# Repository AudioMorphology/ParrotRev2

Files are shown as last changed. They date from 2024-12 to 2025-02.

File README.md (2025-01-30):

# Parrot

##  Overview

Parrot is a 12hp Eurorack digital delay powered by a Raspberry Pi Pico microcontroller.

The objective is to provide a CD-Quality audio delay  / reverb effect, with a reasonably 
low BOM count

It utilises an 8Mb x 8-Bit (64mBit) PSRAM Memory chip (the AP6404L), and the whole of
this is treated as a 2Mb x 32-Bit audio buffer. This means that we can wrap the read and 
write pointers  with a simple logical &. 

2Mb x 32-Bit is 1Mb at 32-Bit Stereo. At a 48kHz sample rate, this gives a maximum delay 
time of 1,048,576 / 48,000 = 21.84 seconds 

The ADC and DAC ICs communicate over the i2S protocol, which is handled by custom PIO
functions.

They are actually 24-Bit devices with the data being transmitted left-justified in 32-Bit 
frames, so I am rightshifting to get 24-Bit Integers, then converting these to normalised
floats in the range -1.0 to +1.0 then, after processing it does the same in reverse before 
sending the audio data out to the DAC. 

Reading and writing to the PSRAM buffer is double-buffered using DMA calls from the I2S
interface.

It uses two PIO State machines:

PIO0 for SPI
PIO1 for I2S

The ADC and DAC utilises the low-cost and readily-available I2S modules, which have the 
advantages of already including various ancilliary components, which further reduces the
component count and complexity.

## NOTICE

This code incorporates and acknowledges the following:

### rp2040-psram Copyright © 2023 Ian Scott

rp2040-psram is a header-only library, which implements the SPI protocol using the rp2040 PIO
rather than the in-built SPI interface. This gives far better performance for PSRAM SPI peripherals

### i2s Copyright © 2022 Daniel Collins

These functions implement the I2S protocol using the rp2040 PIO. and utilise interrupt-driven
DMA double-buffering for Audio I/O.

### Elements of hardware design Copyright © 2012 Emilie Gillet (emilie.o.gillet@gmail.com)

The input and output buffer circuitry was taken directly from Clouds:
https://github.com/pichenettes/eurorack/tree/master/clouds/hardware_design/pcb

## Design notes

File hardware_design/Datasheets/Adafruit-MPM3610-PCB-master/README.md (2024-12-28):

## Adafruit MPM3610 3.3V & 5V Buck Converter Breakout PCB

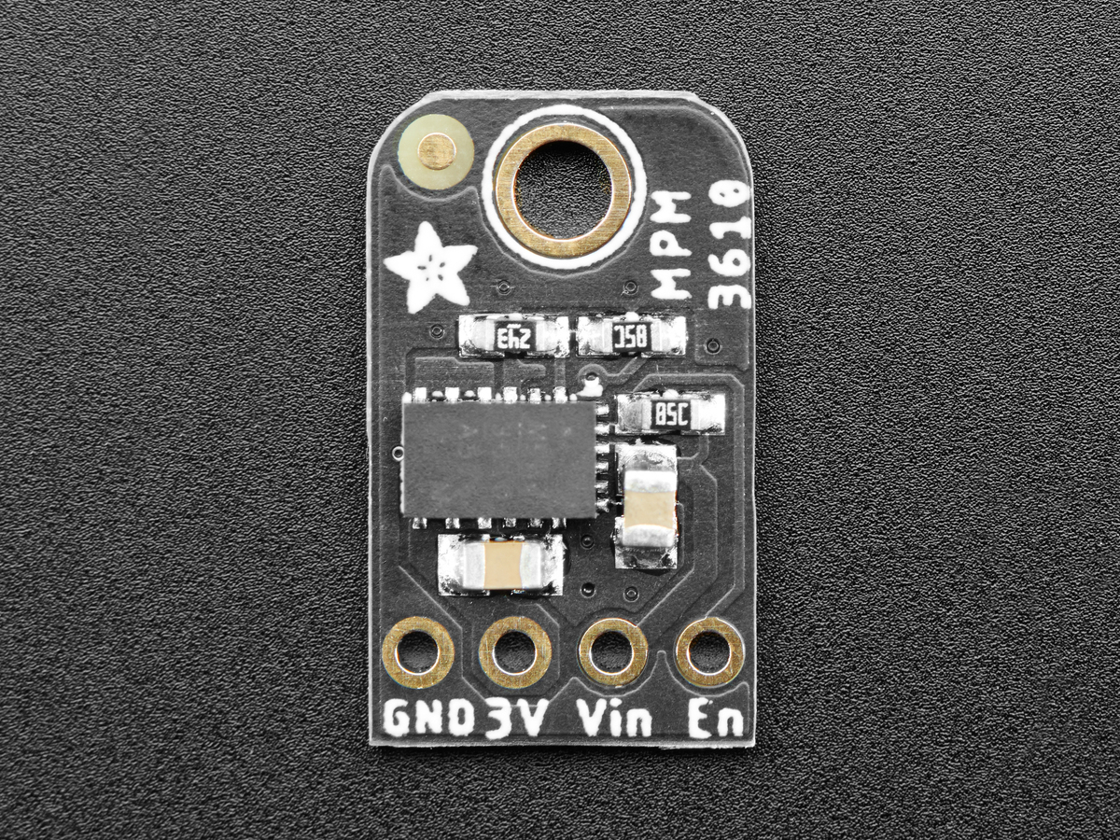
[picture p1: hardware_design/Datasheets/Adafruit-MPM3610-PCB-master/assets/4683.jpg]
<a href="http://www.adafruit.com/products/4683"><br/>
Click here to purchase one from the Adafruit shop</a>

PCB files for the Adafruit MPM3610 3.3V & 5V Buck Converter Breakout.

Format is EagleCAD schematic and board layout
* https://www.adafruit.com/product/4683
* https://www.adafruit.com/product/4739

### Description

Adafruit MPM3610 3.3V and 5V Buck Converter Breakout. The files for both are the same, the only difference is on the 5V version, R1 & R2 are 100K and R3 is 18.7K and on the 3.3V version, R1 & R2 are 75 and R3 is 24K

### License

Adafruit invests time and resources providing this open source design, please support Adafruit and open-source hardware by purchasing products from [Adafruit](https://www.adafruit.com)!

Designed by Limor Fried/Ladyada for Adafruit Industries.

Creative Commons Attribution/Share-Alike, all text above must be included in any redistribution.
See license.txt for additional details.

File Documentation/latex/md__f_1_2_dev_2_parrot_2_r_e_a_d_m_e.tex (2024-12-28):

\chapter{Parrot}
\hypertarget{md__f_1_2_dev_2_parrot_2_r_e_a_d_m_e}{}\label{md__f_1_2_dev_2_parrot_2_r_e_a_d_m_e}\index{Parrot@{Parrot}}
\label{md__f_1_2_dev_2_parrot_2_r_e_a_d_m_e_autotoc_md0}%
\Hypertarget{md__f_1_2_dev_2_parrot_2_r_e_a_d_m_e_autotoc_md0}%
 \hypertarget{md__f_1_2_dev_2_parrot_2_r_e_a_d_m_e_autotoc_md1}{}\doxysection{\texorpdfstring{Overview}{Overview}}\label{md__f_1_2_dev_2_parrot_2_r_e_a_d_m_e_autotoc_md1}
Parrot is a 12hp Eurorack digital delay powered by a Raspberry Pi Pico microcontroller.

The objective is to provide a CD-\/\+Quality audio delay / reverb effect, with a reasonably low BOM count

It utilises an 8Mb x 8-\/Bit (64m\+Bit) PSRAM Memory chip (the AP6404L), and the whole of this is treated as a 2Mb x 32-\/Bit audio buffer. This means that we can wrap the read and write pointers with a simple logical \&.

2Mb x 32-\/Bit is 1Mb at 32-\/Bit Stereo. At a 48k\+Hz sample rate, this gives a maximum delay time of 1,048,576 / 48,000 = 21.\+84 seconds

The ADC and DAC ICs communicate over the i2S protocol, which is handled by custom PIO functions.

Reading and writing to the PSRAM buffer is double-\/buffered using DMA calls from the I2S interface.

It uses two PIO State machines\+:

PIO0 for SPI PIO1 for I2S

The ADC and DAC utilises the low-\/cost and readily-\/available I2S modules, which have the advantages of already including various ancilliary components, which further reduces the component count and complexity.\hypertarget{md__f_1_2_dev_2_parrot_2_r_e_a_d_m_e_autotoc_md2}{}\doxysection{\texorpdfstring{NOTICE}{NOTICE}}\label{md__f_1_2_dev_2_parrot_2_r_e_a_d_m_e_autotoc_md2}
This code incorporates and acknowledges the following\+:\hypertarget{md__f_1_2_dev_2_parrot_2_r_e_a_d_m_e_autotoc_md3}{}\doxysubsection{\texorpdfstring{rp2040-\/psram Copyright © 2023 Ian Scott}{rp2040-\/psram Copyright © 2023 Ian Scott}}\label{md__f_1_2_dev_2_parrot_2_r_e_a_d_m_e_autotoc_md3}
rp2040-\/psram is a header-\/only library, which implements the SPI protocol using the rp2040 PIO rather than the in-\/built SPI interface. This gives far better performance for PSRAM SPI peripherals\hypertarget{md__f_1_2_dev_2_parrot_2_r_e_a_d_m_e_autotoc_md4}{}\doxysubsection{\texorpdfstring{i2s Copyright (c) 2022 Daniel Collins}{i2s Copyright (c) 2022 Daniel Collins}}\label{md__f_1_2_dev_2_parrot_2_r_e_a_d_m_e_autotoc_md4}
These functions implement the I2S protocol using the rp2040 PIO. and utilise interrupt-\/driven DMA double-\/buffering for Audio I/O.\hypertarget{md__f_1_2_dev_2_parrot_2_r_e_a_d_m_e_autotoc_md5}{}\doxysubsection{\texorpdfstring{Elements of hardware design Copyright 2012 Emilie Gillet (\href{mailto:emilie.o.gillet@gmail.com}{\texttt{ emilie.\+o.\+gillet@gmail.\+com}})}{Elements of hardware design Copyright 2012 Emilie Gillet (\href{mailto:emilie.o.gillet@gmail.com}{\texttt{ emilie.\+o.\+gillet@gmail.\+com}})}}\label{md__f_1_2_dev_2_parrot_2_r_e_a_d_m_e_autotoc_md5}
The input and output buffer circuitry was taken directly from Clouds\+: \href{https://github.com/pichenettes/eurorack/tree/master/clouds/hardware_design/pcb}{\texttt{ https\+://github.\+com/pichenettes/eurorack/tree/master/clouds/hardware\+\_\+design/pcb}}

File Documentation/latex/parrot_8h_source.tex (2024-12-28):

\doxysection{parrot.\+h}
\hypertarget{parrot_8h_source}{}\label{parrot_8h_source}\index{F:/Dev/Parrot/parrot.h@{F:/Dev/Parrot/parrot.h}}
\mbox{\hyperlink{parrot_8h}{Go to the documentation of this file.}}
\begin{DoxyCode}{0}
\DoxyCodeLine{00001\ \textcolor{comment}{/******************************************************************************}}
\DoxyCodeLine{00002\ \textcolor{comment}{}}
\DoxyCodeLine{00003\ \textcolor{comment}{parrot}}
\DoxyCodeLine{00004\ \textcolor{comment}{}}
\DoxyCodeLine{00005\ \textcolor{comment}{Copyright\ ©\ 2024\ Richard\ R.\ Goodwin\ /\ Audio\ Morphology\ Ltd.}}
\DoxyCodeLine{00006\ \textcolor{comment}{}}
\DoxyCodeLine{00007\ \textcolor{comment}{Permission\ is\ hereby\ granted,\ free\ of\ charge,\ to\ any\ person\ obtaining\ a\ copy\ of}}
\DoxyCodeLine{00008\ \textcolor{comment}{this\ software\ and\ associated\ documentation\ files\ (the\ “Software”),\ to\ deal\ in}}
\DoxyCodeLine{00009\ \textcolor{comment}{the\ Software\ without\ restriction,\ including\ without\ limitation\ the\ rights\ to}}
\DoxyCodeLine{00010\ \textcolor{comment}{use,\ copy,\ modify,\ merge,\ publish,\ distribute,\ sublicense,\ and/or\ sell\ copies}}
\DoxyCodeLine{00011\ \textcolor{comment}{of\ the\ Software,\ and\ to\ permit\ persons\ to\ whom\ the\ Software\ is\ furnished\ to\ do}}
\DoxyCodeLine{00012\ \textcolor{comment}{so,\ subject\ to\ the\ following\ conditions:}}
\DoxyCodeLine{00013\ \textcolor{comment}{}}
\DoxyCodeLine{00014\ \textcolor{comment}{The\ above\ copyright\ notice\ and\ this\ permission\ notice\ shall\ be\ included\ in\ all}}
\DoxyCodeLine{00015\ \textcolor{comment}{copies\ or\ substantial\ portions\ of\ the\ Software.}}
\DoxyCodeLine{00016\ \textcolor{comment}{}}
\DoxyCodeLine{00017\ \textcolor{comment}{THE\ SOFTWARE\ IS\ PROVIDED\ “AS\ IS”,\ WITHOUT\ WARRANTY\ OF\ ANY\ KIND,\ EXPRESS\ OR}}
\DoxyCodeLine{00018\ \textcolor{comment}{IMPLIED,\ INCLUDING\ BUT\ NOT\ LIMITED\ TO\ THE\ WARRANTIES\ OF\ MERCHANTABILITY,}}
\DoxyCodeLine{00019\ \textcolor{comment}{FITNESS\ FOR\ A\ PARTICULAR\ PURPOSE\ AND\ NONINFRINGEMENT.\ IN\ NO\ EVENT\ SHALL\ THE}}
\DoxyCodeLine{00020\ \textcolor{comment}{AUTHORS\ OR\ COPYRIGHT\ HOLDERS\ BE\ LIABLE\ FOR\ ANY\ CLAIM,\ DAMAGES\ OR\ OTHER}}
\DoxyCodeLine{00021\ \textcolor{comment}{LIABILITY,\ WHETHER\ IN\ AN\ ACTION\ OF\ CONTRACT,\ TORT\ OR\ OTHERWISE,\ ARISING\ FROM,}}
\DoxyCodeLine{00022\ \textcolor{comment}{OUT\ OF\ OR\ IN\ CONNECTION\ WITH\ THE\ SOFTWARE\ OR\ THE\ USE\ OR\ OTHER\ DEALINGS\ IN\ THE}}
\DoxyCodeLine{00023\ \textcolor{comment}{SOFTWARE.}}
\DoxyCodeLine{00024\ \textcolor{comment}{}}
\DoxyCodeLine{00025\ \textcolor{comment}{******************************************************************************/}}
\DoxyCodeLine{00031\ \textcolor{preprocessor}{\#ifndef\ PARROT\_H}}
\DoxyCodeLine{00032\ \textcolor{preprocessor}{\#define\ PARROT\_H}}
\DoxyCodeLine{00033\ \textcolor{preprocessor}{\#include\ "{}psram\_spi.h"{}}}
\DoxyCodeLine{00034\ \textcolor{comment}{//\ To\ Do\ -\/\ is\ it\ OK\ to\ hard\ code\ these,\ or\ should\ they\ be\ }}
\DoxyCodeLine{00035\ \textcolor{comment}{//\ dynamically\ assigned\ from\ an\ alarm\ \&\ IRQ\ pool?}}
\DoxyCodeLine{00036\ \textcolor{preprocessor}{\#define\ ALARM\_NUM\ 1}}
\DoxyCodeLine{00037\ \textcolor{preprocessor}{\#define\ ALARM\_IRQ\ TIMER\_IRQ\_1}}
\DoxyCodeLine{00044\ \textcolor{keyword}{typedef}\ \textcolor{keywordtype}{signed}\ \textcolor{keywordtype}{int}\ \mbox{\hyperlink{parrot_8h_a6bdff0bc03d24ec80e07d29f92a4d8a8}{s15x16}};}
\DoxyCodeLine{00045\ \textcolor{preprocessor}{\#define\ muls15x16(a,b)\ ((s15x16)((((\ signed\ long\ long\ )(a))*((\ signed\ long\ long\ )(b)))>>16))\ }\textcolor{comment}{//multiply\ two\ fixed\ 16:16}}
\DoxyCodeLine{00046\ \textcolor{preprocessor}{\#define\ float\_to\_s15x16(a)\ ((s15x16)((a)*65536.0))\ }\textcolor{comment}{//\ 2\string^16}}
\DoxyCodeLine{00047\ \textcolor{preprocessor}{\#define\ s15x16\_to\_float(a)\ ((float)(a)/65536.0)}}
\DoxyCodeLine{00048\ \textcolor{preprocessor}{\#define\ s15x16\_to\_int(a)\ \ \ \ ((int)((a)>>16))}}
\DoxyCodeLine{00049\ \textcolor{preprocessor}{\#define\ int\_to\_s15x16(a)\ \ \ \ ((s15x16)((a)<<16))}}
\DoxyCodeLine{00050\ \textcolor{preprocessor}{\#define\ divs15x16(a,b)\ ((s15x16)((((signed\ long\ long)(a)<<16)/(b))))\ }}
\DoxyCodeLine{00051\ \textcolor{preprocessor}{\#define\ abss15x16(a)\ abs(a)}}
\DoxyCodeLine{00052\ \textcolor{comment}{//\ and\ for\ 1.14}}
\DoxyCodeLine{00053\ \textcolor{keyword}{typedef}\ \textcolor{keywordtype}{signed}\ \textcolor{keywordtype}{short}\ s1x14\ ;}
\DoxyCodeLine{00054\ \textcolor{preprocessor}{\#define\ muls1x14(a,b)\ ((s1x14)((((int)(a))*((int)(b)))>>14))\ }}
\DoxyCodeLine{00055\ \textcolor{preprocessor}{\#define\ float\_to\_s1x14(a)\ ((s1x14)((a)*16384.0))\ }\textcolor{comment}{//\ 2\string^14}}
\DoxyCodeLine{00056\ \textcolor{preprocessor}{\#define\ s1x14\_to\_float(a)\ ((float)(a)/16384.0)}}
\DoxyCodeLine{00057\ \textcolor{preprocessor}{\#define\ abss1x14(a)\ abs(a)\ }}
\DoxyCodeLine{00058\ \textcolor{preprocessor}{\#define\ divs1x14(a,b)\ ((s1x14)((((signed\ int)(a)<<14)/(b))))\ }}
\DoxyCodeLine{00059\ \textcolor{comment}{//\ Int\ to\ float}}
\DoxyCodeLine{00060\ \textcolor{preprocessor}{\#define\ float\_to\_int(x)\ (((int)\ ((x\ *\ 8388607)\ +\ 8388608.5f))\ -\/\ 8388608)}}
\DoxyCodeLine{00061\ \textcolor{preprocessor}{\#define\ float\_to\_int32(x)\ (((int)\ ((x\ *\ 2147483647)\ +\ 2147483648.5f))\ -\/\ 2147483648)}}
\DoxyCodeLine{00062\ \textcolor{preprocessor}{\#define\ int\_to\_float(x)\ ((((float)\ (x\ +\ 8388608))\ -\/\ 8388608.5f)\ /\ 8388607.f)}}
\DoxyCodeLine{00063\ \textcolor{preprocessor}{\#define\ int32\_to\_float(x)\ ((((float)\ (x\ +\ 2147483648))\ -\/\ 2147483648.5f)\ /\ 2147483648.f)}}
\DoxyCodeLine{00072\ \textcolor{keyword}{union\ }\mbox{\hyperlink{unionu_sample}{uSample}}\ \{}
\DoxyCodeLine{00073\ \ \ \ \ \textcolor{keywordtype}{float}\ fSample;}
\DoxyCodeLine{00074\ \ \ \ \ int32\_t\ iSample;}
\DoxyCodeLine{00075\ \};}
\DoxyCodeLine{00076\ }
\DoxyCodeLine{00077\ \textcolor{comment}{//\ Global\ Variables\ -\/\ Constants}}
\DoxyCodeLine{00078\ \textcolor{keyword}{static}\ \textcolor{keyword}{const}\ \textcolor{keywordtype}{double}\ ClockScale\ =\ 0.04884;\ \ \ \ \ \ \ \textcolor{comment}{//\ (=\ (240-\/40)/4095)\ scales\ the\ internal\ clock\ BPM\ from\ 40\ to\ 240BPM}}
\DoxyCodeLine{00079\ \textcolor{keyword}{static}\ \textcolor{keyword}{const}\ uint\ Clock\_MA\_Len\ =\ 3;\ \ \ \ \ \ \ \ \ \ \ \ \ \textcolor{comment}{//\ Length\ of\ the\ Clock\ Pot\ Moving\ Average\ buffer}}
\DoxyCodeLine{00080\ \textcolor{keyword}{static}\ \textcolor{keyword}{const}\ uint\ WetDry\_MA\_Len\ =\ 5;\ \ \ \ \ \ \ \ \ \ \ \ \textcolor{comment}{//\ Length\ of\ the\ Wet/Dry\ pot\ MA\ buffer}}
\DoxyCodeLine{00081\ \textcolor{keyword}{static}\ \textcolor{keyword}{const}\ uint\ ExtClock\_MA\_Len\ =\ 10;\ \ \ \ \ \ \ \ \ \textcolor{comment}{//\ Length\ of\ the\ ExtClock\ Moving\ Average\ buffer\ (to\ filter\ out\ timing\ irregularities)}}
\DoxyCodeLine{00082\ \textcolor{keyword}{static}\ \textcolor{keyword}{const}\ uint32\_t\ ClockHysteresis\ =\ 0xFF;\ \ \ \textcolor{comment}{//\ +/-\/\ Amount\ the\ clock\ has\ to\ vary\ before\ we\ note\ a\ new\ clock\ period\ (to\ overcome\ jitter)}}
\DoxyCodeLine{00083\ \textcolor{keyword}{static}\ \textcolor{keyword}{const}\ \textcolor{keywordtype}{float}\ Feedback\_scale\ =\ 0.0002442;\ \ \textcolor{comment}{//\ (=\ 1/4095\ )fixed\ scale\ factor\ to\ scale\ the\ Feedback\ ADC\ value\ to\ give\ a\ Percentage\ feedback\ from\ 0\ to\ 1}}
\DoxyCodeLine{00084\ \textcolor{keyword}{static}\ \textcolor{keyword}{const}\ \textcolor{keywordtype}{float}\ WetDry\_Scale\ =\ 0.02442;\ \ \ \ \ \ \textcolor{comment}{//\ (=\ 100/4095)fixed\ scale\ factor\ to\ scale\ the\ Divisor\ ADC\ value\ to\ give\ a\ value\ from\ 0\ to\ 100}}
\DoxyCodeLine{00085\ \textcolor{keyword}{static}\ \textcolor{keyword}{const}\ \textcolor{keywordtype}{float}\ SampleLength\ =\ 1000000.0f/96000.0f;\ \textcolor{comment}{//\ Length\ of\ 1\ stereo\ sample\ in\ uS\ (10.4166ms).\ \ }}
\DoxyCodeLine{00086\ \textcolor{keyword}{static}\ \textcolor{keyword}{const}\ uint\ Feedback\_MA\_Len\ =\ 3;\ \ \ \ \ \ \ \ \ \ \textcolor{comment}{//\ Length\ of\ the\ Feedback\ Moving\ Average\ ring\ buffer}}
\DoxyCodeLine{00087\ \textcolor{keyword}{static}\ \textcolor{keyword}{const}\ uint\ Tick\_MA\_Len\ =\ 1;\ \ \ \ \ \ \ \ \ \ \ \ \ \ \textcolor{comment}{//\ Length\ of\ the\ Rotary\ Encoder\ tick\ speed\ Moving\ Average\ ring\ buffer}}
\DoxyCodeLine{00088\ \textcolor{keyword}{static}\ \textcolor{keyword}{const}\ uint32\_t\ BUF\_LEN\ =\ 0x7FFFFC;\ \ \ \ \ \ \ \textcolor{comment}{//\ Actual\ Audio\ Buffer\ length\ in\ Mb\ =\ 8Mb.\ }}
\DoxyCodeLine{00089\ \textcolor{comment}{//\ GPIO\ Pin\ definitions}}
\DoxyCodeLine{00090\ \textcolor{keyword}{static}\ \textcolor{keyword}{const}\ uint\ ALGORITHM\_0\ =\ 0;\ \ \ \ \ \ \ \ \ \ \ \ \ \ \textcolor{comment}{//\ LSB\ of\ Algorithm\ 4-\/Way\ BCD\ Switch\ Physical\ Pin\ 1}}
\DoxyCodeLine{00091\ \textcolor{keyword}{static}\ \textcolor{keyword}{const}\ uint\ ALGORITHM\_1\ =\ 1;\ \ \ \ \ \ \ \ \ \ \ \ \ \ \textcolor{comment}{//\ MSB\ of\ Algorithm\ 4-\/Way\ BCD\ Switch\ Physical\ Pin\ 2}}
\DoxyCodeLine{00092\ \textcolor{keyword}{static}\ \textcolor{keyword}{const}\ uint\ DIVISOR\_A\ =\ 2;\ \ \ \ \ \ \ \ \ \ \ \ \ \ \ \ \textcolor{comment}{//\ 16-\/Way\ BCD\ switch-\/A\ \ \ \ Physical\ Pin\ 4}}
\DoxyCodeLine{00093\ \textcolor{keyword}{static}\ \textcolor{keyword}{const}\ uint\ DIVISOR\_B\ =\ 3;\ \ \ \ \ \ \ \ \ \ \ \ \ \ \ \ \textcolor{comment}{//\ 16-\/Way\ BCD\ switch-\/B\ \ \ \ Physical\ Pin\ 5}}
\DoxyCodeLine{00094\ \textcolor{keyword}{static}\ \textcolor{keyword}{const}\ uint\ DIVISOR\_C\ =\ 4;\ \ \ \ \ \ \ \ \ \ \ \ \ \ \ \ \textcolor{comment}{//\ 16-\/Way\ BCD\ switch-\/C\ \ \ \ Physical\ Pin\ 6}}
\DoxyCodeLine{00095\ \textcolor{keyword}{static}\ \textcolor{keyword}{const}\ uint\ DIVISOR\_D\ =\ 5;\ \ \ \ \ \ \ \ \ \ \ \ \ \ \ \ \textcolor{comment}{//\ 16-\/Way\ BCD\ switch-\/D\ \ \ \ Physical\ Pin\ 7}}
\DoxyCodeLine{00096\ \textcolor{keyword}{static}\ \textcolor{keyword}{const}\ uint\ I2S\_DOUT\ =\ 6;\ \ \ \ \ \ \ \ \ \ \ \ \ \ \ \ \ \textcolor{comment}{//\ I2S\ Data\ Out}}
\DoxyCodeLine{00097\ \textcolor{keyword}{static}\ \textcolor{keyword}{const}\ uint\ I2S\_DIN\ =\ 7;\ \ \ \ \ \ \ \ \ \ \ \ \ \ \ \ \ \ \textcolor{comment}{//\ I2S\ Data\ In}}
\DoxyCodeLine{00098\ \textcolor{keyword}{static}\ \textcolor{keyword}{const}\ uint\ I2S\_BCK\ =\ 8;\ \ \ \ \ \ \ \ \ \ \ \ \ \ \ \ \ \ \textcolor{comment}{//\ I2S\ Bit\ Clock}}
\DoxyCodeLine{00099\ \textcolor{keyword}{static}\ \textcolor{keyword}{const}\ uint\ I2S\_LRCK\ =\ 9;\ \ \ \ \ \ \ \ \ \ \ \ \ \ \ \ \ \textcolor{comment}{//\ I2S\ Left-\/Right\ Clock}}
\DoxyCodeLine{00100\ \textcolor{keyword}{static}\ \textcolor{keyword}{const}\ uint\ I2S\_SCK\ =\ 10;\ \ \ \ \ \ \ \ \ \ \ \ \ \ \ \ \ \textcolor{comment}{//\ I2S\ System\ Clock}}
\DoxyCodeLine{00101\ \textcolor{keyword}{static}\ \textcolor{keyword}{const}\ uint\ LED\_PIN\ =\ 11;\ \ \ \ \ \ \ \ \ \ \ \ \ \ \ \ \ \textcolor{comment}{//\ LED\ \ \ \ \ \ \ \ \ \ \ \ \ \ \ \ \ \ \ physical\ pin\ 15}}
\DoxyCodeLine{00102\ \textcolor{keyword}{static}\ \textcolor{keyword}{const}\ uint\ XSMT\_PIN\ =\ 12;\ \ \ \ \ \ \ \ \ \ \ \ \ \ \ \ \textcolor{comment}{//\ PCM5102\ Soft-\/mute\ \ \ \ \ Physical\ Pin\ 16\ }}
\DoxyCodeLine{00103\ \textcolor{keyword}{static}\ \textcolor{keyword}{const}\ uint\ ENCODER\_SW\ =\ 13;\ \ \ \ \ \ \ \ \ \ \ \ \ \ \textcolor{comment}{//\ Rotary\ Encoder\ switch\ Physical\ pin\ 17}}
\DoxyCodeLine{00104\ \textcolor{keyword}{static}\ \textcolor{keyword}{const}\ uint\ ENCODERA\_IN\ =\ 14;\ \ \ \ \ \ \ \ \ \ \ \ \ \textcolor{comment}{//\ Rotary\ encoder\ A-\/leg\ \ physical\ pin\ 20\ }}
\DoxyCodeLine{00105\ \textcolor{keyword}{static}\ \textcolor{keyword}{const}\ uint\ ENCODERB\_IN\ =\ 15;\ \ \ \ \ \ \ \ \ \ \ \ \ \textcolor{comment}{//\ Rotary\ encoder\ B-\/leg\ \ physical\ pin\ 21}}
\DoxyCodeLine{00106\ \textcolor{keyword}{static}\ \textcolor{keyword}{const}\ uint\ SPI\_CS\ =\ 16;\ \ \ \ \ \ \ \ \ \ \ \ \ \ \ \ \ \ \textcolor{comment}{//\ SPI\ Chip\ Select}}
\DoxyCodeLine{00107\ \textcolor{keyword}{static}\ \textcolor{keyword}{const}\ uint\ SPI\_SCK\ =\ 17;\ \ \ \ \ \ \ \ \ \ \ \ \ \ \ \ \ \textcolor{comment}{//\ SPI\ Serial\ Clock}}
\DoxyCodeLine{00108\ \textcolor{keyword}{static}\ \textcolor{keyword}{const}\ uint\ SPI\_MOSI\ =\ 19;\ \ \ \ \ \ \ \ \ \ \ \ \ \ \ \ \textcolor{comment}{//\ SPI\ Master\ Out\ Slave\ In}}
\DoxyCodeLine{00109\ \textcolor{keyword}{static}\ \textcolor{keyword}{const}\ uint\ SPI\_MISO\ =\ 20;\ \ \ \ \ \ \ \ \ \ \ \ \ \ \ \ \textcolor{comment}{//\ SPI\ Master\ In\ Slave\ Out}}
\DoxyCodeLine{00110\ \textcolor{keyword}{static}\ \textcolor{keyword}{const}\ uint\ SYNC\_PIN\ =\ 20;\ \ \ \ \ \ \ \ \ \ \ \ \ \ \ \ \textcolor{comment}{//\ Delay\ sync'd\ to\ clock\ physical\ pin\ 26}}
\DoxyCodeLine{00111\ \textcolor{keyword}{static}\ \textcolor{keyword}{const}\ uint\ CLOCK\_OUT\ =\ 21;\ \ \ \ \ \ \ \ \ \ \ \ \ \ \ \textcolor{comment}{//\ Internal\ clock\ out\ \ \ \ physical\ pin\ 27}}
\DoxyCodeLine{00112\ \textcolor{keyword}{static}\ \textcolor{keyword}{const}\ uint\ CLOCK\_IN\ =\ 22;\ \ \ \ \ \ \ \ \ \ \ \ \ \ \ \ \textcolor{comment}{//\ External\ clock\ in\ \ \ \ \ physical\ pin\ 29}}
\DoxyCodeLine{00113\ \textcolor{keyword}{static}\ \textcolor{keyword}{const}\ uint\ POWERSAVE\_PIN\ =\ 23;\ \ \ \ \ \ \ \ \ \ \ \textcolor{comment}{//\ Set\ high\ turns\ on\ PWM\ mode\ the\ internal\ 3v3\ regulator,\ which\ reduces\ noise\ }}
\DoxyCodeLine{00114\ \textcolor{keyword}{static}\ \textcolor{keyword}{const}\ uint\ VBUS\_SENSE\ =\ 24;\ \ \ \ \ \ \ \ \ \ \ \ \ \ \textcolor{comment}{//\ High\ if\ VBUS\ is\ present,\ low\ otherwise}}
\DoxyCodeLine{00115\ \textcolor{keyword}{static}\ \textcolor{keyword}{const}\ uint\ ONBOARD\_LED\ =\ 25;\ \ \ \ \ \ \ \ \ \ \ \ \ \textcolor{comment}{//\ On-\/Board\ LED}}
\DoxyCodeLine{00116\ \textcolor{keyword}{static}\ \textcolor{keyword}{const}\ uint\ FEEDBACK\_PIN\ =\ 26;\ \ \ \ \ \ \ \ \ \ \ \ \textcolor{comment}{//\ feedback\ amount\ \ \ \ \ \ \ physical\ pin\ 31\ (ADC0\ Input)}}
\DoxyCodeLine{00117\ \textcolor{keyword}{static}\ \textcolor{keyword}{const}\ uint\ CLOCKSPEED\_PIN\ =\ 27;\ \ \ \ \ \ \ \ \ \ \textcolor{comment}{//\ Clock\ Speed\ \ \ \ \ \ \ \ \ \ \ physical\ pin\ 32\ (ADC1\ Input)}}
\DoxyCodeLine{00118\ \textcolor{keyword}{static}\ \textcolor{keyword}{const}\ uint\ WETDRY\_PIN\ =\ 28;\ \ \ \ \ \ \ \ \ \ \ \ \ \ \textcolor{comment}{//\ Wet/Dry\ control\ \ \ \ \ \ \ physical\ pin\ 34\ (ADC2\ Input)}}
\DoxyCodeLine{00119\ \textcolor{comment}{//\ ADC\ Channels}}
\DoxyCodeLine{00120\ \textcolor{keyword}{static}\ \textcolor{keyword}{const}\ uint\ ADC\_feedback\ =\ 0;}
\DoxyCodeLine{00121\ \textcolor{keyword}{static}\ \textcolor{keyword}{const}\ uint\ ADC\_Clock\ =\ 1;}
\DoxyCodeLine{00122\ \textcolor{keyword}{static}\ \textcolor{keyword}{const}\ uint\ ADC\_WetDry\ =\ 2;\ }
\DoxyCodeLine{00123\ \textcolor{comment}{//\ AP\ 6404L\ Constants}}
\DoxyCodeLine{00124\ \textcolor{keyword}{static}\ \textcolor{keyword}{const}\ uint8\_t\ AP6404\_READ\ =\ 0x03;\ \ \ \ \ \ \ \ \textcolor{comment}{//\ Read}}
\DoxyCodeLine{00125\ \textcolor{keyword}{static}\ \textcolor{keyword}{const}\ uint8\_t\ AP6404\_FREAD\ =\ 0x0B;\ \ \ \ \ \ \ \textcolor{comment}{//\ Fast\ Read}}
\DoxyCodeLine{00126\ \textcolor{keyword}{static}\ \textcolor{keyword}{const}\ uint8\_t\ AP6404\_WRITE\ =\ 0x02;\ \ \ \ \ \ \ \textcolor{comment}{//\ Write}}
\DoxyCodeLine{00127\ \textcolor{keyword}{static}\ \textcolor{keyword}{const}\ uint8\_t\ AP6404\_RST\_EN\ =\ 0x66;\ \ \ \ \ \ \textcolor{comment}{//\ Reset\ Enable}}
\DoxyCodeLine{00128\ \textcolor{keyword}{static}\ \textcolor{keyword}{const}\ uint8\_t\ AP6404\_RESET\ =\ 0x99;\ \ \ \ \ \ \ \textcolor{comment}{//\ Reset}}
\DoxyCodeLine{00129\ \textcolor{keyword}{static}\ \textcolor{keyword}{const}\ uint8\_t\ AP6404\_WBT\ =\ 0xC0;\ \ \ \ \ \ \ \ \ \textcolor{comment}{//\ Wrap\ Boundary\ Toggle\ \ }}
\DoxyCodeLine{00130\ \textcolor{keyword}{static}\ \textcolor{keyword}{const}\ uint8\_t\ AP6404\_READID\ =\ 0x9F;\ \ \ \ \ \ \textcolor{comment}{//\ Read\ ID}}
\DoxyCodeLine{00131\ }
\DoxyCodeLine{00132\ \textcolor{comment}{//\ Global\ Variables\ defined\ in\ parrot\_main.c}}
\DoxyCodeLine{00133\ \textcolor{keyword}{extern}\ \textcolor{keywordtype}{double}\ ClockBPM;\ \ \ \ \ \ \ \ \ \ \ \ \textcolor{comment}{//\ BPM\ Value\ for\ interal\ clock}}
\DoxyCodeLine{00134\ \textcolor{keyword}{extern}\ \textcolor{keywordtype}{double}\ ClockFreq;\ \ \ \ \ \ \ \ \ \ \ \textcolor{comment}{//\ Internal\ Clock\ Frequency}}
\DoxyCodeLine{00135\ \textcolor{keyword}{extern}\ \textcolor{keywordtype}{double}\ ClockPeriod;\ \ \ \ \ \ \ \ \ \textcolor{comment}{//\ Internal\ Clock\ Period}}
\DoxyCodeLine{00136\ \textcolor{keyword}{extern}\ uint32\_t\ ReadPointer;\ }
\DoxyCodeLine{00137\ \textcolor{keyword}{extern}\ uint32\_t\ WritePointer;}
\DoxyCodeLine{00138\ \textcolor{keyword}{extern}\ \textcolor{keywordtype}{float}\ glbFeedback;}
\DoxyCodeLine{00139\ \textcolor{keyword}{extern}\ \textcolor{keywordtype}{float}\ glbDivisor;}
\DoxyCodeLine{00140\ \textcolor{keyword}{extern}\ \textcolor{keywordtype}{float}\ \mbox{\hyperlink{parrot_8h_a5d8ff28893901c00f6792c86ecb5bd01}{divisors}}[];}
\DoxyCodeLine{00141\ \textcolor{keyword}{extern}\ \textcolor{keywordtype}{int}\ Algorithm;}
\DoxyCodeLine{00142\ }
\DoxyCodeLine{00143\ \textcolor{comment}{//\ \ Global\ variables\ defined\ in\ parrot\_core1.c}}
\DoxyCodeLine{00144\ \textcolor{keyword}{extern}\ \_Atomic\ int32\_t\ ExtClockPeriod;\ \ \ \ \ \textcolor{comment}{//\ External\ Clock\ Period\ (rising\ edge\ to\ rising\ edge)}}
\DoxyCodeLine{00145\ \textcolor{keyword}{extern}\ \_Atomic\ int32\_t\ ExtClockTick;\ \ \ \ \ \ \ \textcolor{comment}{//\ Records\ the\ last\ tick\ for\ the\ External\ Clock}}
\DoxyCodeLine{00146\ \textcolor{keyword}{extern}\ uint32\_t\ glbDelay;}
\DoxyCodeLine{00147\ \textcolor{keyword}{extern}\ uint32\_t\ targetDelay;}
\DoxyCodeLine{00148\ \textcolor{keyword}{extern}\ int32\_t\ PreviousClockPeriod;}
\DoxyCodeLine{00149\ \textcolor{keyword}{extern}\ uint32\_t\ glbIncrement;}
\DoxyCodeLine{00150\ \textcolor{keyword}{extern}\ int32\_t\ DelayDiff;}
\DoxyCodeLine{00151\ \textcolor{keyword}{extern}\ \textcolor{keywordtype}{float}\ glbWet;}
\DoxyCodeLine{00152\ \textcolor{keyword}{extern}\ \textcolor{keywordtype}{float}\ glbDry;}
\DoxyCodeLine{00153\ \textcolor{keyword}{extern}\ \textcolor{keywordtype}{int}\ spinlock\_num\_glbDelay;}
\DoxyCodeLine{00154\ \textcolor{keyword}{extern}\ spin\_lock\_t\ *spinlock\_glbDelay;}
\DoxyCodeLine{00155\ \textcolor{keyword}{extern}\ \textcolor{keywordtype}{int}\ ClockPhase;\ \ \ \ \ \ \ \ \ \ \ \ \ \textcolor{comment}{//\ Toggles\ between\ 0\ \&\ 1}}
\DoxyCodeLine{00156\ \textcolor{keyword}{extern}\ \textcolor{keywordtype}{int}\ LEDPhase;}
\DoxyCodeLine{00157\ \textcolor{keyword}{extern}\ \textcolor{keywordtype}{float}\ FeedbackPercent;}
\DoxyCodeLine{00158\ }
\DoxyCodeLine{00159\ \textcolor{comment}{//\ function\ prototypes\ -\/\ parrot\_core1.c}}
\DoxyCodeLine{00160\ \textcolor{keywordtype}{void}\ \mbox{\hyperlink{parrot_8h_a677531d0ec7a1f4b9b9d8ebb4b3d4521}{core1\_entry}}(\textcolor{keywordtype}{void});}
\DoxyCodeLine{00161\ }
\DoxyCodeLine{00162\ \textcolor{comment}{//\ function\ prototypes\ -\/\ parrot\_func.c}}
\DoxyCodeLine{00163\ \textcolor{keyword}{extern}\ psram\_spi\_inst\_t\ psram\_spi;}
\DoxyCodeLine{00164\ \textcolor{keywordtype}{float}\ \mbox{\hyperlink{parrot_8h_a782715f72de752446e670ca8536fd4fd}{single\_delay}}(\textcolor{keyword}{union}\ \mbox{\hyperlink{unionu_sample}{uSample}});}
\DoxyCodeLine{00165\ \textcolor{keywordtype}{float}\ \mbox{\hyperlink{parrot_8h_a9a421dffc23588ba1399035b42a635b3}{single\_tap}}(\textcolor{keyword}{union}\ \mbox{\hyperlink{unionu_sample}{uSample}},\ \textcolor{keywordtype}{float});}
\DoxyCodeLine{00166\ \textcolor{keywordtype}{float}\ \mbox{\hyperlink{parrot_8h_a931af3f4a4ce6b4d652cba2025fd5556}{Ping\_Pong}}(\textcolor{keyword}{union}\ \mbox{\hyperlink{unionu_sample}{uSample}},\ \textcolor{keywordtype}{float},\ \textcolor{keywordtype}{bool});}
\DoxyCodeLine{00167\ int32\_t\ single\_tap\_shift(int32\_t,\ uint32\_t,\ uint8\_t);}
\DoxyCodeLine{00177\ \_\_force\_inline\ \textcolor{keyword}{static}\ \textcolor{keywordtype}{float}\ WetDry(\textcolor{keywordtype}{float}\ DrySample,\ \textcolor{keywordtype}{float}\ WetSample)\{}
\DoxyCodeLine{00178\ \ \ \ \ \textcolor{keywordflow}{return}\ (DrySample\ *\ glbDry)\ +\ (WetSample\ *\ glbWet);\ }
\DoxyCodeLine{00179\ \}}
\DoxyCodeLine{00180\ }
\DoxyCodeLine{00181\ \textcolor{keywordtype}{float}\ \mbox{\hyperlink{parrot_8h_a7820a4fd83fffae49196ac19d501ecd6}{rational\_tanh}}(\textcolor{keywordtype}{float});}
\DoxyCodeLine{00182\ \textcolor{keywordtype}{float}\ \mbox{\hyperlink{parrot_8h_a1d4475a10532e87db4a30c3a082ddc90}{soft\_clip}}(\textcolor{keywordtype}{float});}
\DoxyCodeLine{00183\ }
\DoxyCodeLine{00184\ \textcolor{preprocessor}{\#endif}}

\end{DoxyCode}

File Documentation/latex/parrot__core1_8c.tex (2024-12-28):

\doxysection{F\+:/\+Dev/\+Parrot/parrot\+\_\+core1.c File Reference}
\hypertarget{parrot__core1_8c}{}\label{parrot__core1_8c}\index{F:/Dev/Parrot/parrot\_core1.c@{F:/Dev/Parrot/parrot\_core1.c}}
{\ttfamily \#include $<$stdio.\+h$>$}\newline
{\ttfamily \#include $<$math.\+h$>$}\newline
{\ttfamily \#include "{}parrot.\+h"{}}\newline
{\ttfamily \#include "{}pico/stdlib.\+h"{}}\newline
{\ttfamily \#include "{}pico/multicore.\+h"{}}\newline
{\ttfamily \#include "{}hardware/irq.\+h"{}}\newline
{\ttfamily \#include "{}hardware/adc.\+h"{}}\newline
{\ttfamily \#include "{}hardware/sync.\+h"{}}\newline
\doxysubsubsection*{Functions}
\begin{DoxyCompactItemize}
\item 
int8\+\_\+t \mbox{\hyperlink{parrot__core1_8c_afe21adbf567c42a41a4709480efb2125}{check\+Rotary\+Encoder}} ()
\begin{DoxyCompactList}\small\item\em Rotary Encoder finite state machine. \end{DoxyCompactList}\item 
void \mbox{\hyperlink{parrot__core1_8c_a66e3dbe6039c9461b397296f63ff685a}{encoder\+\_\+\+IRQ\+\_\+handler}} (uint gpio, uint32\+\_\+t events)
\begin{DoxyCompactList}\small\item\em Rotary Encoder IRQ callback. \end{DoxyCompactList}\item 
void \mbox{\hyperlink{parrot__core1_8c_a1e9b9a3be6c4b6075d04de40a2e21978}{clock\+\_\+callback}} (uint gpio, uint32\+\_\+t events)
\begin{DoxyCompactList}\small\item\em event handler for the incoming clock IRQ this is normalled from the internal clock via the external clock input jack. \end{DoxyCompactList}\item 
\Hypertarget{parrot__core1_8c_a54e230a526ff7bad3762a9c5b6683b4a}\label{parrot__core1_8c_a54e230a526ff7bad3762a9c5b6683b4a} 
void {\bfseries update\+Feedback} ()
\begin{DoxyCompactList}\small\item\em check the Feedback Pot ADC input and update the global Feedback amount parameters. This updates a moving average figure to try and eliminate or at least reduce the noise on the ADC input \end{DoxyCompactList}\item 
\Hypertarget{parrot__core1_8c_aface0710712eeff3c3721b361e2db58f}\label{parrot__core1_8c_aface0710712eeff3c3721b361e2db58f} 
void {\bfseries update\+Clock} ()
\begin{DoxyCompactList}\small\item\em Checks the Clock Pot ADC input and updates the global Internal Clock Speed. This updates a moving average figure to try and eliminate or at least reduce the noise on the ADC input. \end{DoxyCompactList}\item 
\Hypertarget{parrot__core1_8c_a528ed956aa0bf0eb015345d61b65b0f7}\label{parrot__core1_8c_a528ed956aa0bf0eb015345d61b65b0f7} 
void {\bfseries update\+Wet\+Dry} ()
\begin{DoxyCompactList}\small\item\em check the value of the wet/dry pot and update the global Wet and Dry values. Raw values are run through a moving average buffer in order to reduce noise \end{DoxyCompactList}\item 
\Hypertarget{parrot__core1_8c_a338c99b4dbf199068448188044386c98}\label{parrot__core1_8c_a338c99b4dbf199068448188044386c98} 
void {\bfseries update\+Algorithm} ()
\begin{DoxyCompactList}\small\item\em Check the state of the Algorithm pins -\/ two pins generate a 2-\/bit value, which is used to switch between the 4 different delay / reverb algorithms. \end{DoxyCompactList}\item 
\Hypertarget{parrot__core1_8c_a091d72b469ffc1b89417b1b028f1817d}\label{parrot__core1_8c_a091d72b469ffc1b89417b1b028f1817d} 
void {\bfseries update\+Divisor} ()
\begin{DoxyCompactList}\small\item\em read the 4-\/Bit BCD value from the Divisor switch, read the appropriate Divisor (multiple of the clock period) and set the global divisor value accordingly \end{DoxyCompactList}\item 
\Hypertarget{parrot__core1_8c_a9f153132b8b4afad133b952111e18bd9}\label{parrot__core1_8c_a9f153132b8b4afad133b952111e18bd9} 
void {\bfseries core1\+\_\+entry} ()
\begin{DoxyCompactList}\small\item\em core1 entry point called from \doxylink{parrot__main_8c}{parrot\+\_\+main.\+c} \end{DoxyCompactList}\end{DoxyCompactItemize}
\doxysubsubsection*{Variables}
\begin{DoxyCompactItemize}
\item 
\Hypertarget{parrot__core1_8c_a2995461f3105afc9f13934cd5c0734b2}\label{parrot__core1_8c_a2995461f3105afc9f13934cd5c0734b2} 
bool {\bfseries temp} = false
\item 
\Hypertarget{parrot__core1_8c_a7d85354add3da5b36ae9b723319e470d}\label{parrot__core1_8c_a7d85354add3da5b36ae9b723319e470d} 
double {\bfseries Clock\+BPM}
\item 
\Hypertarget{parrot__core1_8c_af392689b714f6ba2458634956905a640}\label{parrot__core1_8c_af392689b714f6ba2458634956905a640} 
double {\bfseries Clock\+Freq}
\item 
\Hypertarget{parrot__core1_8c_abc80d622ccf90a4f002f559087b51477}\label{parrot__core1_8c_abc80d622ccf90a4f002f559087b51477} 
double {\bfseries Clock\+Period}
\item 
\Hypertarget{parrot__core1_8c_a15a299b0c1a22a31c7bb56e2e838302a}\label{parrot__core1_8c_a15a299b0c1a22a31c7bb56e2e838302a} 
int {\bfseries Clock\+Phase}
\item 
\Hypertarget{parrot__core1_8c_a37c4ddc42fbe37f0df788373e2300d83}\label{parrot__core1_8c_a37c4ddc42fbe37f0df788373e2300d83} 
int {\bfseries LEDPhase}
\item 
\Hypertarget{parrot__core1_8c_a409569c38131b65358f7c2f1904d7fd5}\label{parrot__core1_8c_a409569c38131b65358f7c2f1904d7fd5} 
\+\_\+\+Atomic int32\+\_\+t {\bfseries Ext\+Clock\+Period}
\item 
\Hypertarget{parrot__core1_8c_a25c06bde7e13d38fcc6f6ade5119e1d7}\label{parrot__core1_8c_a25c06bde7e13d38fcc6f6ade5119e1d7} 
\+\_\+\+Atomic int32\+\_\+t {\bfseries Ext\+Clock\+Tick}
\item 
\Hypertarget{parrot__core1_8c_aff5f28ce7b6ef6ee218406651aef3982}\label{parrot__core1_8c_aff5f28ce7b6ef6ee218406651aef3982} 
uint {\bfseries Sync\+Free}
\item 
\Hypertarget{parrot__core1_8c_abf219ac4e7b65a1c13392b550d50b292}\label{parrot__core1_8c_abf219ac4e7b65a1c13392b550d50b292} 
uint16\+\_\+t {\bfseries Feedback\+\_\+\+MA} \mbox{[}16\mbox{]}
\item 
\Hypertarget{parrot__core1_8c_acc1457edccd8a0ef774539a9197af1ca}\label{parrot__core1_8c_acc1457edccd8a0ef774539a9197af1ca} 
uint {\bfseries Feedback\+\_\+\+MA\+\_\+\+Ptr}
\item 
\Hypertarget{parrot__core1_8c_a219dd3f426e590eb37bf82d867e5a1ca}\label{parrot__core1_8c_a219dd3f426e590eb37bf82d867e5a1ca} 
uint16\+\_\+t {\bfseries Feedback\+\_\+\+Average}
\item 
\Hypertarget{parrot__core1_8c_ad179f0b4748815cc6dbdb343939b6538}\label{parrot__core1_8c_ad179f0b4748815cc6dbdb343939b6538} 
long {\bfseries Feedback\+\_\+\+MA\+\_\+\+Sum}
\item 
\Hypertarget{parrot__core1_8c_a5b15135a7179556546e3f9d75a66bab5}\label{parrot__core1_8c_a5b15135a7179556546e3f9d75a66bab5} 
uint16\+\_\+t {\bfseries Clock\+\_\+\+MA} \mbox{[}16\mbox{]}
\item 
\Hypertarget{parrot__core1_8c_aa37d5e4c98e7790f72e86b2364fedec0}\label{parrot__core1_8c_aa37d5e4c98e7790f72e86b2364fedec0} 
uint {\bfseries Clock\+\_\+\+MA\+\_\+\+Ptr}
\item 
\Hypertarget{parrot__core1_8c_a06f932f0a9ca0bd6d74ede39568d563f}\label{parrot__core1_8c_a06f932f0a9ca0bd6d74ede39568d563f} 
uint16\+\_\+t {\bfseries Clock\+\_\+\+Average}
\item 
\Hypertarget{parrot__core1_8c_a3a824a68bf2a03007d1e6b37c86c0adb}\label{parrot__core1_8c_a3a824a68bf2a03007d1e6b37c86c0adb} 
long {\bfseries Clock\+\_\+\+MA\+\_\+\+Sum}
\item 
\Hypertarget{parrot__core1_8c_ad6065925df36ccf0651c7de04504b70c}\label{parrot__core1_8c_ad6065925df36ccf0651c7de04504b70c} 
uint16\+\_\+t {\bfseries Wet\+Dry\+\_\+\+MA} \mbox{[}16\mbox{]}
\item 
\Hypertarget{parrot__core1_8c_a56b48615d3c25daf1379295b4dfc6f9a}\label{parrot__core1_8c_a56b48615d3c25daf1379295b4dfc6f9a} 
uint {\bfseries Wet\+Dry\+\_\+\+MA\+\_\+\+Ptr}
\item 
\Hypertarget{parrot__core1_8c_aaac0f62fd26a778720aba9d7c1c6ad33}\label{parrot__core1_8c_aaac0f62fd26a778720aba9d7c1c6ad33} 
uint16\+\_\+t {\bfseries Wet\+Dry\+\_\+\+Average}
\item 
\Hypertarget{parrot__core1_8c_a4faa5c4a10babdbbfd1c2be2ede64a0b}\label{parrot__core1_8c_a4faa5c4a10babdbbfd1c2be2ede64a0b} 
long {\bfseries Wet\+Dry\+\_\+\+MA\+\_\+\+Sum}
\item 
\Hypertarget{parrot__core1_8c_ab7f48816d599dac57701e8209d217857}\label{parrot__core1_8c_ab7f48816d599dac57701e8209d217857} 
uint32\+\_\+t {\bfseries Ext\+Clock\+\_\+\+MA} \mbox{[}16\mbox{]}
\item 
\Hypertarget{parrot__core1_8c_ad76d9a51e0e19ff5dc32880b9ca9ba43}\label{parrot__core1_8c_ad76d9a51e0e19ff5dc32880b9ca9ba43} 
uint {\bfseries Ext\+Clock\+\_\+\+MA\+\_\+\+Ptr}
\item 
\Hypertarget{parrot__core1_8c_a7519e6a9b82164f8a22992fceaef27d4}\label{parrot__core1_8c_a7519e6a9b82164f8a22992fceaef27d4} 
uint32\+\_\+t {\bfseries Ext\+Clock\+\_\+\+Average}
\item 
\Hypertarget{parrot__core1_8c_a9ddc2e887189d12bdfca493a63ccc022}\label{parrot__core1_8c_a9ddc2e887189d12bdfca493a63ccc022} 
long {\bfseries Ext\+Clock\+\_\+\+MA\+\_\+\+Sum}
\item 
\Hypertarget{parrot__core1_8c_a24c48207272f896c8db10af544391fce}\label{parrot__core1_8c_a24c48207272f896c8db10af544391fce} 
uint8\+\_\+t {\bfseries lrmem} = 3
\item 
\Hypertarget{parrot__core1_8c_a7d0e2866b37580f900076a038bee5aa5}\label{parrot__core1_8c_a7d0e2866b37580f900076a038bee5aa5} 
int {\bfseries lrsum} = 0
\item 
\Hypertarget{parrot__core1_8c_a92b43dc95043cb23dab3ca60efc0e6dc}\label{parrot__core1_8c_a92b43dc95043cb23dab3ca60efc0e6dc} 
int8\+\_\+t {\bfseries TRANS} \mbox{[}$\,$\mbox{]} = \{0, -\/1, 1, 14, 1, 0, 14, -\/1, -\/1, 14, 0, 1, 14, 1, -\/1, 0\}
\end{DoxyCompactItemize}

\doxysubsection{Detailed Description}
Contains all functions that run on the second core of the Pico (Core1) These are primarily the internal and external clock routines and the less time-\/critical user interface routines

In general global variables are set by routines in parrot\+\_\+core1, then read and acted upon by the time-\/critical functions in parrot\+\_\+main 

\doxysubsection{Function Documentation}
\Hypertarget{parrot__core1_8c_afe21adbf567c42a41a4709480efb2125}\index{parrot\_core1.c@{parrot\_core1.c}!checkRotaryEncoder@{checkRotaryEncoder}}
\index{checkRotaryEncoder@{checkRotaryEncoder}!parrot\_core1.c@{parrot\_core1.c}}
\doxysubsubsection{\texorpdfstring{checkRotaryEncoder()}{checkRotaryEncoder()}}
{\footnotesize\ttfamily \label{parrot__core1_8c_afe21adbf567c42a41a4709480efb2125} 
int8\+\_\+t check\+Rotary\+Encoder (\begin{DoxyParamCaption}{}{}\end{DoxyParamCaption})}

Rotary Encoder finite state machine. 

This comes from a technical paper by Marko Pinteric \href{https://www.pinteric.com/rotary.html}{\texttt{ https\+://www.\+pinteric.\+com/rotary.\+html}}, with additions by Ralph S. Bacon \href{https://github.com/RalphBacon/226-Better-Rotary-Encoder&mdash;no-switch-bounce}{\texttt{ https\+://github.\+com/\+Ralph\+Bacon/226-\/\+Better-\/\+Rotary-\/\+Encoder---no-\/switch-\/bounce}} \Hypertarget{parrot__core1_8c_a1e9b9a3be6c4b6075d04de40a2e21978}\index{parrot\_core1.c@{parrot\_core1.c}!clock\_callback@{clock\_callback}}
\index{clock\_callback@{clock\_callback}!parrot\_core1.c@{parrot\_core1.c}}
\doxysubsubsection{\texorpdfstring{clock\_callback()}{clock\_callback()}}
{\footnotesize\ttfamily \label{parrot__core1_8c_a1e9b9a3be6c4b6075d04de40a2e21978} 
void clock\+\_\+callback (\begin{DoxyParamCaption}\item[{uint}]{gpio}{, }\item[{uint32\+\_\+t}]{events}{}\end{DoxyParamCaption})}

event handler for the incoming clock IRQ this is normalled from the internal clock via the external clock input jack. 

should be triggered on both the rising and falling edges \Hypertarget{parrot__core1_8c_a66e3dbe6039c9461b397296f63ff685a}\index{parrot\_core1.c@{parrot\_core1.c}!encoder\_IRQ\_handler@{encoder\_IRQ\_handler}}
\index{encoder\_IRQ\_handler@{encoder\_IRQ\_handler}!parrot\_core1.c@{parrot\_core1.c}}
\doxysubsubsection{\texorpdfstring{encoder\_IRQ\_handler()}{encoder\_IRQ\_handler()}}
{\footnotesize\ttfamily \label{parrot__core1_8c_a66e3dbe6039c9461b397296f63ff685a} 
void encoder\+\_\+\+IRQ\+\_\+handler (\begin{DoxyParamCaption}\item[{uint}]{gpio}{, }\item[{uint32\+\_\+t}]{events}{}\end{DoxyParamCaption})}

Rotary Encoder IRQ callback. 

In Free-\/running mode (ie sync\textquotesingle{}d to the internal or external clock) this increases or decreases the target\+Delay, which is the delay that the glb\+Delay value is aiming for, but ony moving towards by one sample at a time.

The larger the target delay, the larger the increment and therefore the lower the resolution

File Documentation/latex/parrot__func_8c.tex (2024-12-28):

\doxysection{F\+:/\+Dev/\+Parrot/parrot\+\_\+func.c File Reference}
\hypertarget{parrot__func_8c}{}\label{parrot__func_8c}\index{F:/Dev/Parrot/parrot\_func.c@{F:/Dev/Parrot/parrot\_func.c}}
{\ttfamily \#include $<$stdio.\+h$>$}\newline
{\ttfamily \#include "{}parrot.\+h"{}}\newline
{\ttfamily \#include "{}psram\+\_\+spi.\+h"{}}\newline
{\ttfamily \#include $<$math.\+h$>$}\newline
{\ttfamily \#include "{}pico/float.\+h"{}}\newline
\doxysubsubsection*{Macros}
\begin{DoxyCompactItemize}
\item 
\Hypertarget{parrot__func_8c_adbe048341e73f4fc9483b47e619b050a}\label{parrot__func_8c_adbe048341e73f4fc9483b47e619b050a} 
\#define {\bfseries SHIFT\+\_\+\+AMOUNT}~8
\end{DoxyCompactItemize}
\doxysubsubsection*{Functions}
\begin{DoxyCompactItemize}
\item 
float \mbox{\hyperlink{parrot__func_8c_ab2b4a2e0486a5936db165dbbd01e6d3f}{single\+\_\+delay}} (union \mbox{\hyperlink{unionu_sample}{u\+Sample}} In\+Sample)
\begin{DoxyCompactList}\small\item\em Single Delay. \end{DoxyCompactList}\item 
float \mbox{\hyperlink{parrot__func_8c_a41208a1e99d4c2a2ea5c1b05e1245979}{single\+\_\+tap}} (union \mbox{\hyperlink{unionu_sample}{u\+Sample}} In\+Sample, float gain)
\begin{DoxyCompactList}\small\item\em Single-\/tap delay. \end{DoxyCompactList}\item 
float \mbox{\hyperlink{parrot__func_8c_a083bd0b6658b1c5a5084a33f3ff5b12d}{Ping\+\_\+\+Pong}} (union \mbox{\hyperlink{unionu_sample}{u\+Sample}} In\+Sample, float gain, bool Left\+Right)
\begin{DoxyCompactList}\small\item\em Ping Pong delay. \end{DoxyCompactList}\item 
\Hypertarget{parrot__func_8c_aef5b39fa55da0c64b292f2191c3a4400}\label{parrot__func_8c_aef5b39fa55da0c64b292f2191c3a4400} 
int32\+\_\+t {\bfseries single\+\_\+tap\+\_\+shift} (int32\+\_\+t In\+Sample, uint32\+\_\+t delay, uint8\+\_\+t gain)
\item 
float \mbox{\hyperlink{parrot__func_8c_a1589846b899ca451fccd7b1182fb2d69}{rational\+\_\+tanh}} (float x)
\begin{DoxyCompactList}\small\item\em rational tanh \end{DoxyCompactList}\item 
float \mbox{\hyperlink{parrot__func_8c_a4acb92ba8226b09c90765256ab07387e}{soft\+\_\+clip}} (float x)
\begin{DoxyCompactList}\small\item\em Soft Clip function. \end{DoxyCompactList}\end{DoxyCompactItemize}

\doxysubsection{Detailed Description}
Various signal processing functions 

\doxysubsection{Function Documentation}
\Hypertarget{parrot__func_8c_a083bd0b6658b1c5a5084a33f3ff5b12d}\index{parrot\_func.c@{parrot\_func.c}!Ping\_Pong@{Ping\_Pong}}
\index{Ping\_Pong@{Ping\_Pong}!parrot\_func.c@{parrot\_func.c}}
\doxysubsubsection{\texorpdfstring{Ping\_Pong()}{Ping\_Pong()}}
{\footnotesize\ttfamily \label{parrot__func_8c_a083bd0b6658b1c5a5084a33f3ff5b12d} 
float Ping\+\_\+\+Pong (\begin{DoxyParamCaption}\item[{union \mbox{\hyperlink{unionu_sample}{u\+Sample}}}]{In\+Sample}{, }\item[{float}]{gain}{, }\item[{bool}]{Left\+Right}{}\end{DoxyParamCaption})}

Ping Pong delay. 

\begin{DoxyParams}{Parameters}
{\em In\+Sample} & current input sample \\
\hline
{\em gain} & feedback gain \\
\hline
{\em Left\+Right} & whether this is the Left or Right channel \\
\hline
\end{DoxyParams}
\Hypertarget{parrot__func_8c_a1589846b899ca451fccd7b1182fb2d69}\index{parrot\_func.c@{parrot\_func.c}!rational\_tanh@{rational\_tanh}}
\index{rational\_tanh@{rational\_tanh}!parrot\_func.c@{parrot\_func.c}}
\doxysubsubsection{\texorpdfstring{rational\_tanh()}{rational\_tanh()}}
{\footnotesize\ttfamily \label{parrot__func_8c_a1589846b899ca451fccd7b1182fb2d69} 
float rational\+\_\+tanh (\begin{DoxyParamCaption}\item[{float}]{x}{}\end{DoxyParamCaption})}

rational tanh 

This is a rational function to approximate a tanh-\/like soft clipper. It is based on the pade-\/approximation of the tanh function with tweaked coefficients. The function is in the range x=-\/3..3 and outputs the range y=-\/1..1. Beyond this range the output must be clamped to -\/1..1. The first two derivatives of the function vanish at -\/3 and 3, so the transition to the hard clipped region is C2-\/continuous. \Hypertarget{parrot__func_8c_ab2b4a2e0486a5936db165dbbd01e6d3f}\index{parrot\_func.c@{parrot\_func.c}!single\_delay@{single\_delay}}
\index{single\_delay@{single\_delay}!parrot\_func.c@{parrot\_func.c}}
\doxysubsubsection{\texorpdfstring{single\_delay()}{single\_delay()}}
{\footnotesize\ttfamily \label{parrot__func_8c_ab2b4a2e0486a5936db165dbbd01e6d3f} 
float single\+\_\+delay (\begin{DoxyParamCaption}\item[{union \mbox{\hyperlink{unionu_sample}{u\+Sample}}}]{In\+Sample}{}\end{DoxyParamCaption})}

Single Delay. 

Just writes the Input Sample to the current write point, and returns the delayed sample pointed to by the Read Pointer

\begin{DoxyParams}{Parameters}
{\em In\+Sample} & Input Sample from Audio buffer \\
\hline
\end{DoxyParams}
\Hypertarget{parrot__func_8c_a41208a1e99d4c2a2ea5c1b05e1245979}\index{parrot\_func.c@{parrot\_func.c}!single\_tap@{single\_tap}}
\index{single\_tap@{single\_tap}!parrot\_func.c@{parrot\_func.c}}
\doxysubsubsection{\texorpdfstring{single\_tap()}{single\_tap()}}
{\footnotesize\ttfamily \label{parrot__func_8c_a41208a1e99d4c2a2ea5c1b05e1245979} 
float single\+\_\+tap (\begin{DoxyParamCaption}\item[{union \mbox{\hyperlink{unionu_sample}{u\+Sample}}}]{In\+Sample}{, }\item[{float}]{gain}{}\end{DoxyParamCaption})}

Single-\/tap delay. 

Single-\/tap delay -\/ writes a mix of the delayed signal with the current input sample, and writes it to the current write position in the buffer.

\begin{DoxyParams}{Parameters}
{\em In\+Sample} & Current Sample from the Audio Input buffer \\
\hline
{\em gain} & feedback gain \\
\hline
\end{DoxyParams}
\Hypertarget{parrot__func_8c_a4acb92ba8226b09c90765256ab07387e}\index{parrot\_func.c@{parrot\_func.c}!soft\_clip@{soft\_clip}}
\index{soft\_clip@{soft\_clip}!parrot\_func.c@{parrot\_func.c}}
\doxysubsubsection{\texorpdfstring{soft\_clip()}{soft\_clip()}}
{\footnotesize\ttfamily \label{parrot__func_8c_a4acb92ba8226b09c90765256ab07387e} 
float soft\+\_\+clip (\begin{DoxyParamCaption}\item[{float}]{x}{}\end{DoxyParamCaption})}

Soft Clip function. 

implements a 1.\+5x -\/ 0.\+5x\texorpdfstring{$^\wedge$}{\string^}3 waveshaper

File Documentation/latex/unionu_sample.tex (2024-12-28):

\doxysection{u\+Sample Union Reference}
\hypertarget{unionu_sample}{}\label{unionu_sample}\index{uSample@{uSample}}

union of a float and a 32-\/Bit integer  

{\ttfamily \#include $<$parrot.\+h$>$}

\doxysubsubsection*{Data Fields}
\begin{DoxyCompactItemize}
\item 
\Hypertarget{unionu_sample_acbccd2c324f6bb0881ad7b400a0261bb}\label{unionu_sample_acbccd2c324f6bb0881ad7b400a0261bb} 
float {\bfseries f\+Sample}
\item 
\Hypertarget{unionu_sample_ae32bffa65bd8e98ec4288f6ab5dcac7c}\label{unionu_sample_ae32bffa65bd8e98ec4288f6ab5dcac7c} 
int32\+\_\+t {\bfseries i\+Sample}
\end{DoxyCompactItemize}

\doxysubsection{Detailed Description}
union of a float and a 32-\/Bit integer 

The elements of the Union can be accessed separately even though they are the {\itshape same} 4 x 8-\/bit bytes. This enables a Float to be passed about for processing, but stored and read from RSRAM as if it were a 32-\/Bit word 

The documentation for this union was generated from the following file\+:\begin{DoxyCompactItemize}
\item 
F\+:/\+Dev/\+Parrot/\mbox{\hyperlink{parrot_8h}{parrot.\+h}}\end{DoxyCompactItemize}

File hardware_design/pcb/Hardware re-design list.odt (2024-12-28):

Camberwell Parrot - Items that need fixing for a Rev-2 board

- Need to be agnostic to the RP2350 pull-down bug. Note and deal with any/all inputs that currently use pull-down.

This means use pull-up inputs where possible, and switch them to Ground externally, maybe remove all pull-up or -down resistors from inputs where driven by Eg MC14532 – need to experiment to see if they really need them

- Connect the clock LED directly to the Clock output port rather than a dedicated LED output.

This will win back another GPIO Pin, which should mean that we can use an 8-way algorithm switch

- Use a 7805 regulator in DPAK package with better ground heatsink

- reverse the connections to the feedback pot so that it increases as you turn it clockwise

- reverse the connections to the Clock Speed pot so that speed increases as you turn it clockwise!!

- turn the 8-Way switches 90 degrees so that the knobs point upwards

- turn the input gain pot 180 degrees so that flat side is in the correct orientation

- move the LED closer to the clock output.

- Check for PSRAM Pin-compatibility with the RP2350 Stamps

Software re-design considerations

- Could do with de-bouncing the Divisor switch, as it bounces terribly

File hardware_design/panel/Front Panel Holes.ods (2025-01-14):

Parrot – Position & Diameter of front panel drill holes relative to board origin (Top Left)
 |  | X | Y | Dia |  | Calculating where to put the RH Mounting holes (whole number of HP)
 | PCB Origin | 30 | 30 |  |  |  | X | Y |  | No of HP | RH Hole | Distance from RH Edge
 | Panel Origin | 29 | 20.75 |  |  | Top Right Corner | 89.6 | 20.75 |  | 9 | 82.22 | 7.38
 | Offset | 1 | 9.25 |  |  | Lower Right | 89.6 | 149.25
 |  | Offset from Board |  |  |  | Offset from Panel
 | Feedback | 43 | 36 | 7.5 |  | 14 | 15.25
 | Wet/Dry | 75.6 | 36 | 7.5 |  | 46.6 | 15.25
 | Delay / Panic | 59.3 | 55.4 | 7.5 |  | 30.3 | 34.65
 | Algorithm | 43 | 74.8 | 8.5 |  | 14 | 54.05
 | Ratio | 75.6 | 74.8 | 8.5 |  | 46.6 | 54.05
 | Sync / Free | 41 | 94.2 | 6.8 |  | 12 | 73.45
 | Mul / Div | 77.6 | 94.2 | 6.8 |  | 48.6 | 73.45
 | Clock | 59.3 | 94.2 | 7.5 |  | 30.3 | 73.45
 | Gain | 43 | 113 | 7.5 |  | 14 | 92.25
 | LED | 83.8 | 104 | 3 |  | 54.8 | 83.25
 | Clock IN | 70.1 | 113 | 6.2 |  | 41.1 | 92.25
 | Clock OUT | 81.1 | 113 | 6.2 |  | 52.1 | 92.25
 | IN L | 37.5 | 133 | 6.2 |  | 8.5 | 112.25
 | IN R | 48.5 | 133 | 6.2 |  | 19.5 | 112.25
 | OUT L | 70.1 | 133 | 6.2 |  | 41.1 | 112.25
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

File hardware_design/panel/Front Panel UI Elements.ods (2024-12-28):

Camberwell Parrot – Front Panel UI elements
 | Function | Item
1 | Left In | Thonkicon
2 | Right In | Thonkicon
3 | Left Out | Thonkicon
4 | Right Out | Thonkicon
5 | Clock In | Thonkicon
6 | Clock Out | Thonkicon
7 | Input Gain | Dual Potentiometer
8 | Wet/Dry Balance | Potentiometer
9 | Feedback | Potentiometer
10 | Clock Speed | Potentiometer
11 | Clock Indicator | LED
12 | Delay Length / Panic | Rotary Encoder
13 | Mult / Div switch | Sub-miniature switch
14 | Sync / free switch | Sub-miniature switch
15 | Clock Divisor | Rotary Switch
16 | Algorithm | Rotary Switch

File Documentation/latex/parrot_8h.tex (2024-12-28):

\doxysection{F\+:/\+Dev/\+Parrot/parrot.h File Reference}
\hypertarget{parrot_8h}{}\label{parrot_8h}\index{F:/Dev/Parrot/parrot.h@{F:/Dev/Parrot/parrot.h}}
{\ttfamily \#include "{}psram\+\_\+spi.\+h"{}}\newline
\doxysubsubsection*{Data Structures}
\begin{DoxyCompactItemize}
\item 
union \mbox{\hyperlink{unionu_sample}{u\+Sample}}
\begin{DoxyCompactList}\small\item\em union of a float and a 32-\/Bit integer \end{DoxyCompactList}\end{DoxyCompactItemize}
\doxysubsubsection*{Macros}
\begin{DoxyCompactItemize}
\item 
\Hypertarget{parrot_8h_aced620805d4932cfff9e1ee967ad013d}\label{parrot_8h_aced620805d4932cfff9e1ee967ad013d} 
\#define {\bfseries ALARM\+\_\+\+NUM}~1
\item 
\Hypertarget{parrot_8h_aedb88e03a9d05e766158a1f0895e0f8a}\label{parrot_8h_aedb88e03a9d05e766158a1f0895e0f8a} 
\#define {\bfseries ALARM\+\_\+\+IRQ}~TIMER\+\_\+\+IRQ\+\_\+1
\item 
\Hypertarget{parrot_8h_a7f93e2fe7d68da94913e3f9f81afc035}\label{parrot_8h_a7f93e2fe7d68da94913e3f9f81afc035} 
\#define {\bfseries muls15x16}(a,  b)~((\mbox{\hyperlink{parrot_8h_a6bdff0bc03d24ec80e07d29f92a4d8a8}{s15x16}})(((( signed long long )(a))\texorpdfstring{$\ast$}{*}(( signed long long )(b)))$>$$>$16))
\item 
\Hypertarget{parrot_8h_ad43e278facd4cc3f324ff19339fe47db}\label{parrot_8h_ad43e278facd4cc3f324ff19339fe47db} 
\#define {\bfseries float\+\_\+to\+\_\+s15x16}(a)~((\mbox{\hyperlink{parrot_8h_a6bdff0bc03d24ec80e07d29f92a4d8a8}{s15x16}})((a)\texorpdfstring{$\ast$}{*}65536.\+0))
\item 
\Hypertarget{parrot_8h_aae96c9cabca27369ceae58033213e44c}\label{parrot_8h_aae96c9cabca27369ceae58033213e44c} 
\#define {\bfseries s15x16\+\_\+to\+\_\+float}(a)~((float)(a)/65536.\+0)
\item 
\Hypertarget{parrot_8h_a9f58b6797d59294b7b31fc193b4c11c6}\label{parrot_8h_a9f58b6797d59294b7b31fc193b4c11c6} 
\#define {\bfseries s15x16\+\_\+to\+\_\+int}(a)~((int)((a)$>$$>$16))
\item 
\Hypertarget{parrot_8h_a05a47f4d60ed1752adc9e46e29b14bfa}\label{parrot_8h_a05a47f4d60ed1752adc9e46e29b14bfa} 
\#define {\bfseries int\+\_\+to\+\_\+s15x16}(a)~((\mbox{\hyperlink{parrot_8h_a6bdff0bc03d24ec80e07d29f92a4d8a8}{s15x16}})((a)$<$$<$16))
\item 
\Hypertarget{parrot_8h_a24f7b9d8b3d730e6c82f27efe7b2950e}\label{parrot_8h_a24f7b9d8b3d730e6c82f27efe7b2950e} 
\#define {\bfseries divs15x16}(a,  b)~((\mbox{\hyperlink{parrot_8h_a6bdff0bc03d24ec80e07d29f92a4d8a8}{s15x16}})((((signed long long)(a)$<$$<$16)/(b))))
\item 
\Hypertarget{parrot_8h_a3d67d21cc630eadc821d366812d5a7f0}\label{parrot_8h_a3d67d21cc630eadc821d366812d5a7f0} 
\#define {\bfseries abss15x16}(a)~abs(a)
\item 
\Hypertarget{parrot_8h_a2daf35d7cbf61c210ff47f8f057a5c4d}\label{parrot_8h_a2daf35d7cbf61c210ff47f8f057a5c4d} 
\#define {\bfseries muls1x14}(a,  b)~((s1x14)((((int)(a))\texorpdfstring{$\ast$}{*}((int)(b)))$>$$>$14))
\item 
\Hypertarget{parrot_8h_af082b372f19906dcce8973a17db2c6ca}\label{parrot_8h_af082b372f19906dcce8973a17db2c6ca} 
\#define {\bfseries float\+\_\+to\+\_\+s1x14}(a)~((s1x14)((a)\texorpdfstring{$\ast$}{*}16384.\+0))
\item 
\Hypertarget{parrot_8h_abf2ebc86525c826a318a4ea4603d2071}\label{parrot_8h_abf2ebc86525c826a318a4ea4603d2071} 
\#define {\bfseries s1x14\+\_\+to\+\_\+float}(a)~((float)(a)/16384.\+0)
\item 
\Hypertarget{parrot_8h_af1bbc28faa9dcdab52e6538469ecfcb9}\label{parrot_8h_af1bbc28faa9dcdab52e6538469ecfcb9} 
\#define {\bfseries abss1x14}(a)~abs(a)
\item 
\Hypertarget{parrot_8h_a2652f32276a90ed6e3b86303b3ace6ea}\label{parrot_8h_a2652f32276a90ed6e3b86303b3ace6ea} 
\#define {\bfseries divs1x14}(a,  b)~((s1x14)((((signed int)(a)$<$$<$14)/(b))))
\item 
\Hypertarget{parrot_8h_a7801a83de96d85f7f4d7dd3ad60183bd}\label{parrot_8h_a7801a83de96d85f7f4d7dd3ad60183bd} 
\#define {\bfseries float\+\_\+to\+\_\+int}(x)~(((int) ((x \texorpdfstring{$\ast$}{*} 8388607) + 8388608.\+5f)) -\/ 8388608)
\item 
\Hypertarget{parrot_8h_a183bc17010bc9b3eb14f05b2b17f7096}\label{parrot_8h_a183bc17010bc9b3eb14f05b2b17f7096} 
\#define {\bfseries float\+\_\+to\+\_\+int32}(x)~(((int) ((x \texorpdfstring{$\ast$}{*} 2147483647) + 2147483648.\+5f)) -\/ 2147483648)
\item 
\Hypertarget{parrot_8h_a2d90c7620cf1fbc49c316297c166edcb}\label{parrot_8h_a2d90c7620cf1fbc49c316297c166edcb} 
\#define {\bfseries int\+\_\+to\+\_\+float}(x)~((((float) (x + 8388608)) -\/ 8388608.\+5f) / 8388607.f)
\item 
\Hypertarget{parrot_8h_ad1d2c6750d3244c320dfec3c84c14926}\label{parrot_8h_ad1d2c6750d3244c320dfec3c84c14926} 
\#define {\bfseries int32\+\_\+to\+\_\+float}(x)~((((float) (x + 2147483648)) -\/ 2147483648.\+5f) / 2147483648.f)
\end{DoxyCompactItemize}
\doxysubsubsection*{Typedefs}
\begin{DoxyCompactItemize}
\item 
typedef signed int \mbox{\hyperlink{parrot_8h_a6bdff0bc03d24ec80e07d29f92a4d8a8}{s15x16}}
\begin{DoxyCompactList}\small\item\em Various fixed point conversion, multiplication and division macros. \end{DoxyCompactList}\item 
\Hypertarget{parrot_8h_a3f448718a042309479cd355982a73893}\label{parrot_8h_a3f448718a042309479cd355982a73893} 
typedef signed short {\bfseries s1x14}
\end{DoxyCompactItemize}
\doxysubsubsection*{Functions}
\begin{DoxyCompactItemize}
\item 
\Hypertarget{parrot_8h_a677531d0ec7a1f4b9b9d8ebb4b3d4521}\label{parrot_8h_a677531d0ec7a1f4b9b9d8ebb4b3d4521} 
void {\bfseries core1\+\_\+entry} (void)
\begin{DoxyCompactList}\small\item\em core1 entry point called from \doxylink{parrot__main_8c}{parrot\+\_\+main.\+c} \end{DoxyCompactList}\item 
float \mbox{\hyperlink{parrot_8h_a782715f72de752446e670ca8536fd4fd}{single\+\_\+delay}} (union \mbox{\hyperlink{unionu_sample}{u\+Sample}})
\begin{DoxyCompactList}\small\item\em Single Delay. \end{DoxyCompactList}\item 
float \mbox{\hyperlink{parrot_8h_a9a421dffc23588ba1399035b42a635b3}{single\+\_\+tap}} (union \mbox{\hyperlink{unionu_sample}{u\+Sample}}, float)
\begin{DoxyCompactList}\small\item\em Single-\/tap delay. \end{DoxyCompactList}\item 
float \mbox{\hyperlink{parrot_8h_a931af3f4a4ce6b4d652cba2025fd5556}{Ping\+\_\+\+Pong}} (union \mbox{\hyperlink{unionu_sample}{u\+Sample}}, float, bool)
\begin{DoxyCompactList}\small\item\em Ping Pong delay. \end{DoxyCompactList}\item 
\Hypertarget{parrot_8h_aec2284b0de923d0eda61a86fb6b4c648}\label{parrot_8h_aec2284b0de923d0eda61a86fb6b4c648} 
int32\+\_\+t {\bfseries single\+\_\+tap\+\_\+shift} (int32\+\_\+t, uint32\+\_\+t, uint8\+\_\+t)
\item 
float \mbox{\hyperlink{parrot_8h_a7820a4fd83fffae49196ac19d501ecd6}{rational\+\_\+tanh}} (float)
\begin{DoxyCompactList}\small\item\em rational tanh \end{DoxyCompactList}\item 
float \mbox{\hyperlink{parrot_8h_a1d4475a10532e87db4a30c3a082ddc90}{soft\+\_\+clip}} (float)
\begin{DoxyCompactList}\small\item\em Soft Clip function. \end{DoxyCompactList}\end{DoxyCompactItemize}
\doxysubsubsection*{Variables}
\begin{DoxyCompactItemize}
\item 
\Hypertarget{parrot_8h_a7d85354add3da5b36ae9b723319e470d}\label{parrot_8h_a7d85354add3da5b36ae9b723319e470d} 
double {\bfseries Clock\+BPM}
\item 
\Hypertarget{parrot_8h_af392689b714f6ba2458634956905a640}\label{parrot_8h_af392689b714f6ba2458634956905a640} 
double {\bfseries Clock\+Freq}
\item 
\Hypertarget{parrot_8h_abc80d622ccf90a4f002f559087b51477}\label{parrot_8h_abc80d622ccf90a4f002f559087b51477} 
double {\bfseries Clock\+Period}
\item 
\Hypertarget{parrot_8h_ac555310904b58878c17cbe950aa087b0}\label{parrot_8h_ac555310904b58878c17cbe950aa087b0} 
uint32\+\_\+t {\bfseries Read\+Pointer}
\item 
\Hypertarget{parrot_8h_a283b67b14f146dbdae08dcfb9b3259c1}\label{parrot_8h_a283b67b14f146dbdae08dcfb9b3259c1} 
uint32\+\_\+t {\bfseries Write\+Pointer}
\item 
\Hypertarget{parrot_8h_a637ed802eeffccca74e9ea7e2ab729d5}\label{parrot_8h_a637ed802eeffccca74e9ea7e2ab729d5} 
float {\bfseries glb\+Feedback}
\item 
\Hypertarget{parrot_8h_ade4c3293feef1039a1321536183b5ab8}\label{parrot_8h_ade4c3293feef1039a1321536183b5ab8} 
float {\bfseries glb\+Divisor}
\item 
float \mbox{\hyperlink{parrot_8h_a5d8ff28893901c00f6792c86ecb5bd01}{divisors}} \mbox{[}$\,$\mbox{]}
\begin{DoxyCompactList}\small\item\em An array of multipliers, which are applied to the master internal or external clock frequency to set the delay time as a multiple of the clock period. \end{DoxyCompactList}\item 
\Hypertarget{parrot_8h_a9d43969205916404e43965cd65ed2e1a}\label{parrot_8h_a9d43969205916404e43965cd65ed2e1a} 
int {\bfseries Algorithm}
\item 
\Hypertarget{parrot_8h_a409569c38131b65358f7c2f1904d7fd5}\label{parrot_8h_a409569c38131b65358f7c2f1904d7fd5} 
\+\_\+\+Atomic int32\+\_\+t {\bfseries Ext\+Clock\+Period}
\item 
\Hypertarget{parrot_8h_a25c06bde7e13d38fcc6f6ade5119e1d7}\label{parrot_8h_a25c06bde7e13d38fcc6f6ade5119e1d7} 
\+\_\+\+Atomic int32\+\_\+t {\bfseries Ext\+Clock\+Tick}
\item 
\Hypertarget{parrot_8h_a6aa2f30691bc3872d6a19a90dd200684}\label{parrot_8h_a6aa2f30691bc3872d6a19a90dd200684} 
uint32\+\_\+t {\bfseries glb\+Delay}
\item 
\Hypertarget{parrot_8h_ae298eaa20a8e2c4a190d13f16dc9ae05}\label{parrot_8h_ae298eaa20a8e2c4a190d13f16dc9ae05} 
uint32\+\_\+t {\bfseries target\+Delay}
\item 
\Hypertarget{parrot_8h_aea8be3b13319315ac2941535a39037b1}\label{parrot_8h_aea8be3b13319315ac2941535a39037b1} 
int32\+\_\+t {\bfseries Previous\+Clock\+Period}
\item 
\Hypertarget{parrot_8h_a1b0ae65de18e8470519861ecaa5bc95c}\label{parrot_8h_a1b0ae65de18e8470519861ecaa5bc95c} 
uint32\+\_\+t {\bfseries glb\+Increment}
\item 
\Hypertarget{parrot_8h_a27f48716330739d3ecace3f7cb0579f1}\label{parrot_8h_a27f48716330739d3ecace3f7cb0579f1} 
int32\+\_\+t {\bfseries Delay\+Diff}
\item 
\Hypertarget{parrot_8h_a8a8ebb7dcab8c051ca45b0da0186a5cf}\label{parrot_8h_a8a8ebb7dcab8c051ca45b0da0186a5cf} 
float {\bfseries glb\+Wet}
\item 
\Hypertarget{parrot_8h_ad7a585b9ac22f4e71dd43c8caa15e6e0}\label{parrot_8h_ad7a585b9ac22f4e71dd43c8caa15e6e0} 
float {\bfseries glb\+Dry}
\item 
\Hypertarget{parrot_8h_adb1c2b4c2370045d29f5678c2b73aada}\label{parrot_8h_adb1c2b4c2370045d29f5678c2b73aada} 
int {\bfseries spinlock\+\_\+num\+\_\+glb\+Delay}
\item 
\Hypertarget{parrot_8h_a4be5364d8c7aaa805ad6124a822f0fe7}\label{parrot_8h_a4be5364d8c7aaa805ad6124a822f0fe7} 
spin\+\_\+lock\+\_\+t \texorpdfstring{$\ast$}{*} {\bfseries spinlock\+\_\+glb\+Delay}
\item 
\Hypertarget{parrot_8h_a15a299b0c1a22a31c7bb56e2e838302a}\label{parrot_8h_a15a299b0c1a22a31c7bb56e2e838302a} 
int {\bfseries Clock\+Phase}
\item 
\Hypertarget{parrot_8h_a37c4ddc42fbe37f0df788373e2300d83}\label{parrot_8h_a37c4ddc42fbe37f0df788373e2300d83} 
int {\bfseries LEDPhase}
\item 
\Hypertarget{parrot_8h_a761a47ee75962d758ab831639f19cc26}\label{parrot_8h_a761a47ee75962d758ab831639f19cc26} 
float {\bfseries Feedback\+Percent}
\item 
\Hypertarget{parrot_8h_a93bb8fa320fe4e166005fc4f0c0b2705}\label{parrot_8h_a93bb8fa320fe4e166005fc4f0c0b2705} 
psram\+\_\+spi\+\_\+inst\+\_\+t {\bfseries psram\+\_\+spi}
\end{DoxyCompactItemize}

\doxysubsection{Detailed Description}
Header file -\/ constant definitions, function prototypes etc 

\doxysubsection{Typedef Documentation}
\Hypertarget{parrot_8h_a6bdff0bc03d24ec80e07d29f92a4d8a8}\index{parrot.h@{parrot.h}!s15x16@{s15x16}}
\index{s15x16@{s15x16}!parrot.h@{parrot.h}}
\doxysubsubsection{\texorpdfstring{s15x16}{s15x16}}
{\footnotesize\ttfamily \label{parrot_8h_a6bdff0bc03d24ec80e07d29f92a4d8a8} 
typedef signed int \mbox{\hyperlink{parrot_8h_a6bdff0bc03d24ec80e07d29f92a4d8a8}{s15x16}}}

Various fixed point conversion, multiplication and division macros. 

These came from here\+: \href{https://people.ece.cornell.edu/land/courses/ece4760/RP2040/C_SDK_fixed_pt/speed_test/Fixed_point_test.c}{\texttt{ https\+://people.\+ece.\+cornell.\+edu/land/courses/ece4760/\+RP2040/\+C\+\_\+\+SDK\+\_\+fixed\+\_\+pt/speed\+\_\+test/\+Fixed\+\_\+point\+\_\+test.\+c}} 

\doxysubsection{Function Documentation}
\Hypertarget{parrot_8h_a931af3f4a4ce6b4d652cba2025fd5556}\index{parrot.h@{parrot.h}!Ping\_Pong@{Ping\_Pong}}
\index{Ping\_Pong@{Ping\_Pong}!parrot.h@{parrot.h}}
\doxysubsubsection{\texorpdfstring{Ping\_Pong()}{Ping\_Pong()}}
{\footnotesize\ttfamily \label{parrot_8h_a931af3f4a4ce6b4d652cba2025fd5556} 
float Ping\+\_\+\+Pong (\begin{DoxyParamCaption}\item[{union \mbox{\hyperlink{unionu_sample}{u\+Sample}}}]{In\+Sample}{, }\item[{float}]{gain}{, }\item[{bool}]{Left\+Right}{}\end{DoxyParamCaption})}

Ping Pong delay. 

\begin{DoxyParams}{Parameters}
{\em In\+Sample} & current input sample \\
\hline
{\em gain} & feedback gain \\
\hline
{\em Left\+Right} & whether this is the Left or Right channel \\
\hline
\end{DoxyParams}
\Hypertarget{parrot_8h_a7820a4fd83fffae49196ac19d501ecd6}\index{parrot.h@{parrot.h}!rational\_tanh@{rational\_tanh}}
\index{rational\_tanh@{rational\_tanh}!parrot.h@{parrot.h}}
\doxysubsubsection{\texorpdfstring{rational\_tanh()}{rational\_tanh()}}
{\footnotesize\ttfamily \label{parrot_8h_a7820a4fd83fffae49196ac19d501ecd6} 
float rational\+\_\+tanh (\begin{DoxyParamCaption}\item[{float}]{x}{}\end{DoxyParamCaption})}

rational tanh 

This is a rational function to approximate a tanh-\/like soft clipper. It is based on the pade-\/approximation of the tanh function with tweaked coefficients. The function is in the range x=-\/3..3 and outputs the range y=-\/1..1. Beyond this range the output must be clamped to -\/1..1. The first two derivatives of the function vanish at -\/3 and 3, so the transition to the hard clipped region is C2-\/continuous. \Hypertarget{parrot_8h_a782715f72de752446e670ca8536fd4fd}\index{parrot.h@{parrot.h}!single\_delay@{single\_delay}}
\index{single\_delay@{single\_delay}!parrot.h@{parrot.h}}
\doxysubsubsection{\texorpdfstring{single\_delay()}{single\_delay()}}
{\footnotesize\ttfamily \label{parrot_8h_a782715f72de752446e670ca8536fd4fd} 
float single\+\_\+delay (\begin{DoxyParamCaption}\item[{union \mbox{\hyperlink{unionu_sample}{u\+Sample}}}]{In\+Sample}{}\end{DoxyParamCaption})}

Single Delay. 

Just writes the Input Sample to the current write point, and returns the delayed sample pointed to by the Read Pointer

\begin{DoxyParams}{Parameters}
{\em In\+Sample} & Input Sample from Audio buffer \\
\hline
\end{DoxyParams}
\Hypertarget{parrot_8h_a9a421dffc23588ba1399035b42a635b3}\index{parrot.h@{parrot.h}!single\_tap@{single\_tap}}
\index{single\_tap@{single\_tap}!parrot.h@{parrot.h}}
\doxysubsubsection{\texorpdfstring{single\_tap()}{single\_tap()}}
{\footnotesize\ttfamily \label{parrot_8h_a9a421dffc23588ba1399035b42a635b3} 
float single\+\_\+tap (\begin{DoxyParamCaption}\item[{union \mbox{\hyperlink{unionu_sample}{u\+Sample}}}]{In\+Sample}{, }\item[{float}]{gain}{}\end{DoxyParamCaption})}

Single-\/tap delay. 

Single-\/tap delay -\/ writes a mix of the delayed signal with the current input sample, and writes it to the current write position in the buffer.

\begin{DoxyParams}{Parameters}
{\em In\+Sample} & Current Sample from the Audio Input buffer \\
\hline
{\em gain} & feedback gain \\
\hline
\end{DoxyParams}
\Hypertarget{parrot_8h_a1d4475a10532e87db4a30c3a082ddc90}\index{parrot.h@{parrot.h}!soft\_clip@{soft\_clip}}
\index{soft\_clip@{soft\_clip}!parrot.h@{parrot.h}}
\doxysubsubsection{\texorpdfstring{soft\_clip()}{soft\_clip()}}
{\footnotesize\ttfamily \label{parrot_8h_a1d4475a10532e87db4a30c3a082ddc90} 
float soft\+\_\+clip (\begin{DoxyParamCaption}\item[{float}]{x}{}\end{DoxyParamCaption})}

Soft Clip function. 

implements a 1.\+5x -\/ 0.\+5x\texorpdfstring{$^\wedge$}{\string^}3 waveshaper 

\doxysubsection{Variable Documentation}
\Hypertarget{parrot_8h_a5d8ff28893901c00f6792c86ecb5bd01}\index{parrot.h@{parrot.h}!divisors@{divisors}}
\index{divisors@{divisors}!parrot.h@{parrot.h}}
\doxysubsubsection{\texorpdfstring{divisors}{divisors}}
{\footnotesize\ttfamily \label{parrot_8h_a5d8ff28893901c00f6792c86ecb5bd01} 
float divisors\mbox{[}$\,$\mbox{]}\hspace{0.3cm}{\ttfamily [extern]}}

An array of multipliers, which are applied to the master internal or external clock frequency to set the delay time as a multiple of the clock period. 

1/12 1/8 1/6 1/5 1/4 1/3 1/2 1\texorpdfstring{$\ast$}{*} 2\texorpdfstring{$\ast$}{*} 3\texorpdfstring{$\ast$}{*} 4\texorpdfstring{$\ast$}{*} 5\texorpdfstring{$\ast$}{*} 6\texorpdfstring{$\ast$}{*} 8\texorpdfstring{$\ast$}{*} 12\texorpdfstring{$\ast$}{*}

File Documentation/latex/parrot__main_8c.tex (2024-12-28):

\doxysection{F\+:/\+Dev/\+Parrot/parrot\+\_\+main.c File Reference}
\hypertarget{parrot__main_8c}{}\label{parrot__main_8c}\index{F:/Dev/Parrot/parrot\_main.c@{F:/Dev/Parrot/parrot\_main.c}}
{\ttfamily \#include $<$stdio.\+h$>$}\newline
{\ttfamily \#include "{}parrot.\+h"{}}\newline
{\ttfamily \#include "{}pico/stdlib.\+h"{}}\newline
{\ttfamily \#include "{}pico/multicore.\+h"{}}\newline
{\ttfamily \#include "{}hardware/dma.\+h"{}}\newline
{\ttfamily \#include "{}hardware/adc.\+h"{}}\newline
{\ttfamily \#include "{}i2s/i2s.\+h"{}}\newline
{\ttfamily \#include "{}psram\+\_\+spi.\+h"{}}\newline
{\ttfamily \#include "{}hardware/sync.\+h"{}}\newline
\doxysubsubsection*{Functions}
\begin{DoxyCompactItemize}
\item 
\Hypertarget{parrot__main_8c_ad17104e92409e30258a08ef6c2ed17b3}\label{parrot__main_8c_ad17104e92409e30258a08ef6c2ed17b3} 
int {\bfseries get\+\_\+sign} (int32\+\_\+t value)
\item 
void \mbox{\hyperlink{parrot__main_8c_a0882689ae327acfabbb12bd78cc7e16d}{check\+Reset}} ()
\begin{DoxyCompactList}\small\item\em Check for the Rotary Encoder button push. \end{DoxyCompactList}\item 
int \mbox{\hyperlink{parrot__main_8c_ae66f6b31b5ad750f1fe042a706a4e3d4}{main}} ()
\begin{DoxyCompactList}\small\item\em Main program entry point. \end{DoxyCompactList}\end{DoxyCompactItemize}
\doxysubsubsection*{Variables}
\begin{DoxyCompactItemize}
\item 
\Hypertarget{parrot__main_8c_ac555310904b58878c17cbe950aa087b0}\label{parrot__main_8c_ac555310904b58878c17cbe950aa087b0} 
uint32\+\_\+t {\bfseries Read\+Pointer} = 0
\item 
\Hypertarget{parrot__main_8c_a283b67b14f146dbdae08dcfb9b3259c1}\label{parrot__main_8c_a283b67b14f146dbdae08dcfb9b3259c1} 
uint32\+\_\+t {\bfseries Write\+Pointer} = 0
\item 
\Hypertarget{parrot__main_8c_a637ed802eeffccca74e9ea7e2ab729d5}\label{parrot__main_8c_a637ed802eeffccca74e9ea7e2ab729d5} 
float {\bfseries glb\+Feedback} = 0.\+1
\item 
\Hypertarget{parrot__main_8c_ade4c3293feef1039a1321536183b5ab8}\label{parrot__main_8c_ade4c3293feef1039a1321536183b5ab8} 
float {\bfseries glb\+Divisor} = 1
\item 
\Hypertarget{parrot__main_8c_ace2ee0a67733422f866c0856a2f6c626}\label{parrot__main_8c_ace2ee0a67733422f866c0856a2f6c626} 
uint32\+\_\+t {\bfseries encoder\+\_\+tick} = 0
\item 
\Hypertarget{parrot__main_8c_a6aa2f30691bc3872d6a19a90dd200684}\label{parrot__main_8c_a6aa2f30691bc3872d6a19a90dd200684} 
uint32\+\_\+t {\bfseries glb\+Delay}
\item 
\Hypertarget{parrot__main_8c_ae298eaa20a8e2c4a190d13f16dc9ae05}\label{parrot__main_8c_ae298eaa20a8e2c4a190d13f16dc9ae05} 
uint32\+\_\+t {\bfseries target\+Delay}
\item 
\Hypertarget{parrot__main_8c_aea8be3b13319315ac2941535a39037b1}\label{parrot__main_8c_aea8be3b13319315ac2941535a39037b1} 
int32\+\_\+t {\bfseries Previous\+Clock\+Period} = 0
\item 
\Hypertarget{parrot__main_8c_a1b0ae65de18e8470519861ecaa5bc95c}\label{parrot__main_8c_a1b0ae65de18e8470519861ecaa5bc95c} 
uint32\+\_\+t {\bfseries glb\+Increment} = 1
\item 
\Hypertarget{parrot__main_8c_adb1c2b4c2370045d29f5678c2b73aada}\label{parrot__main_8c_adb1c2b4c2370045d29f5678c2b73aada} 
int {\bfseries spinlock\+\_\+num\+\_\+glb\+Delay}
\item 
\Hypertarget{parrot__main_8c_a4be5364d8c7aaa805ad6124a822f0fe7}\label{parrot__main_8c_a4be5364d8c7aaa805ad6124a822f0fe7} 
spin\+\_\+lock\+\_\+t \texorpdfstring{$\ast$}{*} {\bfseries spinlock\+\_\+glb\+Delay}
\item 
\Hypertarget{parrot__main_8c_a9d43969205916404e43965cd65ed2e1a}\label{parrot__main_8c_a9d43969205916404e43965cd65ed2e1a} 
int {\bfseries Algorithm} = 0
\item 
\Hypertarget{parrot__main_8c_a0254797ddd6d1744dfa5d6d2a9bbcf59}\label{parrot__main_8c_a0254797ddd6d1744dfa5d6d2a9bbcf59} 
int {\bfseries rampcount} = 0
\item 
\Hypertarget{parrot__main_8c_a41fdb578777a045e56dd3ad408cb128d}\label{parrot__main_8c_a41fdb578777a045e56dd3ad408cb128d} 
int {\bfseries This\+Left}
\item 
\Hypertarget{parrot__main_8c_a06106cda2c60a89064e9d27c8085991c}\label{parrot__main_8c_a06106cda2c60a89064e9d27c8085991c} 
int {\bfseries Previous\+Left}
\item 
\Hypertarget{parrot__main_8c_a6827e4faa914e292e5aa61ceb50bdfb3}\label{parrot__main_8c_a6827e4faa914e292e5aa61ceb50bdfb3} 
int {\bfseries This\+Right}
\item 
\Hypertarget{parrot__main_8c_af6ae070c0e57a3ec2bf85b62c051c15a}\label{parrot__main_8c_af6ae070c0e57a3ec2bf85b62c051c15a} 
int {\bfseries Previous\+Right}
\item 
\Hypertarget{parrot__main_8c_a8a8ebb7dcab8c051ca45b0da0186a5cf}\label{parrot__main_8c_a8a8ebb7dcab8c051ca45b0da0186a5cf} 
float {\bfseries glb\+Wet} = 0
\item 
\Hypertarget{parrot__main_8c_ad7a585b9ac22f4e71dd43c8caa15e6e0}\label{parrot__main_8c_ad7a585b9ac22f4e71dd43c8caa15e6e0} 
float {\bfseries glb\+Dry} = 1
\item 
float \mbox{\hyperlink{parrot__main_8c_a5d8ff28893901c00f6792c86ecb5bd01}{divisors}} \mbox{[}$\,$\mbox{]} = \{1,2,3,4,5,6,8,12,1,0.\+5,0.\+33333,0.\+25,0.\+2,0.\+166666,0.\+125,0.\+083333\}
\begin{DoxyCompactList}\small\item\em An array of multipliers, which are applied to the master internal or external clock frequency to set the delay time as a multiple of the clock period. \end{DoxyCompactList}\item 
\Hypertarget{parrot__main_8c_af958432adf242f882e07a92f4689ecc8}\label{parrot__main_8c_af958432adf242f882e07a92f4689ecc8} 
psram\+\_\+spi\+\_\+inst\+\_\+t \texorpdfstring{$\ast$}{*} {\bfseries async\+\_\+spi\+\_\+inst}
\item 
\Hypertarget{parrot__main_8c_a93bb8fa320fe4e166005fc4f0c0b2705}\label{parrot__main_8c_a93bb8fa320fe4e166005fc4f0c0b2705} 
psram\+\_\+spi\+\_\+inst\+\_\+t {\bfseries psram\+\_\+spi}
\item 
\Hypertarget{parrot__main_8c_ab7de02793c1a9ed4d17aeaf1503ec514}\label{parrot__main_8c_ab7de02793c1a9ed4d17aeaf1503ec514} 
{\bfseries tap\+\_\+element}
\end{DoxyCompactItemize}

\doxysubsection{Detailed Description}
Main program entry point

Project homepage\+: \href{https://github.com/audiomorphology/Parrot}{\texttt{ https\+://github.\+com/audiomorphology/\+Parrot}} 

\doxysubsection{Function Documentation}
\Hypertarget{parrot__main_8c_a0882689ae327acfabbb12bd78cc7e16d}\index{parrot\_main.c@{parrot\_main.c}!checkReset@{checkReset}}
\index{checkReset@{checkReset}!parrot\_main.c@{parrot\_main.c}}
\doxysubsubsection{\texorpdfstring{checkReset()}{checkReset()}}
{\footnotesize\ttfamily \label{parrot__main_8c_a0882689ae327acfabbb12bd78cc7e16d} 
void check\+Reset (\begin{DoxyParamCaption}{}{}\end{DoxyParamCaption})}

Check for the Rotary Encoder button push. 

This zeroes out the entire delay buffer. Saving and disabling interrupts only works for the core you are in, hence why this is run in parrot\+\_\+main rather than parrot\+\_\+core1

Pulling the XSMT (Soft Mute) pin of the PCM5102 DAC low mutes the output whilst this is happening \Hypertarget{parrot__main_8c_ae66f6b31b5ad750f1fe042a706a4e3d4}\index{parrot\_main.c@{parrot\_main.c}!main@{main}}
\index{main@{main}!parrot\_main.c@{parrot\_main.c}}
\doxysubsubsection{\texorpdfstring{main()}{main()}}
{\footnotesize\ttfamily \label{parrot__main_8c_ae66f6b31b5ad750f1fe042a706a4e3d4} 
int main (\begin{DoxyParamCaption}{}{}\end{DoxyParamCaption})}

Main program entry point. 

Initialise the PSRAM SPI interface, which uses pio0

Start the Audio I2S interface, which uses pio1

\doxysubsection{Variable Documentation}
\Hypertarget{parrot__main_8c_a5d8ff28893901c00f6792c86ecb5bd01}\index{parrot\_main.c@{parrot\_main.c}!divisors@{divisors}}
\index{divisors@{divisors}!parrot\_main.c@{parrot\_main.c}}
\doxysubsubsection{\texorpdfstring{divisors}{divisors}}
{\footnotesize\ttfamily \label{parrot__main_8c_a5d8ff28893901c00f6792c86ecb5bd01} 
float divisors\mbox{[}$\,$\mbox{]} = \{1,2,3,4,5,6,8,12,1,0.\+5,0.\+33333,0.\+25,0.\+2,0.\+166666,0.\+125,0.\+083333\}}

An array of multipliers, which are applied to the master internal or external clock frequency to set the delay time as a multiple of the clock period. 

1/12 1/8 1/6 1/5 1/4 1/3 1/2 1\texorpdfstring{$\ast$}{*} 2\texorpdfstring{$\ast$}{*} 3\texorpdfstring{$\ast$}{*} 4\texorpdfstring{$\ast$}{*} 5\texorpdfstring{$\ast$}{*} 6\texorpdfstring{$\ast$}{*} 8\texorpdfstring{$\ast$}{*} 12\texorpdfstring{$\ast$}{*}

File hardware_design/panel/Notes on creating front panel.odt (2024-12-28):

I created the front panel graphics using Inkscape v1.2

I created two layers – the main layer (Layer 1) has all of the graphics and images on it, and I created a second layer (Knob outlines) that I used as a guide to offset the text and graphics from the knobs themselves.

Creating the switch scale

1. I cloned the following repository: https://github.com/brathering82/inkscape.git into F:\Dev\inkscape
2. Opened the latest release directory (v0.91) and copied render_scale.inx and render_scale.py to: c:\program files\inkscape\share\inkscape\extensions
3. Restarted inkscape
4. Scale generator appears under Extensions > Render

However everything I did generated an error – long python exception.

I tried again, by downloading and installing Synth Panel Designer from here:

https://gitlab.com/Faselunare/synth-panels-designer

In Inkscape go to Edit > Preferences > System and open the User Extensions folder

Create a directory in there called SynthPanelsDesigner & copy everything from the cloned directory into there.

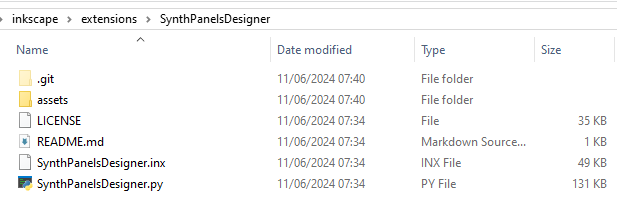
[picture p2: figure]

Restart inkscape

Synth Panels Designer is available under Extensions > Render

To draw a scale, you have to draw a knob first, then select the knob before drawing the scale.

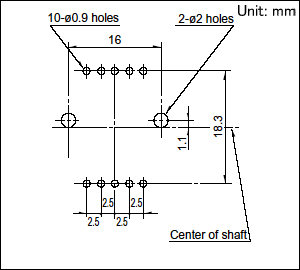
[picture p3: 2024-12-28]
hardware_design/Datasheets/product_detail_fig_srbv_d_12_en_c2e4fef5ce.gif

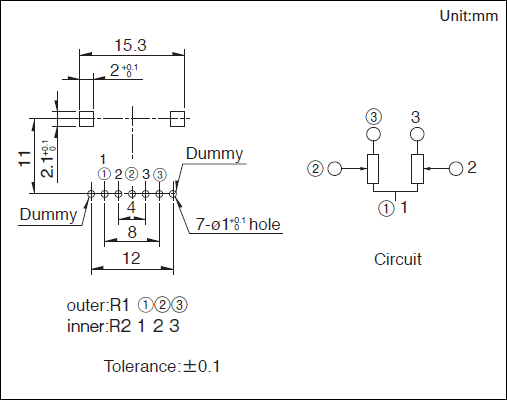
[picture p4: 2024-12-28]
hardware_design/Datasheets/product_detail_fig_rk14k12_d_232_en_cef30a1ba7.gif

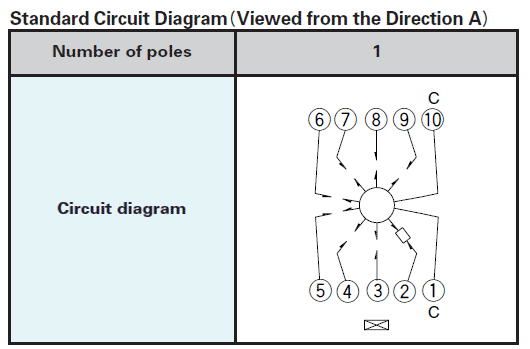
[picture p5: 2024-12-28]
hardware_design/Datasheets/product_detail_fig_srbv_c_17_en_63380587a5.gif

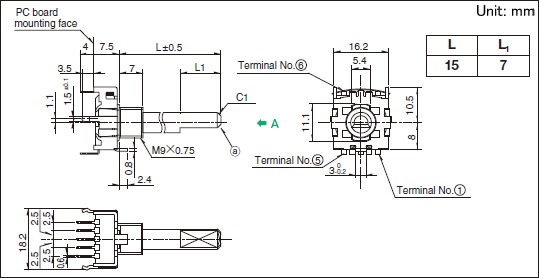
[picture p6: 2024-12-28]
hardware_design/Datasheets/product_detail_fig_srbv_d_11_en_c58a610448.gif

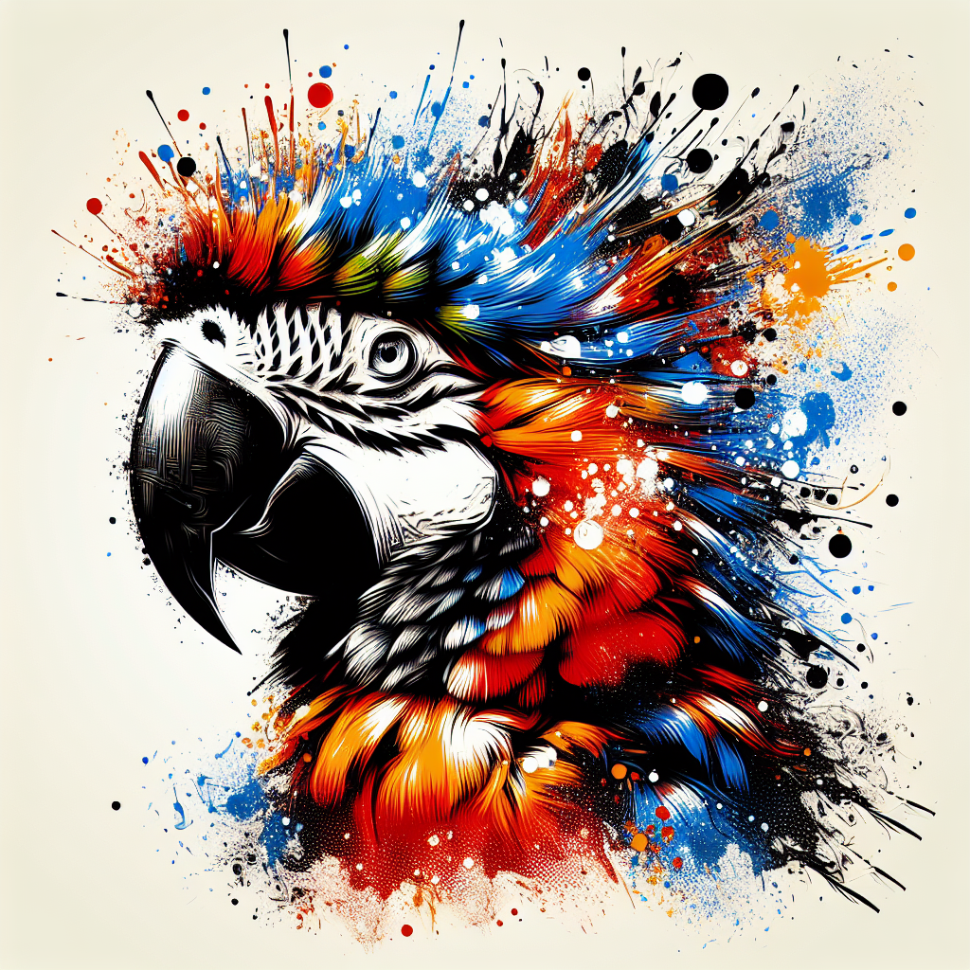
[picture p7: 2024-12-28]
Documentation/tplImga864a88000ac44ddb8c2be08389638ab.png

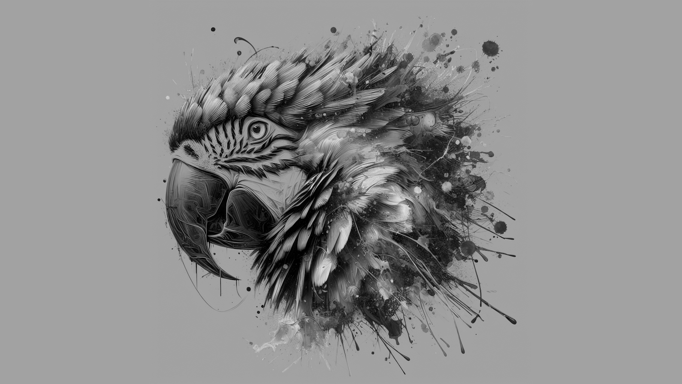
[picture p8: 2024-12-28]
Documentation/Camberwell Parrot 1820x1024 greyscale.png

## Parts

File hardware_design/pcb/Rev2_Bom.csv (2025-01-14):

Reference | Value | Datasheet | Footprint | Qty | DNP
C1,C2 | 47u | ~ | Capacitor_SMD_AKL:CP_Elec_6.3x5.8 | 2
C3,C5,C14,C15,C16,C17 | 100n | ~ | Capacitor_SMD_AKL:C_0603_1608Metric | 6
C4 | 300n | ~ | Capacitor_SMD_AKL:C_0603_1608Metric | 1
C6,C7 | 220p | ~ | Capacitor_SMD_AKL:C_0603_1608Metric | 2
C8,C9,C10,C11 | 10u | ~ | Capacitor_SMD_AKL:CP_Elec_6.3x5.8 | 4
C12,C13 | 18p | ~ | Capacitor_SMD_AKL:C_0603_1608Metric | 2
D1,D2 | 1N5819 | https://www.tme.eu/Document/1dcb17797cd83f32e896ece3030f14cc/1n5817-19.pdf | Diode_THT_AKL:D_DO-41_SOD81_P7.62mm_Horizontal | 2
D7 | LED | ~ | LED_THT:LED_D3.0mm | 1
J1 | Eurorack Power | ~ | Connector_IDC:IDC-Header_2x05_P2.54mm_Vertical | 1
J2,J3,J4,J5,J6,J7 | Thonkiconn |  | Eurorack:Thonkiconn | 6
J9,J12,J14,J16 | Conn_01x10_Pin | ~ | Connector_PinHeader_2.54mm:PinHeader_1x10_P2.54mm_Vertical | 4
J10,J11,J13,J15 | Conn_01x10_Socket | ~ | Connector_PinSocket_2.54mm:PinSocket_1x10_P2.54mm_Vertical | 4
Q1 | DMG2305UX | https://www.tme.eu/Document/79cbea1ac95301c813f57d9a7787c43d/DMG2305UX.pdf | Package_TO_SOT_SMD_AKL:SOT-23 | 1
Q2,Q3 | MMBT3904 | https://www.tme.eu/Document/12bff749841e3a356e683e9a8e7e4119/2N3904BU-DTE.pdf | Package_TO_SOT_SMD_AKL:SOT-23 | 2
Q4 | MMBT3906 | https://www.tme.eu/Document/1d69ece8147fa5a64114d103f531c790/2N3906BU.pdf | Package_TO_SOT_SMD_AKL:SOT-23 | 1
R1 | 330 | ~ | Resistor_SMD_AKL:R_0603_1608Metric_Pad1.05x0.95mm_HandSolder | 1
R2,R3 | 22k | ~ | Resistor_SMD_AKL:R_0603_1608Metric_Pad1.05x0.95mm_HandSolder | 2
R4,R5 | 3.3k | ~ | Resistor_SMD_AKL:R_0603_1608Metric_Pad1.05x0.95mm_HandSolder | 2
R6,R7,R8,R9,R10,R11 | 5.6k | ~ | Resistor_SMD_AKL:R_0603_1608Metric_Pad1.05x0.95mm_HandSolder | 6
R12,R13,R14,R15 | 39k | ~ | Resistor_SMD_AKL:R_0603_1608Metric_Pad1.05x0.95mm_HandSolder | 4
R16,R17,R39,R40 | 1k | ~ | Resistor_SMD_AKL:R_0603_1608Metric_Pad1.05x0.95mm_HandSolder | 4
R18,R41 | 10k | ~ | Resistor_SMD_AKL:R_0603_1608Metric_Pad1.05x0.95mm_HandSolder | 2
R19,R42 | 100k | ~ | Resistor_SMD_AKL:R_0603_1608Metric_Pad1.05x0.95mm_HandSolder | 2
R23,R24,R25,R26,R27,R28,R29,R30,R31,R32,R33,R34,R35,R36,R37,R38 | 4k7 | ~ | Resistor_SMD_AKL:R_0603_1608Metric_Pad1.05x0.95mm_HandSolder | 16
RV1 | PTV112-4420A-A503 | ~ | DSP_CodecBoards:Potentiometer_Bourns_PTV112-4_Dual_Vertical | 1
RV2,RV3,RV4 | B100K | ~ | DSP_CodecBoards:Potentiometer_Alpha_RD901F-40-00D_Single_Vertical_CircularHoles | 3
SW1,SW5 | SW_Rotary_1x8 | ~ | DSP_CodecBoards:ALPS Alpine 8-Way rotary switch SRBV Series | 2
SW2,SW4 | SW_SPST | ~ | europi:SPDT_Switch | 2
SW3 | RotaryEncoder_Switch | ~ | DSP_CodecBoards:RotaryEncoder_Alps_EC11E-Switch_Vertical_H20mm | 1
U1 | Pico |  | MCU_RaspberryPi_and_Boards:RPi_Pico_SMD_TH | 1
U2 | PCM1808 |  | DSP_CodecBoards:PCM1808 | 1
U3,U4 | TL072CD | https://www.ti.com/lit/ds/symlink/tl072h.pdf?ts=1635057479364 | Package_SO_AKL:SO-8_3.9x4.9mm_P1.27mm | 2
U5 | GY_PCM5102A |  | DSP_CodecBoards:GY_PCM5102A | 1
U6 | APS6404L | https://www.espressif.com/sites/default/files/documentation/esp-psram32_datasheet_en.pdf | Package_SO:SOIC-8_3.9x4.9mm_P1.27mm | 1
U7 | L7805 | http://www.st.com/content/ccc/resource/technical/document/datasheet/41/4f/b3/b0/12/d4/47/88/CD00000444.pdf/files/CD00000444.pdf/jcr:content/translations/en.CD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 | DSP_CodecBoards:TO-252-2 with heatsink | 1
U8,U9 | MC14532B |  | Package_SO:SOIC-16_3.9x9.9mm_P1.27mm | 2

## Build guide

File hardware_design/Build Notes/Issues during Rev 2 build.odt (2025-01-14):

Rev 2.0 build 8/Jan/2024

1. The holes in the footprint for the two SPST toggle switches are too small. Annoying, because I hit that problem before but forgot to change the footprint.

I have updated the Europi_SPDT footprint, which is applied to that switch, so now the holes are 1mm

2. I have actually run out of SPST Sub-miniature switches, so need to get some

3. I cannot seem to find my 18pF 0805 capacitors. I must have some somewhere as I used them on Rev 1.0 but need to get some more

4. I am low on 47uF and 10uF Electrolytics

5. I never ordered any 300n caps for th 7805 regulator

6. I could have done with some 20-way female pin sockets – I had to shave down 10-Ways to get them to fit.

7. I could do with a longer shaft on the PTV112-4420A-A503 dual pots.

In the product code 4420 20=20mm – mine *look* like the shaft

Mine look like 20mm *without* bushing, in which case the sfat length is measured from the PCB!! so I prob need 25mm:

PTV112-4425A-A503 (no bushing) or

PTV112-3420A-A503 (with bushing)

Both are really difficult to find!!

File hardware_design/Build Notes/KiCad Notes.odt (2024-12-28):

Various KiCad-related notes.

Looking to assign Footprints

This gets me every time, and I spend ages hunting for how you assign a 3D model to a component / symbol.

- If it is a standard component, then KiCad will probably find it.
- If you need to assign a bespoke 3D model, do the following:
  - Make a copy of the Component in a personal Global footprint Library
  - Open the footprint in the footprint editor
  - Click on File > Footprint Properties
  - 3D Models are added in the 3D Models tab
- NOTE: KiCad seems to be unable to some older libraries

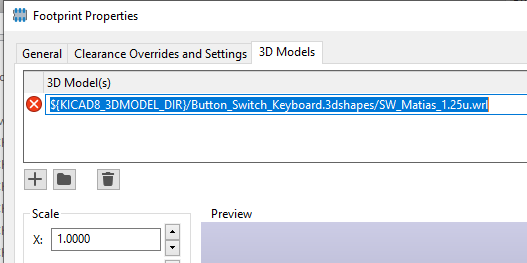
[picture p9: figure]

- The ${KICAD_3DMODEL_DIR} environment variable is pointing to the following location:

C:\Program Files\KiCad\8.0\share\kicad\3dmodels

- The error simply means that there is no .wrl file in that directory

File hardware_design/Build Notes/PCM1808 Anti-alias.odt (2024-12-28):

The PCM1808 ADC has a simple R-C Low-pass anti-aliasing filter on the Left and Right inputs – to my ears this makes the sound a little dull

But it’s simple enough to de-solder the capacitors that sit just before pins 13 & 14 of the PCM1808 IC on the module.

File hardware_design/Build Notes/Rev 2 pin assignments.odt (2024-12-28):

Camberwell Parrot

Rev 2. GPIO / Pin Assignments

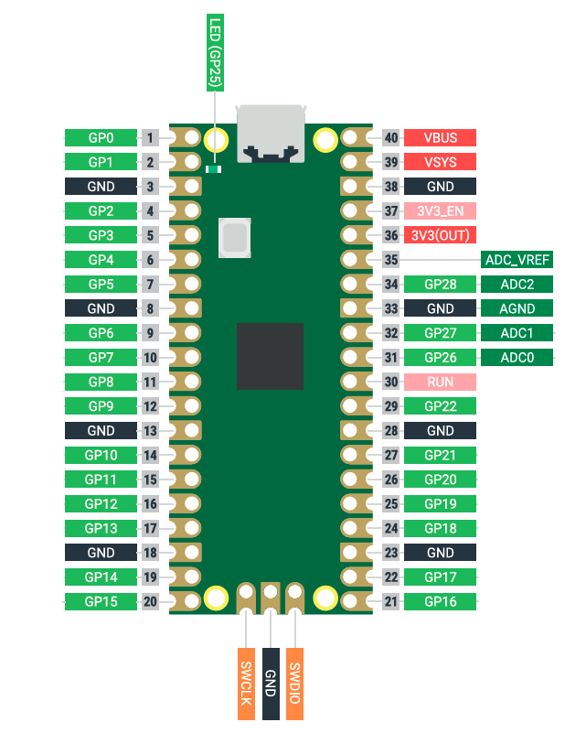
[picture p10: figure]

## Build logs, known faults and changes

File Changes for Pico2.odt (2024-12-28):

The things I had to do to compile for pico 2

- Renamed the f:\dev\tools\pico-sdk-master directory
- Cloned the pico-sdk master from the Raspberry Pi GitHub site
- In CmakeLists.txt added the PICO Board type:
  - set(PICO_BOARD pico)
- in parrot_main.c I needed to add include hardware/clocks.h
  - This is because set_sys_clock_khz has been moved
- Delete the entire contents of the \build directory

Those changes enabled me to recompile for pico1 / rp2040

When I changed the board type to pico2 it initially failed in the function alarm_in_us

- Changed
  - #define ALARM_IRQ TIMER_IRQ_1
  - to
  - #define ALARM_IRQ TIMER1_IRQ_1

To avoid problems in the future I added an #if to parrot.h

#if PICO_RP2040

#define ALARM_IRQ TIMER_IRQ_1

#elif PICO_RP2350

#define ALARM_IRQ TIMER1_IRQ_1

#endif

It then compiled OK, and the board booted, and I can use the PICO_BOARD setting in CMakeLists.txt to switch between the board types.

During initial testing, some functions do appear to work – eg the Audio in and out seem OK, as does the ext_clock input, though I am not getting any delayed signal at all, which makes me think that the PSRAM isn’t functioning.

Checked on Ian Scott’s GitHub, and there was a discussion that pointed to a missing gpio init in psram_spi.pio

pio_gpio_init(pio, pin_miso);

This gets it *much* closer to working, though I’m not convinced about things like the switches.

The wet/dry balance pot is altering the volume of the dry signal, so the ADC seems to be OK.

Definitely some detailed hardware testing required, and I need to build a hardware test harness, but the initial steps are quite encouraging.

Testing results

The * / - switch doesn’t work. Presumably due to the pull-down bug. I am pulling it up to +3.3v, so using the internal pull-down resistor. Safest approach would be to use internal pull-up, and switch to GND

8-Way rotary switch with BCD Encoder works fine, and no internasl pull-up or -down resistors required

Sync / Free switch switches to Ground * works fine (though could do with a de-bounce

Algorithm falls foul of the GPIO Bug, but I’m considering an 8-Way algorithm switch anyway so it’ll get fixed via that. For testing purposes I added external 4k7 pull-down resistors, which fixed the Algorithm switch for testing purposes.

Feedback and Clock speed pots are wired back to front, though that is simply one instruction to reverse them in code, so not important.

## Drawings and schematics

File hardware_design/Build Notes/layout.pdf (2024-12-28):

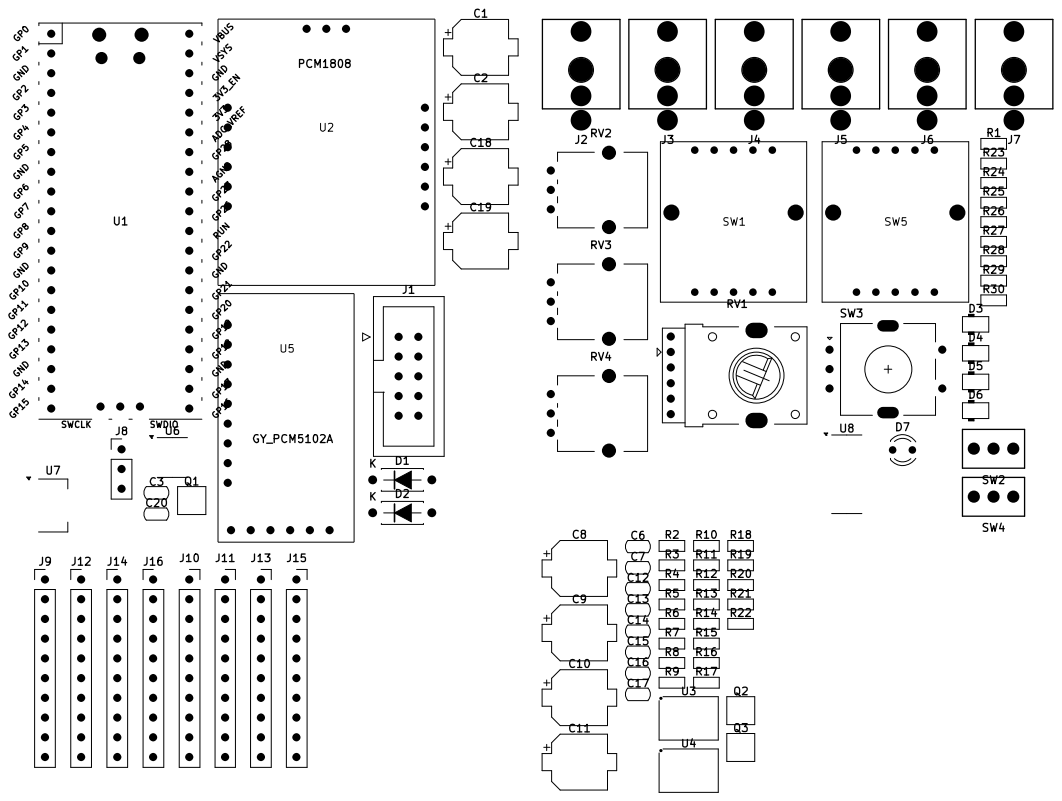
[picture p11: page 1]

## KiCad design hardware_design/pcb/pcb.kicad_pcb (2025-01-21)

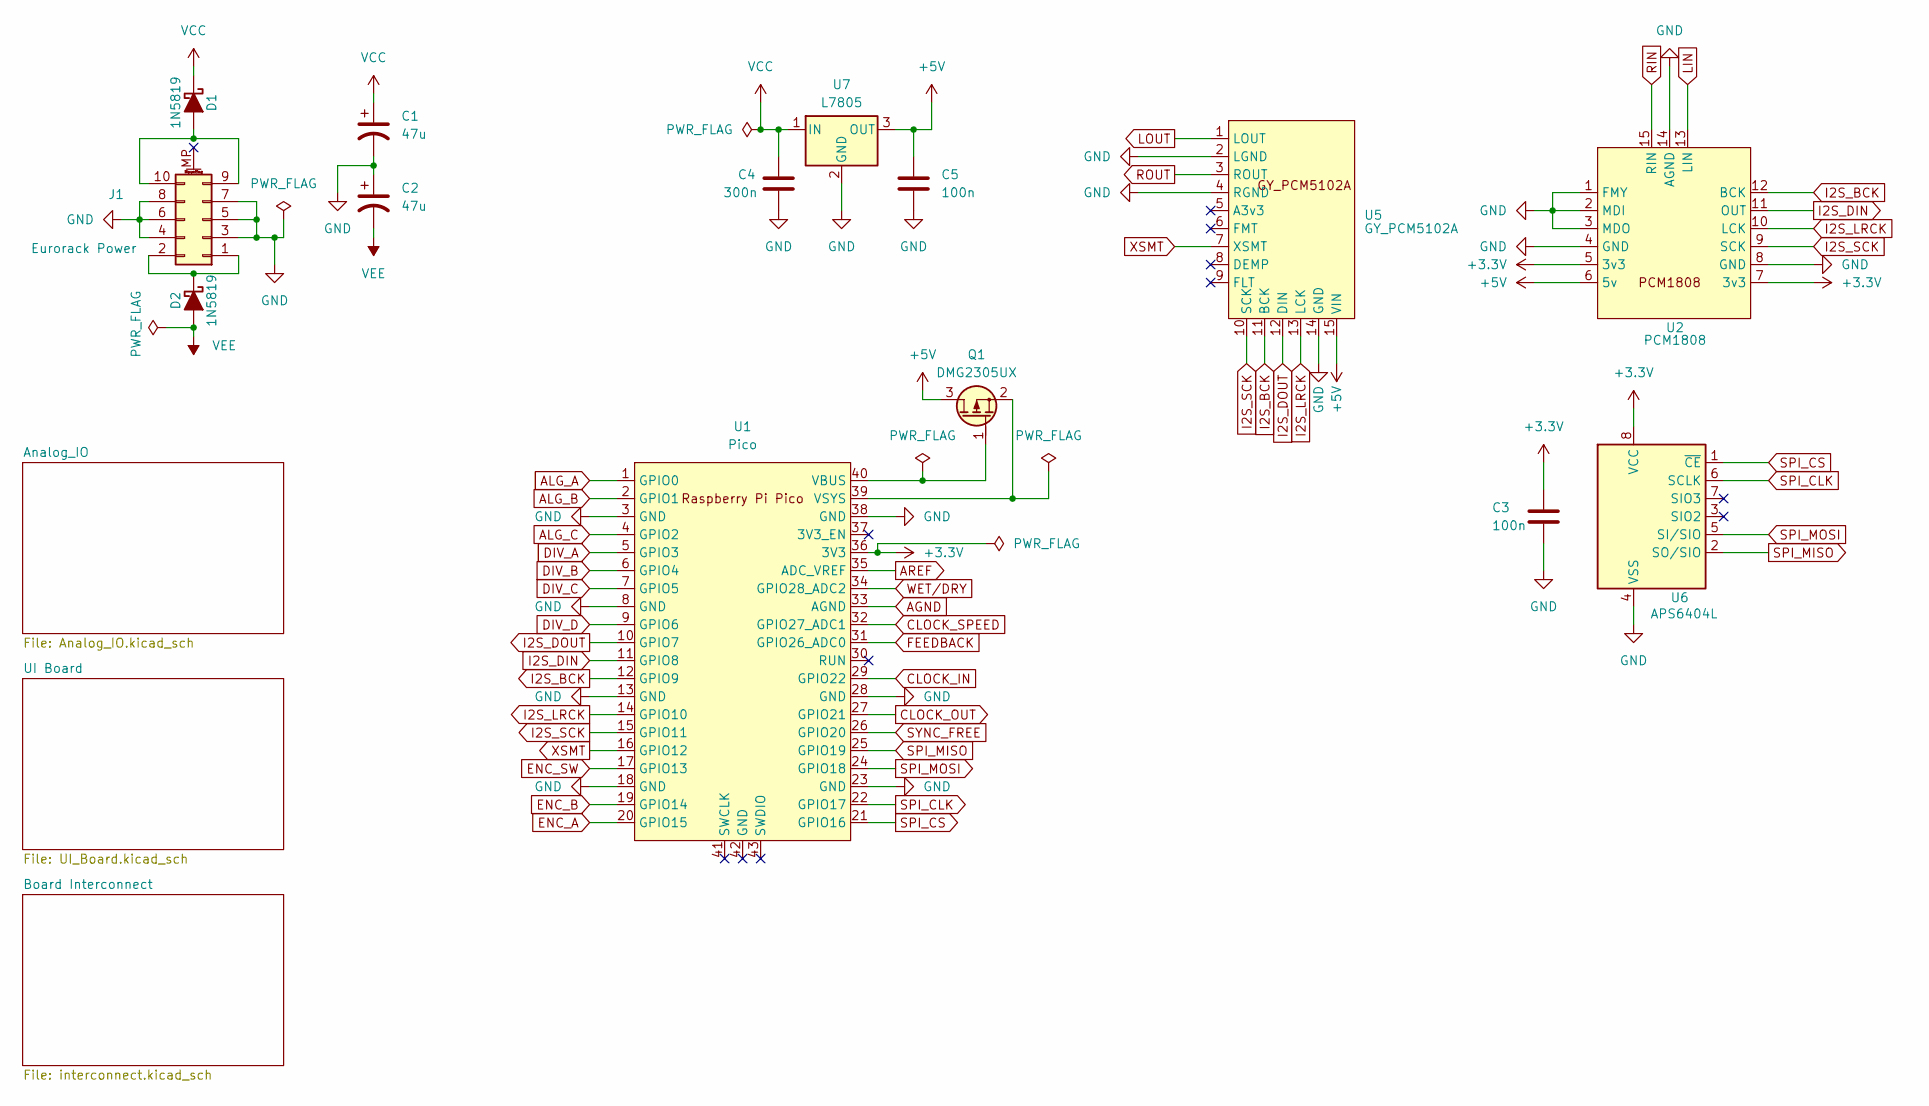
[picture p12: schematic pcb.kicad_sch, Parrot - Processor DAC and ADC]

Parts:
C1, C2: 47u; CP_Elec_6.3x5.8
C3, C5: 100n; C_0603_1608Metric
C4: 300n; C_0603_1608Metric
D1, D2: 1N5819; D_DO-41_SOD81_P7.62mm_Horizontal
J1: Eurorack Power; IDC-Header_2x05_P2.54mm_Vertical
Q1: DMG2305UX; SOT-23
U1: Pico; RPi_Pico_SMD_TH
U2: PCM1808
U5: GY_PCM5102A
U6: APS6404L; SOIC-8_3.9x4.9mm_P1.27mm
U7: L7805; TO-252-2 with heatsink

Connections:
+3.3V: C3.1, U1.36 (3V3), U2.5 (3v3), U2.7 (3v3), U6.8 (VCC); also elsewhere on the board
+5V: C5.1, Q1.3 (D), U2.6 (5v), U5.15 (VIN), U7.3 (OUT)
AGND: U1.33 (AGND); also elsewhere on the board
ALG_A: U1.1 (GPIO0); also elsewhere on the board
ALG_B: U1.2 (GPIO1); also elsewhere on the board
ALG_C: U1.4 (GPIO2); also elsewhere on the board
AREF: U1.35 (ADC_VREF); also elsewhere on the board
CLOCK_IN: U1.29 (GPIO22); also elsewhere on the board
CLOCK_OUT: U1.27 (GPIO21); also elsewhere on the board
CLOCK_SPEED: U1.32 (GPIO27_ADC1); also elsewhere on the board
DIV_A: U1.5 (GPIO3); also elsewhere on the board
DIV_B: U1.6 (GPIO4); also elsewhere on the board
DIV_C: U1.7 (GPIO5); also elsewhere on the board
DIV_D: U1.9 (GPIO6); also elsewhere on the board
ENC_A: U1.20 (GPIO15); also elsewhere on the board
ENC_B: U1.19 (GPIO14); also elsewhere on the board
ENC_SW: U1.17 (GPIO13); also elsewhere on the board
FEEDBACK: U1.31 (GPIO26_ADC0); also elsewhere on the board
GND: C1.2, C2.1, C3.2, C4.2, C5.2, J1.3, J1.4, J1.5, J1.6, J1.7, J1.8, U1.3 (GND), U1.8 (GND), U1.13 (GND), U1.18 (GND), U1.23 (GND), U1.28 (GND), U1.38 (GND), U2.1 (FMY), U2.2 (MDI), U2.3 (MDO), U2.4 (GND), U2.8 (GND), U2.14 (AGND), U5.2 (LGND), U5.4 (RGND), U5.14 (GND), U6.4 (VSS), U7.2 (GND); also elsewhere on the board
I2S_BCK: U1.12 (GPIO9), U2.12 (BCK), U5.11 (BCK)
I2S_DIN: U1.11 (GPIO8), U2.11 (OUT)
I2S_DOUT: U1.10 (GPIO7), U5.12 (DIN)
I2S_LRCK: U1.14 (GPIO10), U2.10 (LCK), U5.13 (LCK)
I2S_SCK: U1.15 (GPIO11), U2.9 (SCK), U5.10 (SCK)
LIN: U2.13 (LIN); also elsewhere on the board
LOUT: U5.1 (LOUT); also elsewhere on the board
unnamed: D1.2 (A), J1.9, J1.10
unnamed: D2.1 (K), J1.1, J1.2
unnamed: Q1.1 (G), U1.40 (VBUS)
unnamed: Q1.2 (S), U1.39 (VSYS)
RIN: U2.15 (RIN); also elsewhere on the board
ROUT: U5.3 (ROUT); also elsewhere on the board
SPI_CLK: U1.22 (GPIO17), U6.6 (SCLK)
SPI_CS: U1.21 (GPIO16), U6.1 (~CE)
SPI_MISO: U1.25 (GPIO19), U6.2 (SO/SIO)
SPI_MOSI: U1.24 (GPIO18), U6.5 (SI/SIO)
SYNC_FREE: U1.26 (GPIO20); also elsewhere on the board
VCC: C1.1, C4.1, D1.1 (K), U7.1 (IN); also elsewhere on the board
VEE: C2.2, D2.2 (A); also elsewhere on the board
WET/DRY: U1.34 (GPIO28_ADC2); also elsewhere on the board
XSMT: U1.16 (GPIO12), U5.7 (XSMT)

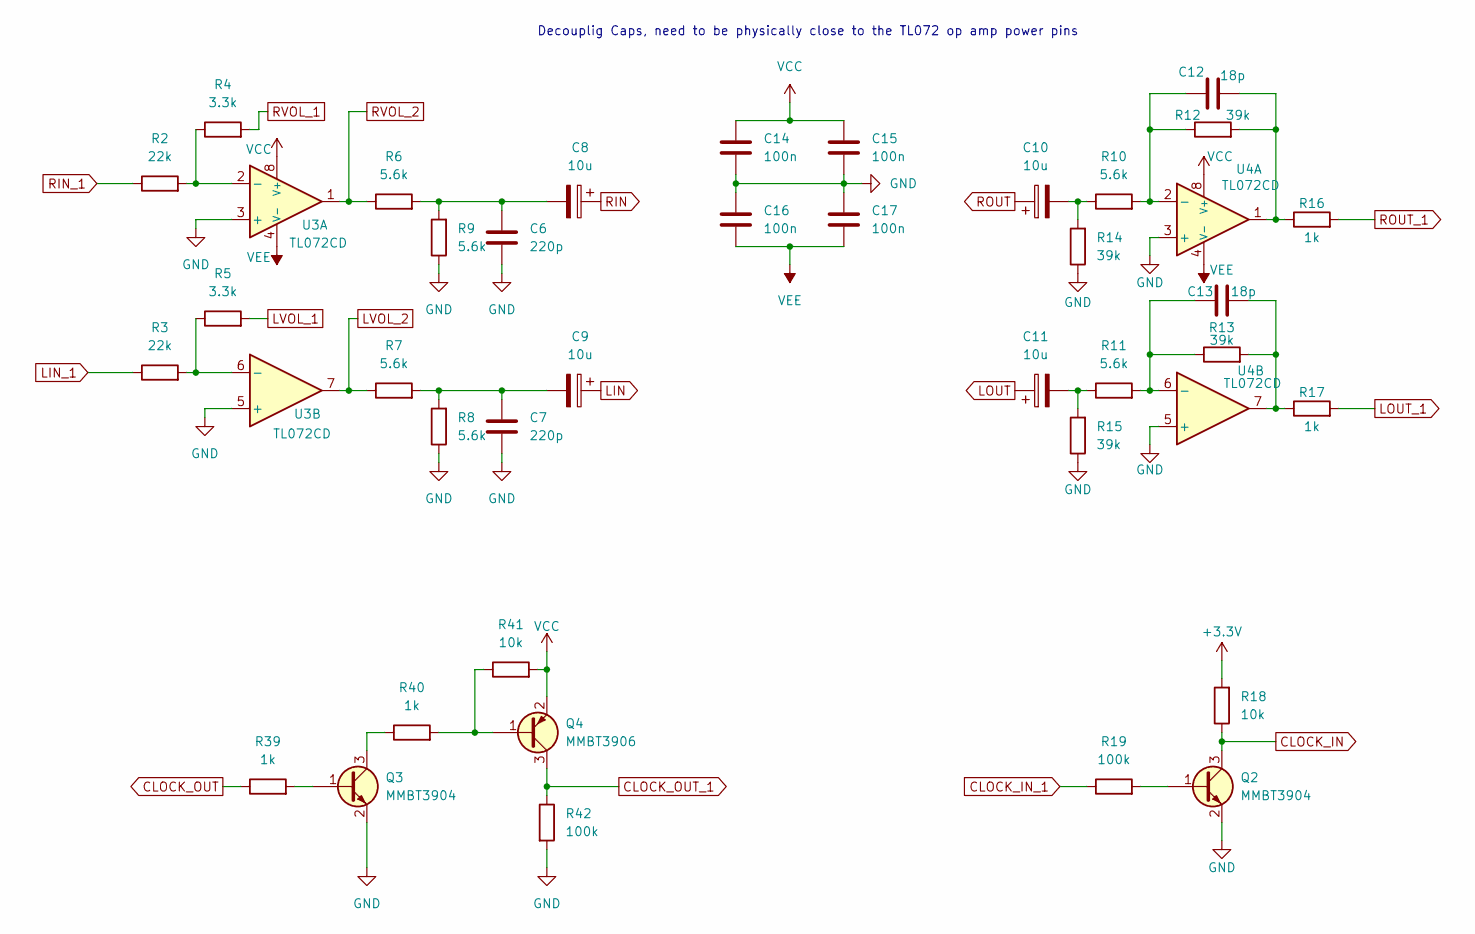
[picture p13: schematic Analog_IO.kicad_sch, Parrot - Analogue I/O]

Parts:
C6, C7: 220p; C_0603_1608Metric
C8, C9, C10, C11: 10u; CP_Elec_6.3x5.8
C12, C13: 18p; C_0603_1608Metric
C14, C15, C16, C17: 100n; C_0603_1608Metric
Q2, Q3: MMBT3904; SOT-23
Q4: MMBT3906; SOT-23
R2, R3: 22k; R_0603_1608Metric_Pad1.05x0.95mm_HandSolder
R4, R5: 3.3k; R_0603_1608Metric_Pad1.05x0.95mm_HandSolder
R6, R7, R8, R9, R10, R11: 5.6k; R_0603_1608Metric_Pad1.05x0.95mm_HandSolder
R12, R13, R14, R15: 39k; R_0603_1608Metric_Pad1.05x0.95mm_HandSolder
R16, R17, R39, R40: 1k; R_0603_1608Metric_Pad1.05x0.95mm_HandSolder
R18, R41: 10k; R_0603_1608Metric_Pad1.05x0.95mm_HandSolder
R19, R42: 100k; R_0603_1608Metric_Pad1.05x0.95mm_HandSolder
U3, U4: TL072CD; SO-8_3.9x4.9mm_P1.27mm

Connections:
+3.3V: R18.2; also elsewhere on the board
CLOCK_IN: Q2.3 (C), R18.1; also elsewhere on the board
CLOCK_IN_1: R19.1; also elsewhere on the board
CLOCK_OUT: R39.1; also elsewhere on the board
CLOCK_OUT_1: Q4.3 (C), R42.1; also elsewhere on the board
GND: C6.2, C7.2, C14.2, C15.2, C16.1, C17.1, Q2.2 (E), Q3.2 (E), R8.1, R9.1, R14.1, R15.1, R42.2, U3.3 (+), U3.5 (+), U4.3 (+), U4.5 (+); also elsewhere on the board
LIN: C9.1; also elsewhere on the board
LIN_1: R3.1; also elsewhere on the board
LOUT: C11.1; also elsewhere on the board
LOUT_1: R17.2; also elsewhere on the board
LVOL_1: R5.2; also elsewhere on the board
LVOL_2: R7.1, U3.7; also elsewhere on the board
unnamed: C6.1, C8.2, R6.2, R9.2
unnamed: C7.1, C9.2, R7.2, R8.2
unnamed: C10.2, R10.1, R14.2
unnamed: C11.2, R11.1, R15.2
unnamed: C12.2, R12.2, R16.1, U4.1
unnamed: C13.2, R13.2, R17.1, U4.7
unnamed: Q2.1 (B), R19.2
unnamed: Q3.1 (B), R39.2
unnamed: Q3.3 (C), R40.1
unnamed: Q4.1 (B), R40.2, R41.1
unnamed: R2.2, R4.1, U3.2 (-)
unnamed: R3.2, R5.1, U3.6 (-)
unnamed: C12.1, R10.2, R12.1, U4.2 (-)
unnamed: C13.1, R11.2, R13.1, U4.6 (-)
RIN: C8.1; also elsewhere on the board
RIN_1: R2.1; also elsewhere on the board
ROUT: C10.1; also elsewhere on the board
ROUT_1: R16.2; also elsewhere on the board
RVOL_1: R4.2; also elsewhere on the board
RVOL_2: R6.1, U3.1; also elsewhere on the board
VCC: C14.1, C15.1, Q4.2 (E), R41.2, U3.8 (V+), U4.8 (V+); also elsewhere on the board
VEE: C16.2, C17.2, U3.4 (V-), U4.4 (V-); also elsewhere on the board

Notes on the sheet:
Decouplig Caps, need to be physically close to the TL072 op amp power pins

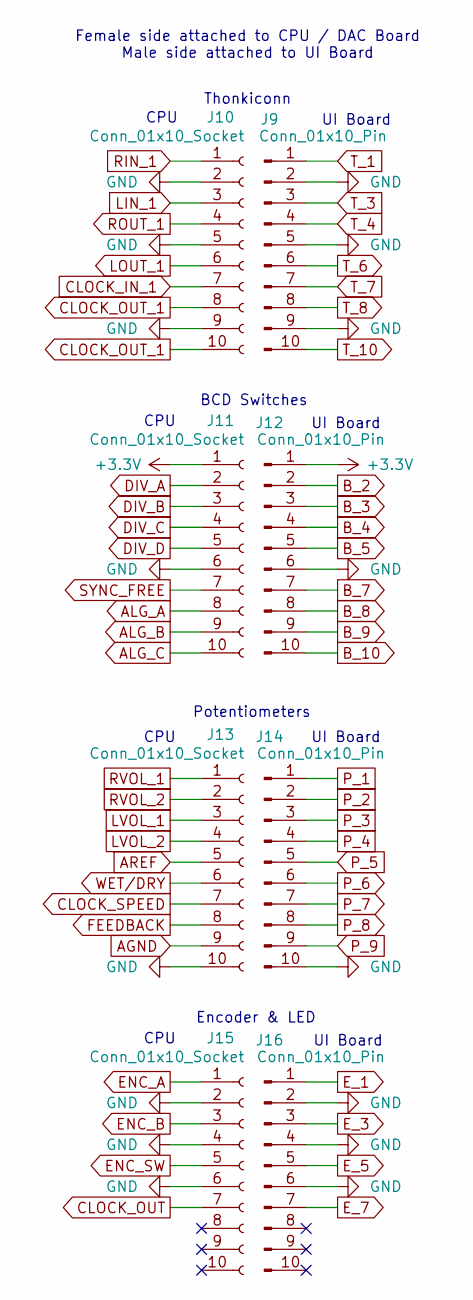
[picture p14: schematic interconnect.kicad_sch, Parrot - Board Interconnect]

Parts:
J9, J12, J14, J16: Conn_01x10_Pin; PinHeader_1x10_P2.54mm_Vertical
J10, J11, J13, J15: Conn_01x10_Socket; PinSocket_1x10_P2.54mm_Vertical

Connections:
+3.3V: J11.1, J12.1; also elsewhere on the board
AGND: J13.9; also elsewhere on the board
ALG_A: J11.8; also elsewhere on the board
ALG_B: J11.9; also elsewhere on the board
ALG_C: J11.10; also elsewhere on the board
AREF: J13.5; also elsewhere on the board
B_2: J12.2; also elsewhere on the board
B_3: J12.3; also elsewhere on the board
B_4: J12.4; also elsewhere on the board
B_5: J12.5; also elsewhere on the board
B_7: J12.7; also elsewhere on the board
B_8: J12.8; also elsewhere on the board
B_9: J12.9; also elsewhere on the board
B_10: J12.10; also elsewhere on the board
CLOCK_IN_1: J10.7; also elsewhere on the board
CLOCK_OUT: J15.7; also elsewhere on the board
CLOCK_OUT_1: J10.8, J10.10; also elsewhere on the board
CLOCK_SPEED: J13.7; also elsewhere on the board
DIV_A: J11.2; also elsewhere on the board
DIV_B: J11.3; also elsewhere on the board
DIV_C: J11.4; also elsewhere on the board
DIV_D: J11.5; also elsewhere on the board
ENC_A: J15.1; also elsewhere on the board
ENC_B: J15.3; also elsewhere on the board
ENC_SW: J15.5; also elsewhere on the board
E_1: J16.1; also elsewhere on the board
E_3: J16.3; also elsewhere on the board
E_5: J16.5; also elsewhere on the board
E_7: J16.7; also elsewhere on the board
FEEDBACK: J13.8; also elsewhere on the board
GND: J9.2, J9.5, J9.9, J10.2, J10.5, J10.9, J11.6, J12.6, J13.10, J14.10, J15.2, J15.4, J15.6, J16.2, J16.4, J16.6; also elsewhere on the board
LIN_1: J10.3; also elsewhere on the board
LOUT_1: J10.6; also elsewhere on the board
LVOL_1: J13.3; also elsewhere on the board
LVOL_2: J13.4; also elsewhere on the board
P_1: J14.1; also elsewhere on the board
P_2: J14.2; also elsewhere on the board
P_3: J14.3; also elsewhere on the board
P_4: J14.4; also elsewhere on the board
P_5: J14.5; also elsewhere on the board
P_6: J14.6; also elsewhere on the board
P_7: J14.7; also elsewhere on the board
P_8: J14.8; also elsewhere on the board
P_9: J14.9; also elsewhere on the board
RIN_1: J10.1; also elsewhere on the board
ROUT_1: J10.4; also elsewhere on the board
RVOL_1: J13.1; also elsewhere on the board
RVOL_2: J13.2; also elsewhere on the board
SYNC_FREE: J11.7; also elsewhere on the board
T_1: J9.1; also elsewhere on the board
T_3: J9.3; also elsewhere on the board
T_4: J9.4; also elsewhere on the board
T_6: J9.6; also elsewhere on the board
T_7: J9.7; also elsewhere on the board
T_8: J9.8; also elsewhere on the board
T_10: J9.10; also elsewhere on the board
WET/DRY: J13.6; also elsewhere on the board

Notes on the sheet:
Encoder & LED
UI Board
Potentiometers
CPU
Thonkiconn
BCD Switches
Female side attached to CPU / DAC Board Male side attached to UI Board

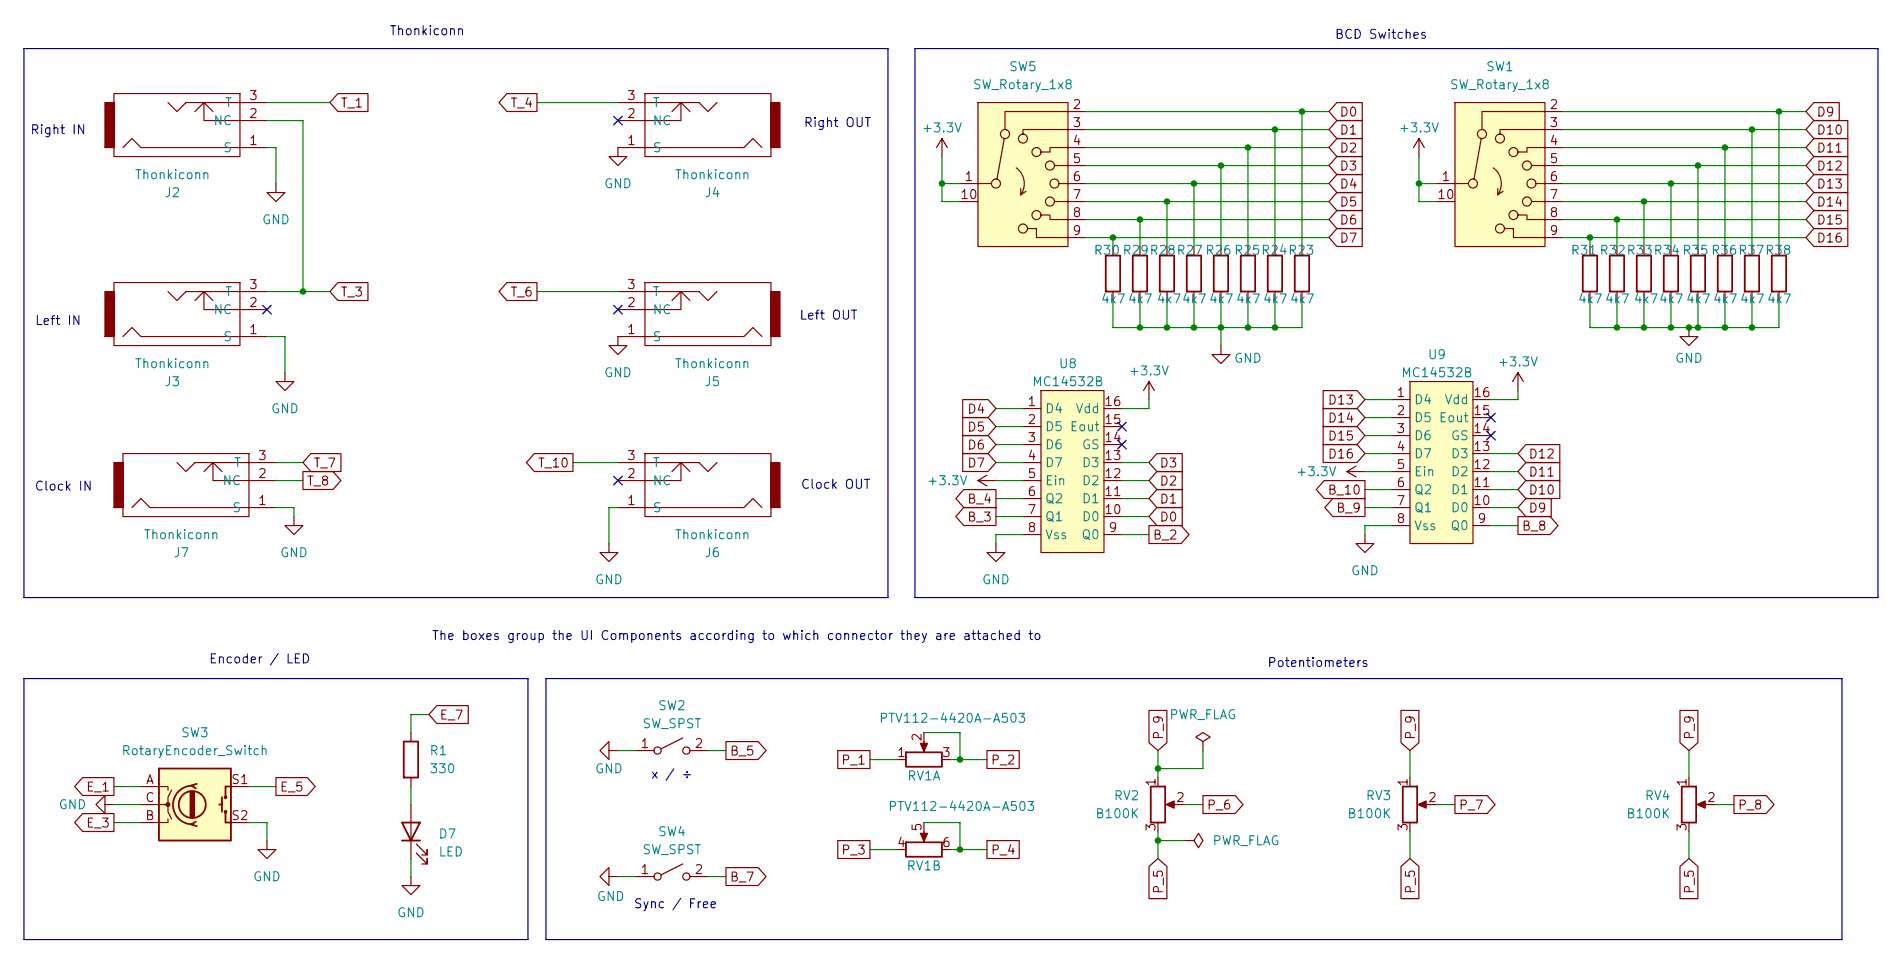
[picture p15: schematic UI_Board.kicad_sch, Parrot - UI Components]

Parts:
D7: LED; LED_D3.0mm
J2, J3, J4, J5, J6, J7: Thonkiconn
R1: 330; R_0603_1608Metric_Pad1.05x0.95mm_HandSolder
R23, R24, R25, R26, R27, R28, R29, R30, R31, R32, R33, R34, R35, R36, R37, R38: 4k7; R_0603_1608Metric_Pad1.05x0.95mm_HandSolder
RV1: PTV112-4420A-A503; Potentiometer_Bourns_PTV112-4_Dual_Vertical
RV2, RV3, RV4: B100K; Potentiometer_Alpha_RD901F-40-00D_Single_Vertical_CircularH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
SW1, SW5: SW_Rotary_1x8; ALPS Alpine 8-Way rotary switch SRBV Series
SW2, SW4: SW_SPST; SPDT_Switch
SW3: RotaryEncoder_Switch; RotaryEncoder_Alps_EC11E-Switch_Vertical_H20mm
U8, U9: MC14532B; SOIC-16_3.9x9.9mm_P1.27mm

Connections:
+3.3V: SW1.1, SW1.10, SW5.1, SW5.10, U8.5 (Ein), U8.16 (Vdd), U9.5 (Ein), U9.16 (Vdd); also elsewhere on the board
B_2: U8.9 (Q0); also elsewhere on the board
B_3: U8.7 (Q1); also elsewhere on the board
B_4: U8.6 (Q2); also elsewhere on the board
B_5: SW2.2 (B); also elsewhere on the board
B_7: SW4.2 (B); also elsewhere on the board
B_8: U9.9 (Q0); also elsewhere on the board
B_9: U9.7 (Q1); also elsewhere on the board
B_10: U9.6 (Q2); also elsewhere on the board
D0: R23.1, SW5.2, U8.10 (D0)
D1: R24.1, SW5.3, U8.11 (D1)
D2: R25.1, SW5.4, U8.12 (D2)
D3: R26.1, SW5.5, U8.13 (D3)
D4: R27.1, SW5.6, U8.1 (D4)
D5: R28.1, SW5.7, U8.2 (D5)
D6: R29.1, SW5.8, U8.3 (D6)
D7: R30.1, SW5.9, U8.4 (D7)
D9: R38.1, SW1.2, U9.10 (D0)
D10: R37.1, SW1.3, U9.11 (D1)
D11: R36.1, SW1.4, U9.12 (D2)
D12: R35.1, SW1.5, U9.13 (D3)
D13: R34.1, SW1.6, U9.1 (D4)
D14: R33.1, SW1.7, U9.2 (D5)
D15: R32.1, SW1.8, U9.3 (D6)
D16: R31.1, SW1.9, U9.4 (D7)
E_1: SW3.A; also elsewhere on the board
E_3: SW3.B; also elsewhere on the board
E_5: SW3.S1; also elsewhere on the board
E_7: R1.1; also elsewhere on the board
GND: D7.1 (K), J2.1 (S), J3.1 (S), J4.1 (S), J5.1 (S), J6.1 (S), J7.1 (S), R23.2, R24.2, R25.2, R26.2, R27.2, R28.2, R29.2, R30.2, R31.2, R32.2, R33.2, R34.2, R35.2, R36.2, R37.2, R38.2, SW2.1 (A), SW3.C, SW3.S2, SW4.1 (A), U8.8 (Vss), U9.8 (Vss); also elsewhere on the board
unnamed: D7.2 (A), R1.2
P_1: RV1.1; also elsewhere on the board
P_2: RV1.2, RV1.3; also elsewhere on the board
P_3: RV1.4; also elsewhere on the board
P_4: RV1.5, RV1.6; also elsewhere on the board
P_5: RV2.3, RV3.3, RV4.3; also elsewhere on the board
P_6: RV2.2; also elsewhere on the board
P_7: RV3.2; also elsewhere on the board
P_8: RV4.2; also elsewhere on the board
P_9: RV2.1, RV3.1, RV4.1; also elsewhere on the board
T_1: J2.3 (T); also elsewhere on the board
T_3: J2.2 (NC), J3.3 (T); also elsewhere on the board
T_4: J4.3 (T); also elsewhere on the board
T_6: J5.3 (T); also elsewhere on the board
T_7: J7.3 (T); also elsewhere on the board
T_8: J7.2 (NC); also elsewhere on the board
T_10: J6.3 (T); also elsewhere on the board

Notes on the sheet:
BCD Switches
Clock OUT
The boxes group the UI Components according to which connector they are attached to
Potentiometers
Encoder / LED
Clock IN
Thonkiconn
x / ÷
Sync / Free
Right IN
Right OUT
Left IN
Left OUT

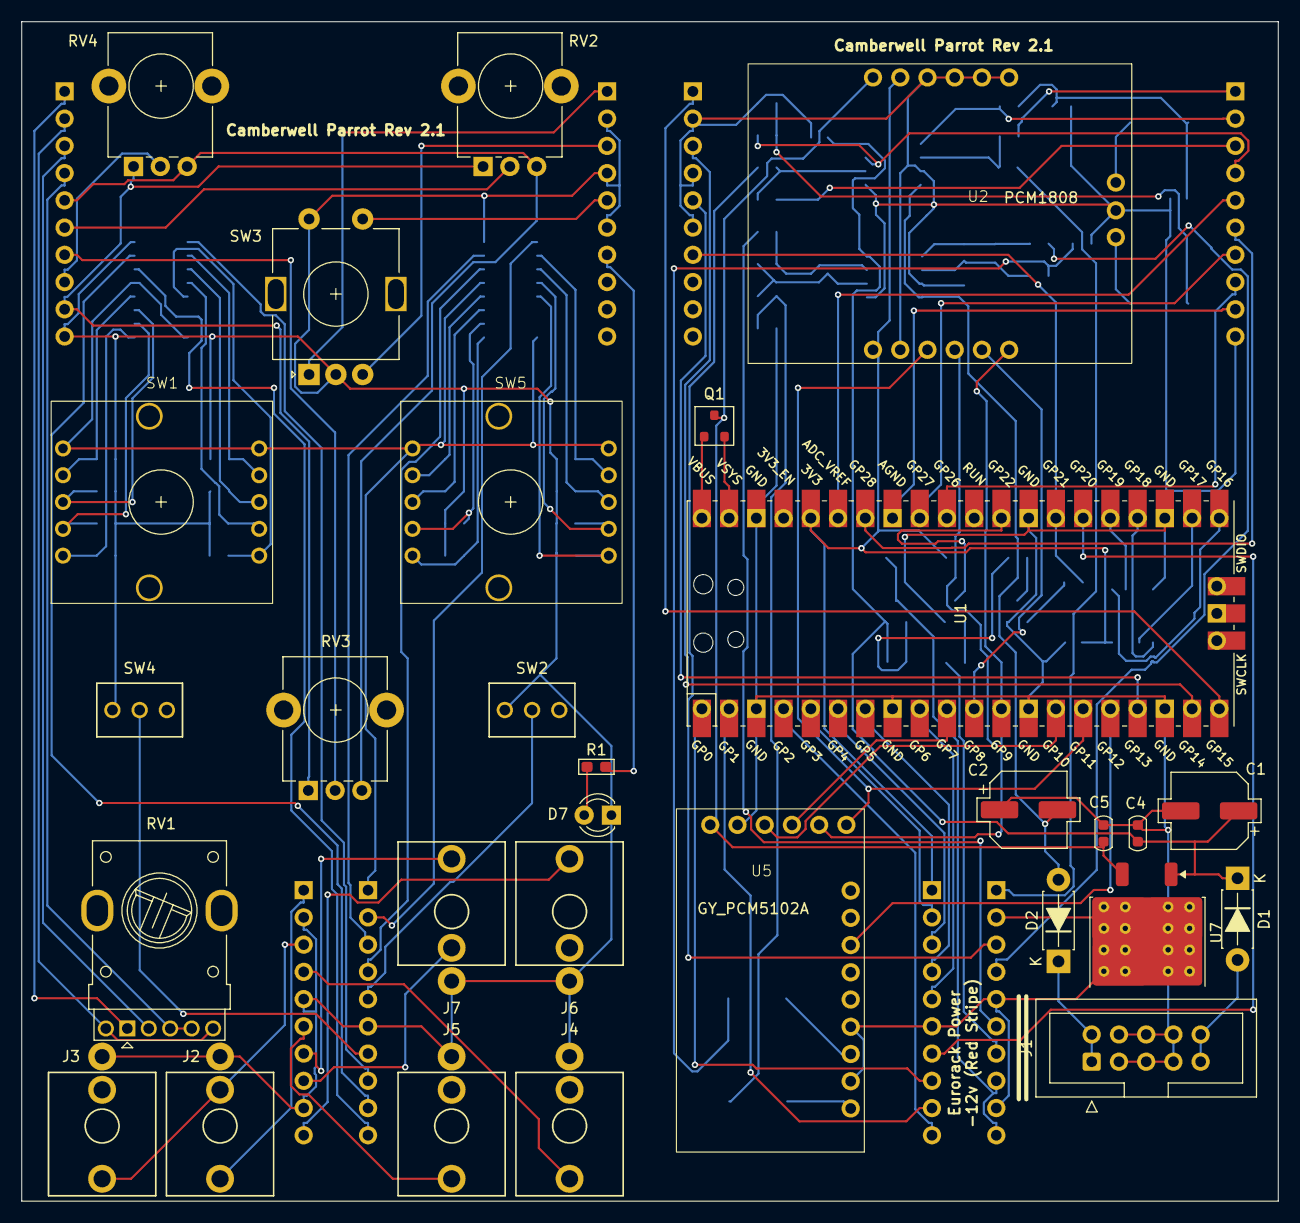
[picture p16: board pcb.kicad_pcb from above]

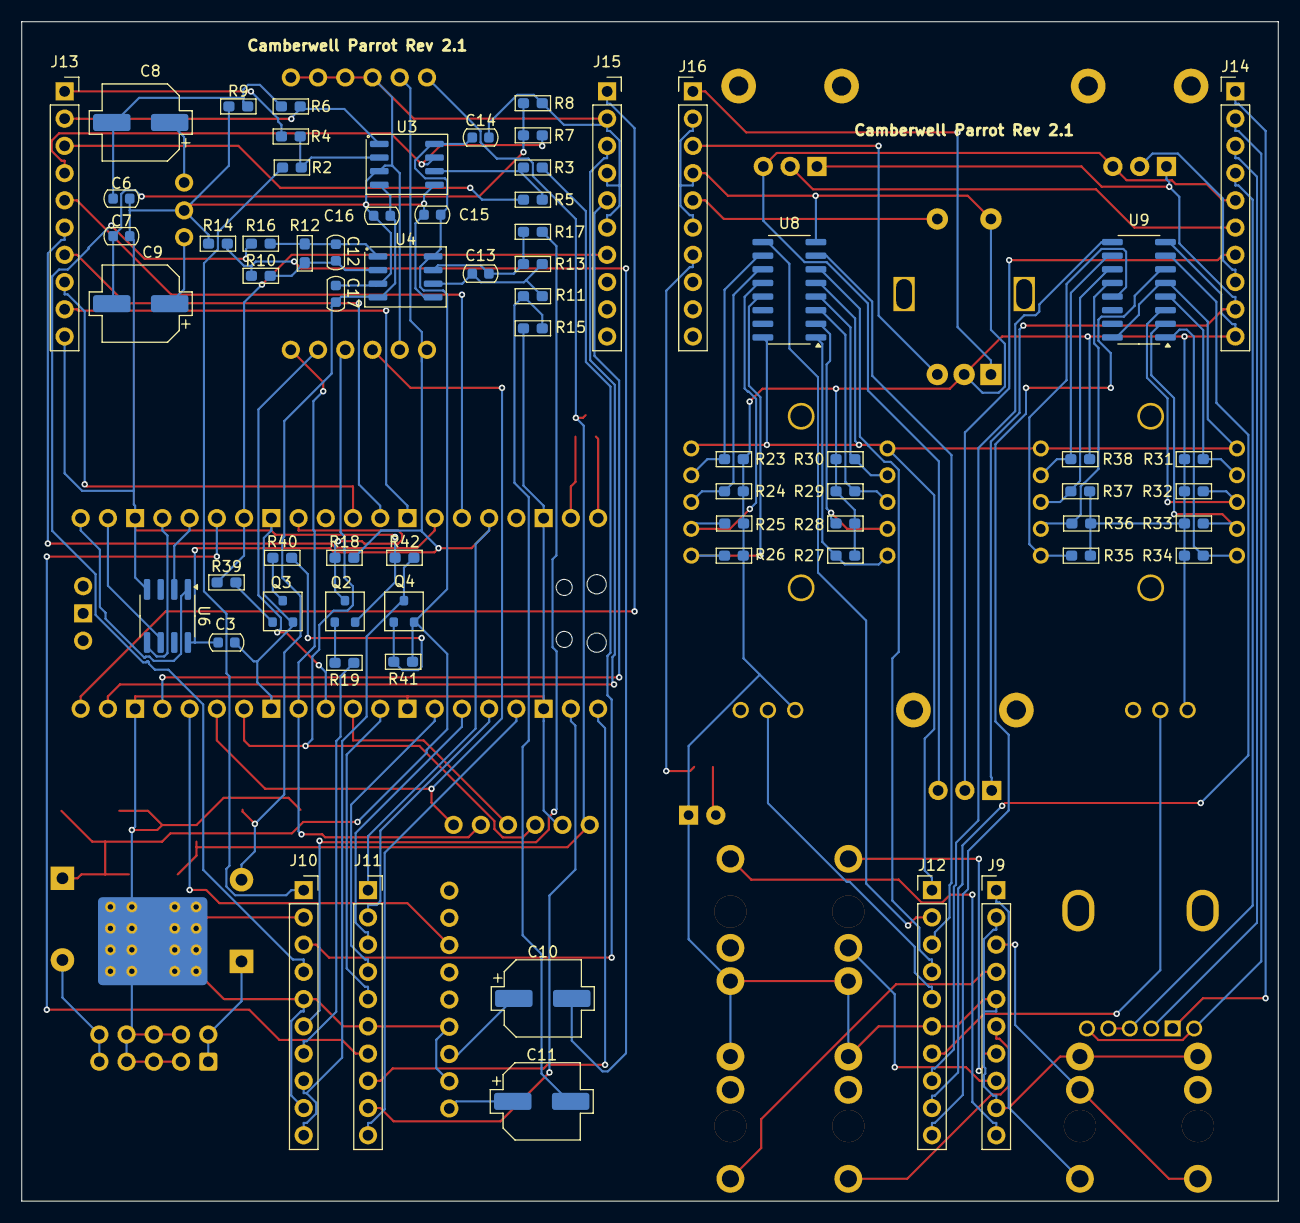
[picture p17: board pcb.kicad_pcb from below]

Board: 2 copper layers, 117.2 x 110.0 mm, 96 parts (67 on the bottom side), 110 nets.

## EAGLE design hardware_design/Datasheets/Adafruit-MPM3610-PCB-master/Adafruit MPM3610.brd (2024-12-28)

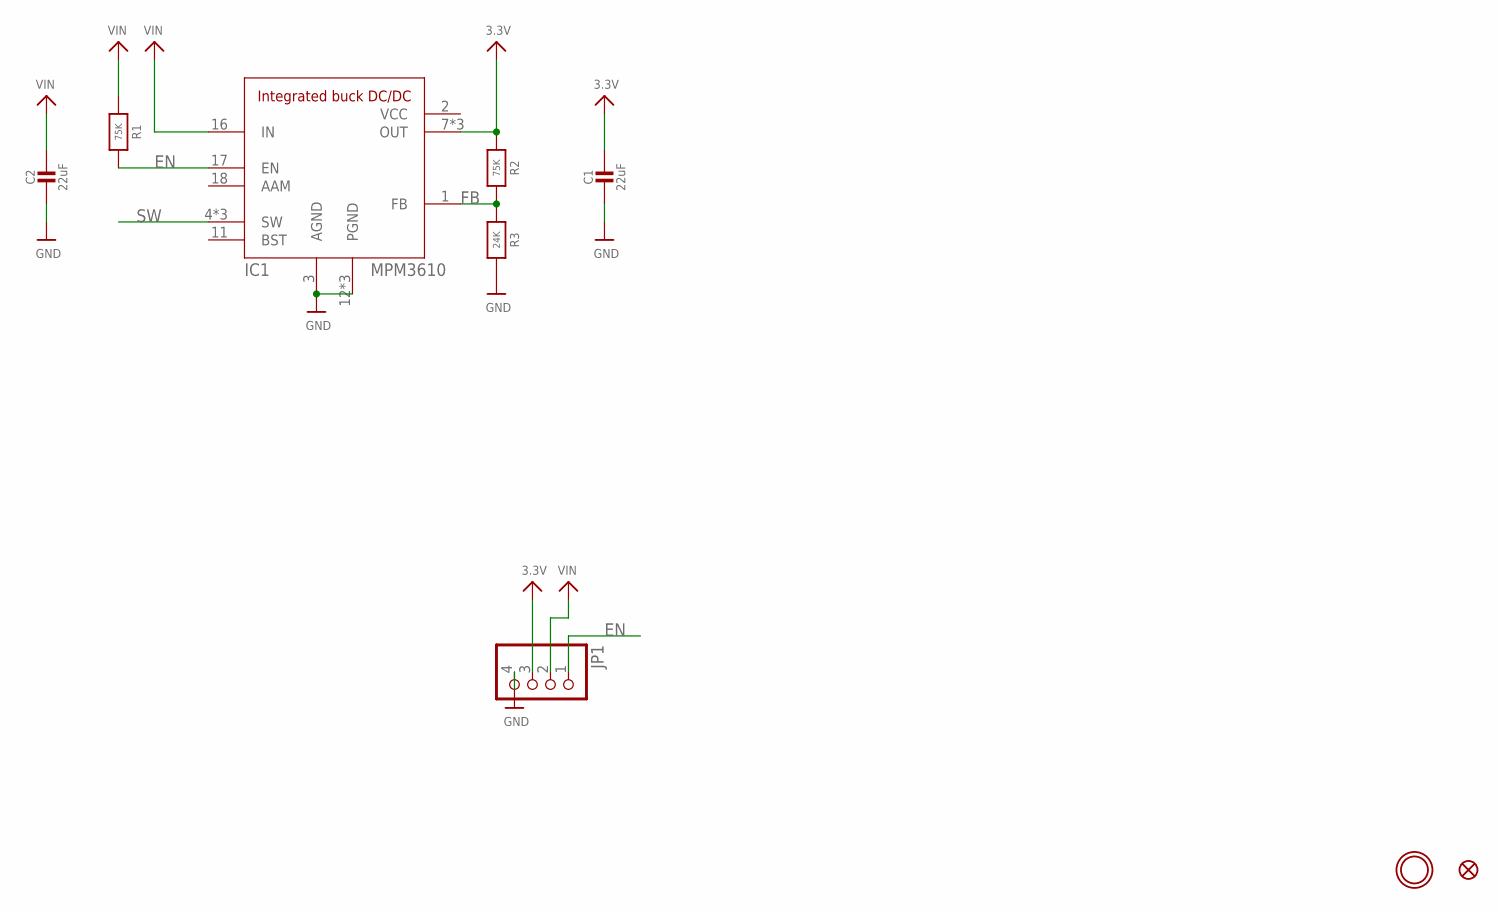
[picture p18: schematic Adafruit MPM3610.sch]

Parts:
C1, C2: 22uF; 0805-NO
FID1: FIDUCIAL_1MM
IC1: MPM3610
JP1: HEADER-1X4ROUND; 1X04_ROUND
R1, R2: 75K; 0603-NO
R3: 24K; 0603-NO
U$9: MOUNTINGHOLE2.5; MOUNTINGHOLE_2.5_PLATED

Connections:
3.3V: C1.1, IC1.7 (OUT), IC1.8 (OUT), IC1.9 (OUT), JP1.3, R2.1
EN: IC1.17 (EN), JP1.1, R1.2
FB: IC1.1 (FB), R2.2, R3.1
GND: C1.2, C2.2, IC1.3 (AGND), IC1.12 (PGND), IC1.13 (PGND), IC1.14 (PGND), JP1.4, R3.2
SW: IC1.4 (SW), IC1.5 (SW), IC1.6 (SW)
VCC: IC1.2 (VCC)
VIN: C2.1, IC1.16 (IN), JP1.2, R1.1

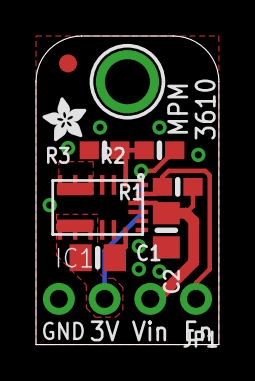
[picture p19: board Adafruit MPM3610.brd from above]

Board: 2 copper layers, 10.2 x 17.1 mm, 11 parts (1 on the bottom side), 6 nets.

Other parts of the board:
U$10: PCBFEAT-REV-040
U$11: ADAFRUIT_2.5MM

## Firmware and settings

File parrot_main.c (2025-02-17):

/******************************************************************************

The Camberwell Parrot

Copyright © 2024 Richard R. Goodwin / Audio Morphology Ltd.

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
******************************************************************************/
/**
 * @file parrot_main.c
 * 
 * Main program entry point
 * 
 * Project homepage: https://github.com/audiomorphology/ParrotRev2
 */

#include <stdio.h>
#include "parrot.h"
#include "pico/stdlib.h"
#include "pico/multicore.h"
#include "malloc.h"
#include "hardware/dma.h"
#include "hardware/adc.h"
#include "hardware/clocks.h"
#include "i2s/i2s.h"
#include "psram_spi.h"
#include "hardware/sync.h"
#include "arm_math.h"
#include "freeverb/freeverb.h"
#include "gverb/include/gverbdsp.h"
#include "gverb/include/gverb.h"
#include "pverb/pverb.h"

// There are separate Read pointers for 
// Left and Right channels, though only one 
// write pointer, as everythign is written to 
// a single here-and-now position, but read
// accoring to differing delays Left and Right
uint32_t ReadPointer_L = 0;         
uint32_t ReadPointer_R = 0;
uint32_t WritePointer = 0;
float glbAllPassState = 0.0f;       // holds the previous value
float glbAPPO_L1 = 0.0f;            // AllPass filter 1 previous output (Left)
float glbAPPO_L2 = 0.0f;            // AllPass filter 1 previous output (Left)
float glbAPPO_L3 = 0.0f;            // AllPass filter 1 previous output (Left)
float glbAPPO_R1 = 0.0f;            // AllPass filter 1 previous output (Right)
float glbAPPO_R2 = 0.0f;            // AllPass filter 1 previous output (Right)
float glbAPPO_R3 = 0.0f;            // AllPass filter 1 previous output (Right)

float glbWet = 0;                   // wet/dry multipliers                   
float glbDry = 1;                   // Between 0 and 1
float glbFeedback = 0.1;            // Global feedback level (between 0 and 1)
float glbRatio = 1.00;              // Global Clock Multiplication / Division ratio
int glbDivisor;                     // Global value for the mul/div switch (0 to 15)
int glbAlgorithm;                   // Global value for Algorithm switch used by other functions
int glbEncoderSw;                   // Global value for Encoder Switch used by other functions
int LatestEncoderSw = 0;            // latest value for the Encoder Switch
uint64_t EncoderSwChangedTime;      // Time at which the Encoder Switch last changed

uint64_t DeBounceTime = 200000;     // Switch Debounce time in uS

uint32_t encoder_tick = 0;

uint32_t glbDelay_L;                // The actual current Delay (in Samples) Left Channel
uint32_t glbDelay_R;                // The actual current Delay (in Samples) Right Channel
uint32_t targetDelay_L;             // The target Delay (in samples) - glbDelay will ramp towards this value
uint32_t targetDelay_R;             // The target Delay (in samples) - glbDelay will ramp towards this value
int32_t PreviousClockPeriod = 0;    //
uint32_t glbIncrement = 1;          // How many samples the delay is increased or decreased by via the rotary encoder
int glbEuclideanFill;               // How many steps are ASctive within the step length
int spinlock_num_glbDelay;          // used to store the number of the spinlock
spin_lock_t *spinlock_glbDelay;     // Used to lock access to glbDelay
ty_gverb * parrot_gverb;
fv_Context parrot_freeverb;
pv_Context parrot_pverb;

/**
 * @brief An array of multipliers, which are applied to the master internal
 * or external clock frequency to set the delay time as a multiple of the clock period
 * 
 * With just an 8-Way switch plus a multiply/divide switch, there are only 15 possible 
 * values, so I've chosen the most common musically-relevant values
 * 
 * 1/12 1/9 1/8 1/6 1/4 1/3 1/2 1* 2* 3* 4* 6* 8* 9* 12*
 */
float divisors[] = {1.0,2.0,3.0,4.0,6.0,8.0,9.0,12.0,1.0,0.5,0.333333,0.25,0.166666,0.125,0.111111,0.083333};
int EuclideanSteps[] = {1,2,3,4,6,8,9,12,1,2,3,4,6,8,9,12};
int EuclideanHits[12];

psram_spi_inst_t* async_spi_inst;
psram_spi_inst_t psram_spi;

static __attribute__((aligned(8))) pio_i2s i2s;
static float input_buffer[STEREO_BUFFER_SIZE * 2];
static float output_buffer[STEREO_BUFFER_SIZE * 2];
float *inbuffptr = &input_buffer[0];
float *outbuffptr = &output_buffer[0];
static float freeverb_buffer[2];
static float pverb_buffer[2];

// Multi-tap delay element
typedef struct tap_element{
    uint32_t delay;
    float  feedback;
}tap_element;

int get_sign(int32_t value)
{
    return (value & 0x80000000) ? -1 : (int)(value != 0);
}

/**
 * @brief process a buffer of Audio data
 * 
 * Processes Left then Right sample in turn so that,
 * if necessary, different processing can be applied 
 * to each sample.
 * 
 * @param input pointer to the Audio Input buffer
 * @param output pointer to the Audio Output buffer
 * @param num_frames number of L-R samples
 */
static void process_audio(const int32_t* input, int32_t* output, size_t num_frames) {
    size_t tmpIndex;
    int tmpAlgorithm = glbAlgorithm;    //saving it locally prevents it being changed during buffer processing 
    /*
    * Convert to Floats and normalise to -1.0 - +1.0f
    */
    for (size_t i = 0; i < num_frames * 2; i++){
        // Data is 24-Bit left-justified in 32-Bit word
        // so right-shift to get 24-Bits, which sign-extends
        // bit 31 down to bit 23 then normalise to float (-1.0, +1.0)
        input_buffer[i] = (float)(input[i] >> 8) / (float)0x07FFFFF;
        }
    
    /*
    *   Left Channel Sample
    */
    for (size_t i = 0; i < num_frames * 2; i++) {
        float yl,yr,xl,xr;
        // If the delay changes, gradually ramping the actual delay 
        // towards the target delay helps to reduce glitches. 
        if (glbDelay_L < targetDelay_L){
            glbDelay_L++;
        }
        if (glbDelay_L > targetDelay_L){
            glbDelay_L--;
        }
        ReadPointer_L = ((WritePointer + BUF_LEN) - glbDelay_L) % BUF_LEN;
        // We need to read from Memory first, so that an amount of that can
        // added to the incoming sample as Feedback
        union uSample ThisSample;
        union uSample DrySample;
        ThisSample.fSample = input_buffer[i];
        DrySample.fSample = ThisSample.fSample;
        switch(tmpAlgorithm){
            case 0:
                ThisSample.fSample = WetDry(DrySample.fSample,single_tap(ThisSample, glbFeedback, true));
                output_buffer[i] = ThisSample.fSample;
                break;
            case 1:
                ThisSample.fSample = WetDry(DrySample.fSample,Ping_Pong(ThisSample, glbFeedback, true));
                output_buffer[i] = ThisSample.fSample;
                break;
            case 2:
                // BUT delay change only affects Left Channel
                ThisSample.fSample = WetDry(DrySample.fSample,single_tap(ThisSample, glbFeedback, true));
                output_buffer[i] = ThisSample.fSample;
                break;
            case 3:
                // BUT delay change only affects Right Channel
                ThisSample.fSample = WetDry(DrySample.fSample,single_tap(ThisSample, glbFeedback, true));
                output_buffer[i] = ThisSample.fSample;
                break;
            case 4:
                // Pverb = just set left-sample
                pverb_buffer[0] = input_buffer[i];
                tmpIndex = i;                
                break;
            case 5:
                // F = Freeverb = just set left-sample
                psram_write32(&psram_spi, (WritePointer << 3),ThisSample.iSample);  //just to make sure the buffer is OK
                freeverb_buffer[0] = input_buffer[i];
                tmpIndex = i;
                break;
            case 6:
                // G = Gverb!!
                psram_write32(&psram_spi, (WritePointer << 3),ThisSample.iSample);
                xl = input_buffer[i];
                gverb_do(parrot_gverb,xl,&yl,&yr);
                ThisSample.fSample = WetDry(xl,yl);
                output_buffer[i] = ThisSample.fSample;
                break;
            case 7:
                xl = input_buffer[i];
                psram_write32(&psram_spi, (WritePointer << 3),ThisSample.iSample);
                tmpIndex = i;
                break;
            default:
                ThisSample.fSample = single_tap(ThisSample, glbFeedback, true);
                output_buffer[i] = ThisSample.fSample;
                break;
        }
        //ReadPointer_L = ReadPointer_L++ & BUF_LEN;
        /*
        *   Right Channel Sample
        */
        i++;
        if (glbDelay_R < targetDelay_R){
            glbDelay_R++;
        }
        if (glbDelay_R > targetDelay_R){
            glbDelay_R--;
        }
        ReadPointer_R = ((WritePointer + BUF_LEN) - glbDelay_R) % BUF_LEN;
        ThisSample.fSample = input_buffer[i];
        DrySample.fSample = ThisSample.fSample;
        switch(tmpAlgorithm){
            case 0:
                ThisSample.fSample = WetDry(DrySample.fSample,single_tap(ThisSample, glbFeedback, false));
                output_buffer[i] = ThisSample.fSample;
                break;
            case 1:
                ThisSample.fSample = WetDry(DrySample.fSample,Ping_Pong(ThisSample, glbFeedback, false));
                output_buffer[i] = ThisSample.fSample;
                break;
            case 2:
                // BUT delay change only affects Left Channel
                ThisSample.fSample = WetDry(DrySample.fSample,single_tap(ThisSample, glbFeedback, false));
                output_buffer[i] = ThisSample.fSample;
                break;
            case 3:
                // BUT delay change only affects Right Channel
                ThisSample.fSample = WetDry(DrySample.fSample,single_tap(ThisSample, glbFeedback, false));
                output_buffer[i] = ThisSample.fSample;
                break;
            case 4:
                // Pverb!!
                psram_write32(&psram_spi, (WritePointer << 3) + 4,ThisSample.iSample);
                pverb_buffer[1] = input_buffer[i];
                pv_process(&parrot_pverb, &pverb_buffer[0], 1);
                output_buffer[tmpIndex] = pverb_buffer[0];
                output_buffer[i] = pverb_buffer[1];
                break;
            case 5:
                // F = Freeverb!!
                psram_write32(&psram_spi, (WritePointer << 3) + 4,ThisSample.iSample);
                freeverb_buffer[1] = input_buffer[i];
                fv_process(&parrot_freeverb, &freeverb_buffer[0], 1);
                output_buffer[tmpIndex] = freeverb_buffer[0];
                output_buffer[i] = freeverb_buffer[1];
                break;
            case 6:
                // G = Gverb!
                // yr was calculated in Left Channel, so is just output here
                psram_write32(&psram_spi, (WritePointer << 3) + 4,ThisSample.iSample);
                ThisSample.fSample = WetDry(xl,yr);
                output_buffer[i] = ThisSample.fSample;
                break;
            case 7:
                xr = input_buffer[i];
                psram_write32(&psram_spi, (WritePointer << 3) + 4,ThisSample.iSample);
                ThisSample.fSample = WetDry(DrySample.fSample,Euclidean_Delay(glbFeedback));
                output_buffer[tmpIndex] = ThisSample.fSample;
                output_buffer[i] = ThisSample.fSample;
                break;
            default:
                ThisSample.fSample = single_tap(ThisSample, glbFeedback, false);
                output_buffer[i] = ThisSample.fSample;
                break;
            }
        //ReadPointer_R = ReadPointer_R++ & BUF_LEN;
        WritePointer++;
        WritePointer &= BUF_LEN;
    }
    /*
    * Convert back from floats to signed 32-Bit Ints
    */
    for (size_t i = 0; i < num_frames * 2; i++){
        // convert back to 24-Bit signed Integer
        // left-justified in 32-bit integer 
        output[i] = (int32_t)(output_buffer[i] * 0x07FFFFF) << 8;
    }
}
/**
 * @brief I2S Audio input DMA handler
 * 
 * We're double buffering using chained TCBs. By checking which buffer the
 * DMA is currently reading from, we can identify which buffer it has just
 * finished reading (the completion of which has triggered this interrupt).
 * 
 */
static void dma_i2s_in_handler(void) {
    if (*(int32_t**)dma_hw->ch[i2s.dma_ch_in_ctrl].read_addr == i2s.input_buffer) {
        // It is inputting to the second buffer so we can overwrite the first
        process_audio(i2s.input_buffer, i2s.output_buffer, AUDIO_BUFFER_FRAMES);
    } else {
        // It is currently inputting the first buffer, so we write to the second
        process_audio(&i2s.input_buffer[STEREO_BUFFER_SIZE], &i2s.output_buffer[STEREO_BUFFER_SIZE], AUDIO_BUFFER_FRAMES);
    }
    dma_hw->ints0 = 1u << i2s.dma_ch_in_data;  // clear the IRQ
}
/**
 * @brief Check for the Rotary Encoder button push
 * 
 * This zeroes out the entire delay buffer. Saving and disabling
 * interrupts only works for the core you are in, hence why this 
 * is run in parrot_main rather than parrot_core1
 * 
 * Pulling the XSMT (Soft Mute) pin of the PCM5102 DAC low mutes
 * the output whilst this is happening
 */
void checkReset(){
  int thisEncoderSw = !gpio_get(ENCODER_SW);
  if ((int)thisEncoderSw != LatestEncoderSw) {
    LatestEncoderSw = thisEncoderSw;
    EncoderSwChangedTime = time_us_64();
  } else {
    if (time_us_64() >= EncoderSwChangedTime + (DeBounceTime/2)){
      // we can trust this value, so set the global if different
      if (glbEncoderSw != (int)thisEncoderSw) {
        //todo poss protect with spinlocks?
        glbEncoderSw = (int)thisEncoderSw;
        if (glbEncoderSw == 1){
            //printf("Encoder Switch Pressed!\n");
            uint32_t ResetCounter;
            uint32_t InterruptStatus;
            // Mute the output
            gpio_put(XSMT_PIN,0);
            // Save and disable interrupts
            InterruptStatus = save_and_disable_interrupts();
            for(ResetCounter = 0;ResetCounter < BUF_LEN; ResetCounter++){
                psram_write32(&psram_spi, ResetCounter << 3,0x0);
                psram_write32(&psram_spi, (ResetCounter << 3) + 4,0x0);
            }
            glbDelay_L = targetDelay_L; //be done with it!
            glbDelay_R = targetDelay_R; //be done with it!
            // Flush / Mute Gverb & Freeverb
            gverb_flush(parrot_gverb);
            fv_mute(&parrot_freeverb);
            pv_mute(&parrot_pverb);
            restore_interrupts(InterruptStatus);
            // Un-Mute the output
            gpio_put(XSMT_PIN,1);
        } 
      }
    }
  }
}

/**
 * @brief Main program entry point
 */
int main(){
    // Main program entry point
    // Set a 132.000 MHz system clock to more evenly divide the audio frequencies
    //set_sys_clock_khz(132000, true);
    set_sys_clock_khz(280000, true);
    // Serial port initialisation (Using USB for stdio)
    stdio_init_all();
    // Pre-start delay for testing
    for(int i = 1;i <= 20; i++){
      printf("Waiting to start %d\n",20-i);
      sleep_ms(1000);
    }
    for(int i = 1;i <= 20; i++){
        printf("\n",20-i);
    }
      
    // Onboard LED (just in case we use it)
    gpio_init(ONBOARD_LED);
    gpio_set_dir(ONBOARD_LED, GPIO_OUT);
    // Setting gpio 23 high turns off power save mode
    // on the internal SMPS, and keeps it in PWM mode, 
    // which improves noise on the 3v3 rail. 
    gpio_init(POWERSAVE_PIN);
    gpio_set_dir(POWERSAVE_PIN,GPIO_OUT);
    gpio_put(POWERSAVE_PIN,1);

    // PCM 5102 soft mute
    gpio_init(XSMT_PIN);
    gpio_set_dir(XSMT_PIN,GPIO_OUT);
    gpio_put(XSMT_PIN,0);

    /**
     * @brief Initialise the PSRAM SPI interface, which uses pio0
     */
    psram_spi = psram_spi_init(pio0, -1);
    // Claim and initialize a spinlock
    spinlock_num_glbDelay = spin_lock_claim_unused(true) ;
    spinlock_glbDelay = spin_lock_init(spinlock_num_glbDelay) ;
    // Zero out the Audio Buffer
    for(WritePointer = 0;WritePointer < BUF_LEN; WritePointer++){
        psram_write32(&psram_spi, WritePointer << 3,0x0);
        psram_write32(&psram_spi, (WritePointer << 3)+4,0x0);
    }
    // Give the Write Pointer a head start & set the 
    // target delays
    ReadPointer_L = 0;
    ReadPointer_R = 0;
    WritePointer = 0;
    targetDelay_L = 0;
    targetDelay_R = 0;
    glbDelay_L = 0;
    glbDelay_R = 0;
    ExtClockPeriod = 48000;
    glbEuclideanFill = 1;
    glbEncoderSw = 0;
    LatestEncoderSw = 0;
    EncoderSwChangedTime = time_us_64();

    size_t initial_space = get_free_ram();
    printf("Initial free RAM: %d\n",initial_space);
    /**
     * @brief instantiate a gverb instance
     * @param int srate, 
     * @param float maxroomsize, 
     * @param float roomsize,
	 * @param float revtime,
	 * @param float damping, 
     * @param float spread,
	 * @param float inputbandwidth, 
     * @param float earlylevel,
	 * @param float taillevel
     */
    parrot_gverb = gverb_new(48000.f, 41.f, 40.f, 7.0f, 0.5f, 0.5f, 0.5f, 0.5f, 0.5f);

    size_t space1 = get_free_ram();
    printf("RAM used by gverb: %d\n",initial_space - space1);
    /**
     * @brief instantiate a freeverb instance
     * 
     */
    fv_init(&parrot_freeverb);
    size_t space2 = get_free_ram();
    printf("RAM used by freeverb: %d\n",space1 - space2);
    printf("Free RAM remaining: %d\n",space2);
    /**
     * @brief instantiate a pverb instance
     */
    pv_init(&parrot_pverb);
    size_t space3 = get_free_ram();
    printf("RAM used by pverb: %d\n",space2 - space3);
    printf("Free RAM remaining: %d\n",space3);
    
    /**
     * @brief Start the Audio I2S interface, which uses pio1
     */
    i2s_program_start_synched(pio1, &i2s_config_default, dma_i2s_in_handler, &i2s);
    // Un-mute the output
    gpio_put(XSMT_PIN,1);

    // Launch core 1
    multicore_launch_core1(core1_entry);

    // Do nothing for now, but we need to utilise this core
    // to do something useful
    while(1){
        // check the panic button (encoder switch)
        checkReset();
        tight_loop_contents();
    }

}

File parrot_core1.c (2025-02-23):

/******************************************************************************

The Camberwell Parrot

Copyright © 2024 Richard R. Goodwin / Audio Morphology Ltd.

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
******************************************************************************/
/**
 * @file parrot_core1.c
 * 
 * Contains all functions that run on the second core of the Pico (Core1)
 * These are primarily the internal and external clock routines and the 
 * less time-critical user interface routines
 * 
 * In general global variables are set by routines in parrot_core1, then read
 * and acted upon by the time-critical functions in parrot_main
 */
#include <stdio.h>
#include <arm_math.h>
#include "parrot.h"
#include "pico/stdlib.h"
#include "pico/multicore.h"
#include "hardware/irq.h"
#include "hardware/adc.h"
#include "hardware/sync.h"

bool temp = false;

double ClockBPM;                  // BPM Value for interal clock
double ClockFreq;                 // Internal Clock Frequency
double ClockPeriod;               // Internal Clock Period
int ClockPhase;                   // Toggles between 0 & 1 
int LEDPhase;                     // on-board LED - Toggles between 0 & 1 
int LatestDivisor;                  // Temp value of the mul/div switch if it changes
uint64_t DivisorChangedTime;        // Time at which the switch last changed value (for debouncing)
int LatestAlgorithm = 0;            // latest value for the Algorithm Switch that may or may not be the same as glbAlgorithm
uint64_t AlgorithmChangedTime;      // Time at which the Algorithm Switch changed

_Atomic int32_t ExtClockPeriod;   // External Clock Period (rising edge to rising edge)
_Atomic int32_t ExtClockTick;     // Records the last tick for the External Clock
uint SyncFree;                    // Delay time is just controlled by Rotary Encoder, or sync'd to external/internal clock
uint16_t Feedback_MA[16];         // 16-byte moving average buffer for feedback pot. NOTE: statically defined length. We'll not use all 16 elements.
uint Feedback_MA_Ptr;             // Pointer to Moving Average buffer
uint16_t Feedback_Average;        // Moving average result
long Feedback_MA_Sum;             // Running total of the values in the buffer
uint16_t  Clock_MA[16];           // Clock input Moving Average buffer
uint Clock_MA_Ptr;
uint16_t Clock_Average;
long Clock_MA_Sum;
uint16_t  WetDry_MA[16];          // We/Dry input Moving Average buffer
uint WetDry_MA_Ptr;
uint16_t WetDry_Average;
long WetDry_MA_Sum;
uint32_t  ExtClock_MA[16];        // External Clock input Moving Average buffer
uint ExtClock_MA_Ptr;
uint32_t ExtClock_Average;
long ExtClock_MA_Sum;
uint8_t lrmem = 3;
int lrsum = 0;
// Rotary encoder state transition table
int8_t TRANS[] = {0, -1, 1, 14, 1, 0, 14, -1, -1, 14, 0, 1, 14, 1, -1, 0};


/***********************
 * Function Definitions
 ***********************/
/**
 * @brief Rotary Encoder finite state machine
 * 
 * This comes from a technical paper by Marko Pinteric
 * https://www.pinteric.com/rotary.html, with additions
 * by Ralph S. Bacon
 * https://github.com/RalphBacon/226-Better-Rotary-Encoder---no-switch-bounce
 */
int8_t checkRotaryEncoder()
{
    // Read BOTH pin states to deterimine validity of rotation (ie not just switch bounce)
    int8_t l = gpio_get(ENCODERA_IN);
    int8_t r = gpio_get(ENCODERB_IN);
    // Move previous value 2 bits to the left and add in our new values
    lrmem = ((lrmem & 0x03) << 2) + 2 * l + r;
    // Convert the bit pattern to a movement indicator (14 = impossible, ie switch bounce)
    lrsum += TRANS[lrmem];
    /* encoder not in the neutral (detent) state */
    if (lrsum % 4 != 0){
        return 0;
    }
    /* encoder in the neutral state - clockwise rotation*/
    if (lrsum == 4){
        lrsum = 0;
        return 1;
    }
    /* encoder in the neutral state - anti-clockwise rotation*/
    if (lrsum == -4){
        lrsum = 0;
        return -1;
    }
    // An impossible rotation has been detected - ignore the movement
    lrsum = 0;
    return 0;
}

/**
 * @brief Rotary Encoder IRQ callback
 * 
 * In Free-running mode (ie sync'd to the internal or external clock)
 * this increases or decreases the targetDelay, which is the delay that
 * the glbDelay value is aiming for, but ony moving towards by one sample
 * at a time.
 * 
 * The larger the target delay, the larger the increment and
 * therefore the lower the resolution
 */
void encoder_IRQ_handler(uint gpio,uint32_t events){
  int8_t dir = checkRotaryEncoder();
    if (dir != 0){
      //Update the Euclidean Fill value, which cannot
      //be greater than the number of steps. OR less
      //than 1.
      if (dir == 1) {
      glbEuclideanFill++;
      if (glbEuclideanFill > EuclideanSteps[glbDivisor]) {
          glbEuclideanFill = EuclideanSteps[glbDivisor];
        }
      }
      else {
        glbEuclideanFill--;
        if (glbEuclideanFill < 1) {
          glbEuclideanFill = 1;
        }
      } 
      unsigned int retval = bjorklund(EuclideanSteps[glbDivisor],glbEuclideanFill);
      printf("Steps: %d, Hits: %d, RetVal:"WORD16_PATTERN"\n",EuclideanSteps[glbDivisor],glbEuclideanFill,WORD16_TO_BINARY(retval));
      //note the 'hits' within the EuclideanHits array
      //clear it out first
      for(int i=0; i<16; i++) {EuclideanHits[i]=0;}
      //Then set each 'hit' according to the retval bit patters
      for(int i=0;i<EuclideanSteps[glbDivisor];i++){
        EuclideanHits[i] = bitRead(retval,(EuclideanSteps[glbDivisor]-i)-1);
      } 
      for(int i=0;i<EuclideanSteps[glbDivisor];i++){
        printf("%d",EuclideanHits[i]);
      }
      printf("\n");
    // Only alter the delay if we're free-running
    if (SyncFree == 0){
      // Increment depends on the current increment value
      // TODO: probably play with these thresholds and
      // increments to arrive at something meaningful
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

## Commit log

2024-12-28 Initial commit of Rev2
    [Adafruit MPM3610.brd, Adafruit MPM3610.sch, Analog_IO.kicad_sch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]
2024-12-29 Rev 2 schematic & circuit board
    [Analog_IO.kicad_sch, UI_Board.kicad_sch, interconnect.kicad_sch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]
2025-01-14 Software switch de-bounce added as a result of Rev 2 testing.
    [Front Panel Holes.ods, Rev2_Bom.csv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]
2025-01-14 Final Rev 2 hardware checks, adjusting the sync/free settings so that when switched to free-running the glbDelay isn't altered
2025-01-15 Changes to CMakeLists.txt to build and link the latest CMSIS Library. At present this seems to have broken support for the RP2040, so I may just have to live with that fact.
    [parrot_main.c]
2025-01-21 Rev 2.1 hardware changes
    [panel.kicad_pcb, pcb.kicad_pcb]
2025-01-23 Worked through the uint32_t to normalised float conversion by using the audio test harness to print out the binary respresentation
2025-01-30 Integrated gverb into the main Camberwell Parrot codebase on Algorithm Switch G, with Wet/Dry balance and Feedback setting the reverb time

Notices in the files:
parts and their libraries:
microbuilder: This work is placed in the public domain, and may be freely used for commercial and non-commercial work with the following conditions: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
